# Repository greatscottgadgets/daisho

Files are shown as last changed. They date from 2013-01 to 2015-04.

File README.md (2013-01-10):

Daisho
======

Daisho is a SuperSpeed USB 3.0 FPGA platform.  The Daisho Platform is intended
for operation as a pair of components:

A mainboard with an FPGA can connect to a back-end computer via SuperSpeed USB.

A front-end board for a particular application connects to the mainboard via a
high speed parallel connector.

Front-end boards are planned that enable in-line monitoring and injection for
high speed wired communication media.

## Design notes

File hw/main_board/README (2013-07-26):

Copyright (c) 2013 Jared Boone, ShareBrained Technology, Inc.

These files are part of Daisho.

License
=======

This is a free hardware design; you can redistribute it and/or modify
it under the terms of the GNU General Public License as published by
the Free Software Foundation; either version 2, or (at your option)
any later version.

This design is distributed in the hope that it will be useful,
but WITHOUT ANY WARRANTY; without even the implied warranty of
MERCHANTABILITY or FITNESS FOR A PARTICULAR PURPOSE.  See the
GNU General Public License for more details.

You should have received a copy of the GNU General Public License
along with this design; see the file COPYING.  If not, write to
the Free Software Foundation, Inc., 51 Franklin Street,
Boston, MA 02110-1301, USA.

Hardware Notes
==============

Schematic and layout files were designed in KiCad (release 2012-05-21
bzr 3261 -stable), an open source electronic design automation package.

Order and type of copper layers:
    1_top: signal, front ("component" side, where most components are mounted)
    2_gnd: ground plane
    3_inner: signal
    4_gnd: ground plane
    5_pwr: power plane
    6_inner: signal
    7_gnd: ground plane
    8_bot: signal, back

PCB description: 8 layer PCB, 60 mil +/- 5% thickness
    LPI mask          0.4 mil
    Plating           1.2 mil   1.0 oz
    Copper      1     0.7 mil   0.5 oz
    Dielectric  1-2   4.4 mil   prepreg, 2 x 106-FR4 370
    Copper      2     1.2 mil   1.0 oz
    Dielectric  2-3   8.0 mil   core, FR4 370
    Copper      3     1.2 mil   1.0 oz
    Dielectric  3-4   7.8 mil   prepreg, 3 x 1080-FR4 370
    Copper      4     1.2 mil   1.0 oz
    Dielectric  4-5   8.0 mil   core, FR4 370
    Copper      5     1.2 mil   1.0 oz
    Dielectric  5-6   7.8 mil   prepreg, 3 x 1080-FR4 370
    Copper      6     1.2 mil   1.0 oz
    Dielectric  6-7   8.0 mil   core, FR4 370
    Copper      7     1.2 mil   1.0 oz
    Dielectric  7-8   4.4 mil   prepreg, 2 x 106-FR4 370
    Copper      8     0.7 mil   0.5 oz
    Plating           1.2 mil   1.0 oz
    LPI mask          0.4 mil

Impedance goals:
    50 Ohm +/- 10% microstrip, layers 1:2 at 7.0 mil (0.178 mm) width
    50 Ohm +/- 10% offset stripline, layers 3:2 at 6.5 mil (0.165 mm) width
    50 Ohm +/- 10% offset stripline, layers 6:7 at 6.5 mil (0.165 mm) width
    50 Ohm +/- 10% microstrip, layers 8:7 at 7.0 mil (0.178 mm) width

Soldermask
==========
Double side solder mask green
    +/- 5 mil solder mask registration

Silkscreen
==========
Double side silkscreen white
    6 mil silkscreen minimum width
    Silkscreen must be clipped by soldermask

Traces
======
5 mil (0.127 mm) min trace width
5 mil (0.127 mm) min trace isolation

Vias
====
8 mil (0.2032 mm) min via drill
17.7 mil (0.45 mm) min via pad
    4.85 mil min annular ring

Via-in-pad used in many places

Vias in pads need to be filled for assembly
    Most vias in pads are in capacitor footprints near the 780-BGA and 175-BGA

Drills
======
Drills are specified in two files:
    main_board.drl contains plated drills.
    main_board-NPTH.drl contains non-plated drills.

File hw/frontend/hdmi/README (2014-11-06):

Copyright (c) 2014 Michael Ossmann, Mike Kershaw, Jared Boone

These files are part of Daisho.

License
=======

This is a free hardware design; you can redistribute it and/or modify
it under the terms of the GNU General Public License as published by
the Free Software Foundation; either version 2, or (at your option)
any later version.

This design is distributed in the hope that it will be useful,
but WITHOUT ANY WARRANTY; without even the implied warranty of
MERCHANTABILITY or FITNESS FOR A PARTICULAR PURPOSE.  See the
GNU General Public License for more details.

You should have received a copy of the GNU General Public License
along with this design; see the file COPYING.  If not, write to
the Free Software Foundation, Inc., 51 Franklin Street,
Boston, MA 02110-1301, USA.

Hardware Notes
==============

Schematic and layout files were designed in KiCad (release 2014-10-14
bzr 5188 -product), an open source electronic design automation package.

Order and type of copper layers:
    C1F: signal, front ("component" side, where most components are mounted)
    C2: ground plane
    C3: signal
    C4: signal
    C5: ground plane
    C6B: signal, back (a few components mounted, mostly small passives)

PCB description:

    6 layer PCB, 62 mil +/- 5% thickness, using 8 layer construction

    LPI mask          0.4 mil
    Plating           1.2 mil   1.0 oz
    Copper      1     0.7 mil   0.5 oz
    Dielectric  1-2   4.4 mil   prepreg, 2 x 106-FR4 370
    Copper      2     1.2 mil   1.0 oz
    Dielectric  2-3   6.0 mil   core, FR4 370
    Copper      3     1.2 mil   1.0 oz
    Dielectric  3-4   8.1 mil   prepreg, 3 x 1080-FR4 370
                3-4  14.5 mil   core, FR4 370
                3-4   8.1 mil   prepreg, 3 x 1080-FR4 370
    Copper      4     1.2 mil   1.0 oz
    Dielectric  4-5   6.0 mil   core, FR4 370
    Copper      5     1.2 mil   1.0 oz
    Dielectric  5-6   4.4 mil   prepreg, 2 x 106-FR4 370
    Copper      6     0.7 mil   0.5 oz
    Plating           1.2 mil   1.0 oz
    LPI mask          0.4 mil

Impedance Goals
===============

50 Ohm +/- 10% microstrip, layers 1:2 and 6:5 at 0.178 mm (7.0 mil) width

100 Ohm +/- 10% differential microstrip, layers 1:2 and 6:5 at 0.127 mm (5.0 mil) width, 0.127 mm (8.0 mil) separation

Soldermask
==========

Double side solder mask green
    +/- 5 mil solder mask registration

Silkscreen
==========

Double side silkscreen white
    6 mil silkscreen minimum width
    Silkscreen must be clipped by soldermask

Traces
======

5 mil (0.127 mm) min trace width
5 mil (0.127 mm) min trace isolation

Vias
====

8 mil (0.2032 mm) min via drill
17.7 mil (0.45 mm) min via pad
    4.85 mil min annular ring

Via-in-pad used in many places

Vias in pads need to be filled for assembly
    All vias in pads are in capacitor footprints near the BGA

Drills
======

Drills are specified in two files:
    hdmi.drl contains plated drills.
    hdmi-NPTH.drl contains non-plated drills.

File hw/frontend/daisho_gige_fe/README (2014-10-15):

Copyright 2014 Mike Kershaw, Michael Ossmann

These files are part of HackRF.

This is a free hardware design; you can redistribute it and/or modify
it under the terms of the GNU General Public License as published by
the Free Software Foundation; either version 2, or (at your option)
any later version.

This design is distributed in the hope that it will be useful,
but WITHOUT ANY WARRANTY; without even the implied warranty of
MERCHANTABILITY or FITNESS FOR A PARTICULAR PURPOSE.  See the
GNU General Public License for more details.

You should have received a copy of the GNU General Public License
along with this design; see the file COPYING.  If not, write to
the Free Software Foundation, Inc., 51 Franklin Street,
Boston, MA 02110-1301, USA.

hardware notes:

Schematic and layout files were designed in KiCad, an open source electronic
design automation package.

order of copper layers:
    Copper 1:  C1F (front)
    Copper 2:  C2
    Copper 3:  C3
    Copper 4:  C1B (back)

PCB description: 4 layer PCB 0.0646 in
    Copper       1:  1 oz copper (1.4 mil)
    Dielectric 1-2:  6.7 mil prepreg
    Copper       2:  0.5 oz copper (0.7 mil)
    Dielectric 2-3:  47 mil core
    Copper       3:  0.5 oz copper (0.7 mil)
    Dielectric 3-4:  6.7 mil prepreg
    Copper       4:  1 oz copper (1.4 mil)

FR408 or similar substrate with Er=3.66 (+/- 0.1)
double side solder mask green
double side silkscreen white
6 mil min trace width and
6 mil min isolation
10 mil min drill

PCBs of this specification are available from OSH Park.

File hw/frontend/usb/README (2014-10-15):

Copyright (c) 2014 Jared Boone, ShareBrained Technology, Inc.

These files are part of Daisho.

License
=======

This is a free hardware design; you can redistribute it and/or modify
it under the terms of the GNU General Public License as published by
the Free Software Foundation; either version 2, or (at your option)
any later version.

This design is distributed in the hope that it will be useful,
but WITHOUT ANY WARRANTY; without even the implied warranty of
MERCHANTABILITY or FITNESS FOR A PARTICULAR PURPOSE.  See the
GNU General Public License for more details.

You should have received a copy of the GNU General Public License
along with this design; see the file COPYING.  If not, write to
the Free Software Foundation, Inc., 51 Franklin Street,
Boston, MA 02110-1301, USA.

Hardware Notes
==============

Schematic and layout files were designed in KiCad (release 2014-09-15
bzr 5135 -product), an open source electronic design automation package.

Order and type of copper layers:
    1_top: signal, front ("component" side, where most components are mounted)
    2: ground plane
    3: signal
    4: signal
    5: ground plane
    6_bot: signal, back (a few components mounted, mostly small passives)

PCB description:

    6 layer PCB, 62 mil +/- 5% thickness, using 8 layer construction

    LPI mask          0.4 mil
    Plating           1.2 mil   1.0 oz
    Copper      1     0.7 mil   0.5 oz
    Dielectric  1-2   4.4 mil   prepreg, 2 x 106-FR4 370
    Copper      2     1.2 mil   1.0 oz
    Dielectric  2-3   6.0 mil   core, FR4 370
    Copper      3     1.2 mil   1.0 oz
    Dielectric  3-4   8.1 mil   prepreg, 3 x 1080-FR4 370
                3-4  14.5 mil   core, FR4 370
                3-4   8.1 mil   prepreg, 3 x 1080-FR4 370
    Copper      4     1.2 mil   1.0 oz
    Dielectric  4-5   6.0 mil   core, FR4 370
    Copper      5     1.2 mil   1.0 oz
    Dielectric  5-6   4.4 mil   prepreg, 2 x 106-FR4 370
    Copper      6     0.7 mil   0.5 oz
    Plating           1.2 mil   1.0 oz
    LPI mask          0.4 mil

Impedance Goals
===============

50 Ohm +/- 10% microstrip, layers 1:2 and 6:5 at 0.178 mm (7.0 mil) width

50 Ohm +/- 10% offset stripline, layers 3:2 and 4:5 at 0.165 mm (6.5 mil) width

90 Ohm +/- 10% differential microstrip, layers 1:2 and 6:5 at 0.127 mm (5.0 mil) width, 0.127 mm (5.0 mil) separation

Soldermask
==========

Double side solder mask green
    +/- 5 mil solder mask registration

Silkscreen
==========

Double side silkscreen white
    6 mil silkscreen minimum width
    Silkscreen must be clipped by soldermask

Traces
======

5 mil (0.127 mm) min trace width
5 mil (0.127 mm) min trace isolation

Vias
====

8 mil (0.2032 mm) min via drill
17.7 mil (0.45 mm) min via pad
    4.85 mil min annular ring

Via-in-pad used in many places

Vias in pads need to be filled for assembly
    Most (all?) vias in pads are in capacitor footprints near the two 175-BGAs

Drills
======

Drills are specified in two files:
    usb_drill.xln contains plated drills.
    usb_drill_npth.xln contains non-plated drills.

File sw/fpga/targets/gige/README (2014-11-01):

This is the 1000BASE-T tapping module for the Daisho development board.

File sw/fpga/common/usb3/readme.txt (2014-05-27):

USB 3.0 Device Controller Core
------------------------------

Copyright (c) 2012-2014 Marshall H. All rights reserved.
Code in this folder is released under the terms of the simplified BSD license. 
See LICENSE.TXT for details.

Part of the Daisho project, by Michael Ossmann. http://greatscottgadgets.com/

Revision 0.1, 06/01/14
--------------------------------------------------------------------------------

Overview
--------

This is a device-side controller. This means you can use it to implement a
device talking to a host, whether it be a PC, smartphone, embedded platform...

The controller supports both USB 3.0 (5.0Gbps) and USB 2.0 (480Mbps) operation.
During enumeration if a SuperSpeed receiver is not detected, it will fall
back to 2.0 operation. 

Written in Verilog-2001, it aims to be somewhat easily adaptable to other
devices. It handles PHY strapping and initialization, LFPS with partner, link
training and receiver equalization, link layer data scrambling, elastic buffer
management, device enumeration, and block data transfer.

If you don't know anything about USB, you will have a rough time. If you have 
no experience with FPGAs, you will suffer even more. Read the USB 2.0 spec 
overview, then read about USB 3.0 functionality and how they are incorporated
into each other. Be familiar with the PHY you will use.

Capabilities
------------

The following transfer modes are supported in USB 2.0:
 - Control (intrinsic)
 - Bulk
 - Interrupt
 - Isochronous

And in USB 3.0 mode:
 - Control, Link management
 - Bulk

By default, both controllers implement one BULK IN and one BULK OUT endpoint
in addition to the default Endpoint0 for control transfers.
Additional endpoints may be added with some rework of the protocol layers.

Setting the endpoints to different transfer modes requires editing of the RTL
and also the device descriptors. Consult the USB specifications or your 
favorite search engine for details on the descriptors.

Limitations
-----------

Does not implement the following USB 2.0 functionality:
 - Power saving via SuspendM bit in ULPI
 - Low speed (1.5Mbps) is unimplemented
 - Full speed (11Mbps) is unsupported, but may work

Does not implement the following USB 3.0 functionality:
 - Compliance testing mode
 - Loopback BERT
 - Assertion of disabled data scrambling
 - Tolerance of link command glitches
 - Stream transfer mode

Details:
1. USB devices operating via the 2.0 connection should enter suspend when 
   not transmitting any data on the bus for over 3.0ms. After a total of 10ms 
   have passed, it may not draw more than the rated suspend-mode 
   current instead of the normal current draw.
   This is normally entered when the host stops sending StartOfFrame packets 
   and allows this idle condition. Due to the target platform's fixed current 
   draw this is not an option that can be supported.
2. For compliance testing, the USB 3.0 LTSSM should support a special 
   Compliance state that is entered under certain conditions detailed in the 
   USB specification, for PHY characterization. This mode is not implemented.
3. Also, USB 3.0 Loopback mode is used for benchmarking the bit error rate of
   a connection. As this is not used under normal operation, it is omitted to
   save device resources.
4. During link training, one partner may choose to signal it wishes to disable
   data scrambling. The other partner should signal its acknowledgement in the
   next training sequence. This is supported but basically untested.
5. Per the specification, link commands (which are 4 consecutive, redundant
   K-symbols) can have up to 1 invalid symbol and still be considered valid.
   To simplify functionality the controller will simply ignore these and 
   cause a sequence error. Because the protocol is robust anyway, these will
   at most cause a small performance blip in adverse environments (poor
   cabling, bad connectors, etc)
6. Streams are unsupported, if you need them in your application you are
   exceeding the expected use case

Implementation Results
----------------------

Logic utilization: 
    Approx. 1100 LEs for USB 2.0
    Approx. 6300 LEs for USB 3.0
    1 PLL
    ~40 DDR I/O
    8-10Kbyte distributed block RAM (flexible)

Targeted PHY:
    Texas Instruments TUSB1310A SuperSpeed PHY

Targeted FPGA:
    Altera Cyclone IV EP4CE30 speed grade 8

Build system:
    Altera Quartus II 13.1sp1

Porting Notes
-------------

This controller relies upon several vendor and family-specific features such as
PLLs, pipelined DDR I/O, distributed block RAM, and so on. 
Altera calls these "Megafunctions" and they are denoted by "mf_*.v" filenames.

If you are going to port this to Xilinx, Lattice, silicon then you will want to
blow these away and use the vendor's equivalent tools to get the same result.

I would recommend that you download Quartus and use the Megawizard Plug-in 
Manager to open these files so that you can see how they are supposed to work,
and how you would write wrappers for slightly different device functionality.

You're on your own here, this is not something I would recommend to an FPGA
newcomer (though arguably using this core itself is not trivial.)

Usage Considerations
--------------------

There are a number of design decisions and small things that may affect your
success using the code.

1. Device descriptors
   When running the core with only USB 2.0, edit the device descriptors so that
   the "bcdDevice" entry denotes 200h instead of 210h. The latter indicates the
   device has latent SuperSpeed functionality.
   And obviously, if you want to change the enumerated display name you'll want
   to change these. They must always match the RTL endpoint configuration.

2. I/O constraints
   It's your responsibility to constrain the top level I/O to meet your PCB
   layout. Consult your PHY datasheet, and read FPGA vendor datasheets. 
   PIPE bus I/O is fast enough that timing driven synthesis is recommended

3. SSRX/TX polarity
   The core can tell when the RX data pair has its polarity swapped and will
   configure the PHY accordingly during link training. You can swap either TX
   or RX pairs for more convenient PCB routing. Consult your PHY documentation.

4. Reset
   To reset the core to its power-on state, assert reset for at least a few
   hundred cycles (around 10 uS would be a safe bet.). Additionally, your PHY
   chip may have its own requirements for this. Reset for whichever duration is
   longest.

Troubleshooting
---------------

It's highly unlikely that things will work properly the first time. You would
be well advised to buy/lease/borrow a competent protocol analyzer. Units are
available from the major vendors, which include:

  - Teledyne Lecroy
  - Agilent
  - Tektronix
  - Total Phase

The Beagle 5000v2 from Total Phase was used for the core's development. It
runs about $5-6k. Additionally, the Lecroy Voyagyer M3x was used to test
compliance cases to identify rare problems.
Other vendors provide add-on packages for their higher end scopes, but if 
you could afford those, you'd be licensing a USB core from DesignWare 
anyhow. :)
If you have access to proper verification IP you'd probably want to test this
core against it. I welcome any changes that will make the core more robust.

If you have some knowledge of the protocols you can trigger on the RTL with
Chipscope, Signaltap, Reveal, et al. This will only give you a very narrow
window but it's better than nothing.

Contact
-------

I do not provide support! I will not answer STUPID questions or ones that
make it clear you are going to be wasting not only your own time but mine too.

Bugfixes are welcome if you can clearly demonstrate what is fixed and that no
regressions are caused.

If you successfully implement the core and ship a product I would appreciate
sending an email to let me know it worked.

usb3ipcore, at outlookdotcom

EOF

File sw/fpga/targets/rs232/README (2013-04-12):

This is the RS232 tapping module for the Daisho development board.

In order to use the USB core you must add the common/usb3 directory to the
"Project Libraries" section of the project settings dialog in Quartus II.
(This should work by default if this is checked out from github)

This is *VERY* early in the development phase - it doesn't even tap the lines.

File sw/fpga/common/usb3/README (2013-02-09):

Daisho USB Core

This is an open source USB 3.0 core.  It can be used to implement a USB device
on an FPGA with a USB 3.0 transceiver such as the TUSB1310A.  It can also
operate in USB 2.0 mode with a ULPI transceiver.

This core is being developed for the Altera Cyclone IV.  Operation on other
FPGA platforms may be possible with some work.

Planned functionality includes device (not host) operation in USB 2.0 and 3.0
(including SuperSpeed) modes.

The core is part of Project Daisho but may be used on other platforms.

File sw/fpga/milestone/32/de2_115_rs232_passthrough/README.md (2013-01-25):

Daisho Milestone 32
===================

Demonstrate RS-232 pass-through using the Terasic DE2-115 FPGA development
board and HSMC communication board.

"The platform and RS-232 front-end connected in-line with a target RS-232
link should operate in a pass-through mode such that the link functions as
it would without the platform in place."

Requirements
============

* Altera Quartus II Web Edition 12.1
* Terasic DE2-115 FPGA development board
* Terasic(?) HSMC communication board

Connections
===========

Two RS-232 DB-9 connectors are utilized:

* J6 "RS-232" on the DE2-115 board
* J3 "RS232 (0)" on the HSMC communication board

Beware that the TX and RX pinouts are different between the two connectors.

Indications
===========

Four LEDs on the DE2-115 are used to show data present on the connectors:

* LEDG0: HSMC RXD (input from external device)
* LEDG1: DE2-115 TXD (output to external device)
* LEDG2: HSMC TXD (output to external device)
* LEDG3: DE2-115 RXD (input from external device)

LEDs LEDG0 and LEDG1 should blink in unison, and LEDs LEDG2 and LEDG3 should
blink in unison.

The DE2-115 also has RXD1 and TXD1 LEDs near J6 "RS-232" that indicate data
present on the RS-232 connector.

License
=======

This sub-project is part of the Daisho project.

This program is free software; you can redistribute it and/or
modify it under the terms of the GNU General Public License
as published by the Free Software Foundation; either version 2
of the License, or (at your option) any later version.

This program is distributed in the hope that it will be useful,
but WITHOUT ANY WARRANTY; without even the implied warranty of
MERCHANTABILITY or FITNESS FOR A PARTICULAR PURPOSE.  See the
GNU General Public License for more details.

You should have received a copy of the GNU General Public License
along with this program; if not, write to the Free Software
Foundation, Inc., 51 Franklin Street, Fifth Floor, Boston, MA  02110-1301, USA.

Contact
=======

The latest version of this repository can be found at
https://github.com/mossmann/daisho

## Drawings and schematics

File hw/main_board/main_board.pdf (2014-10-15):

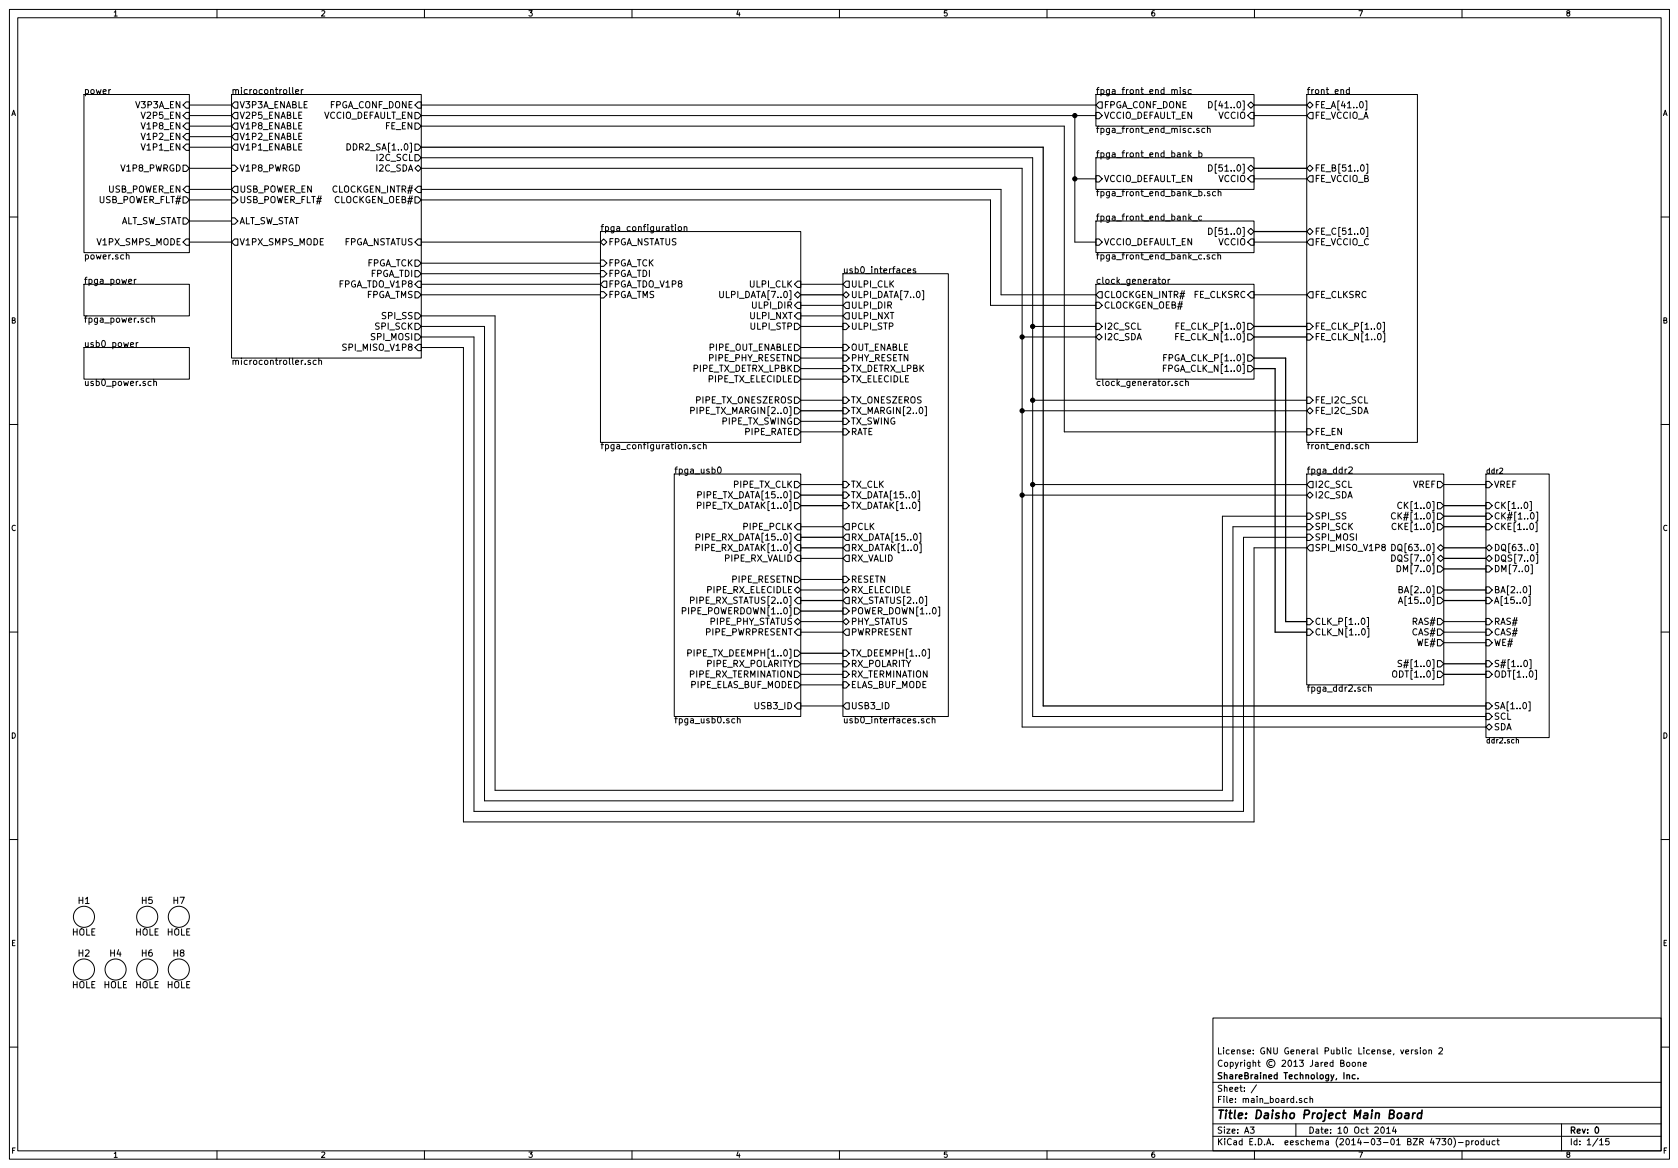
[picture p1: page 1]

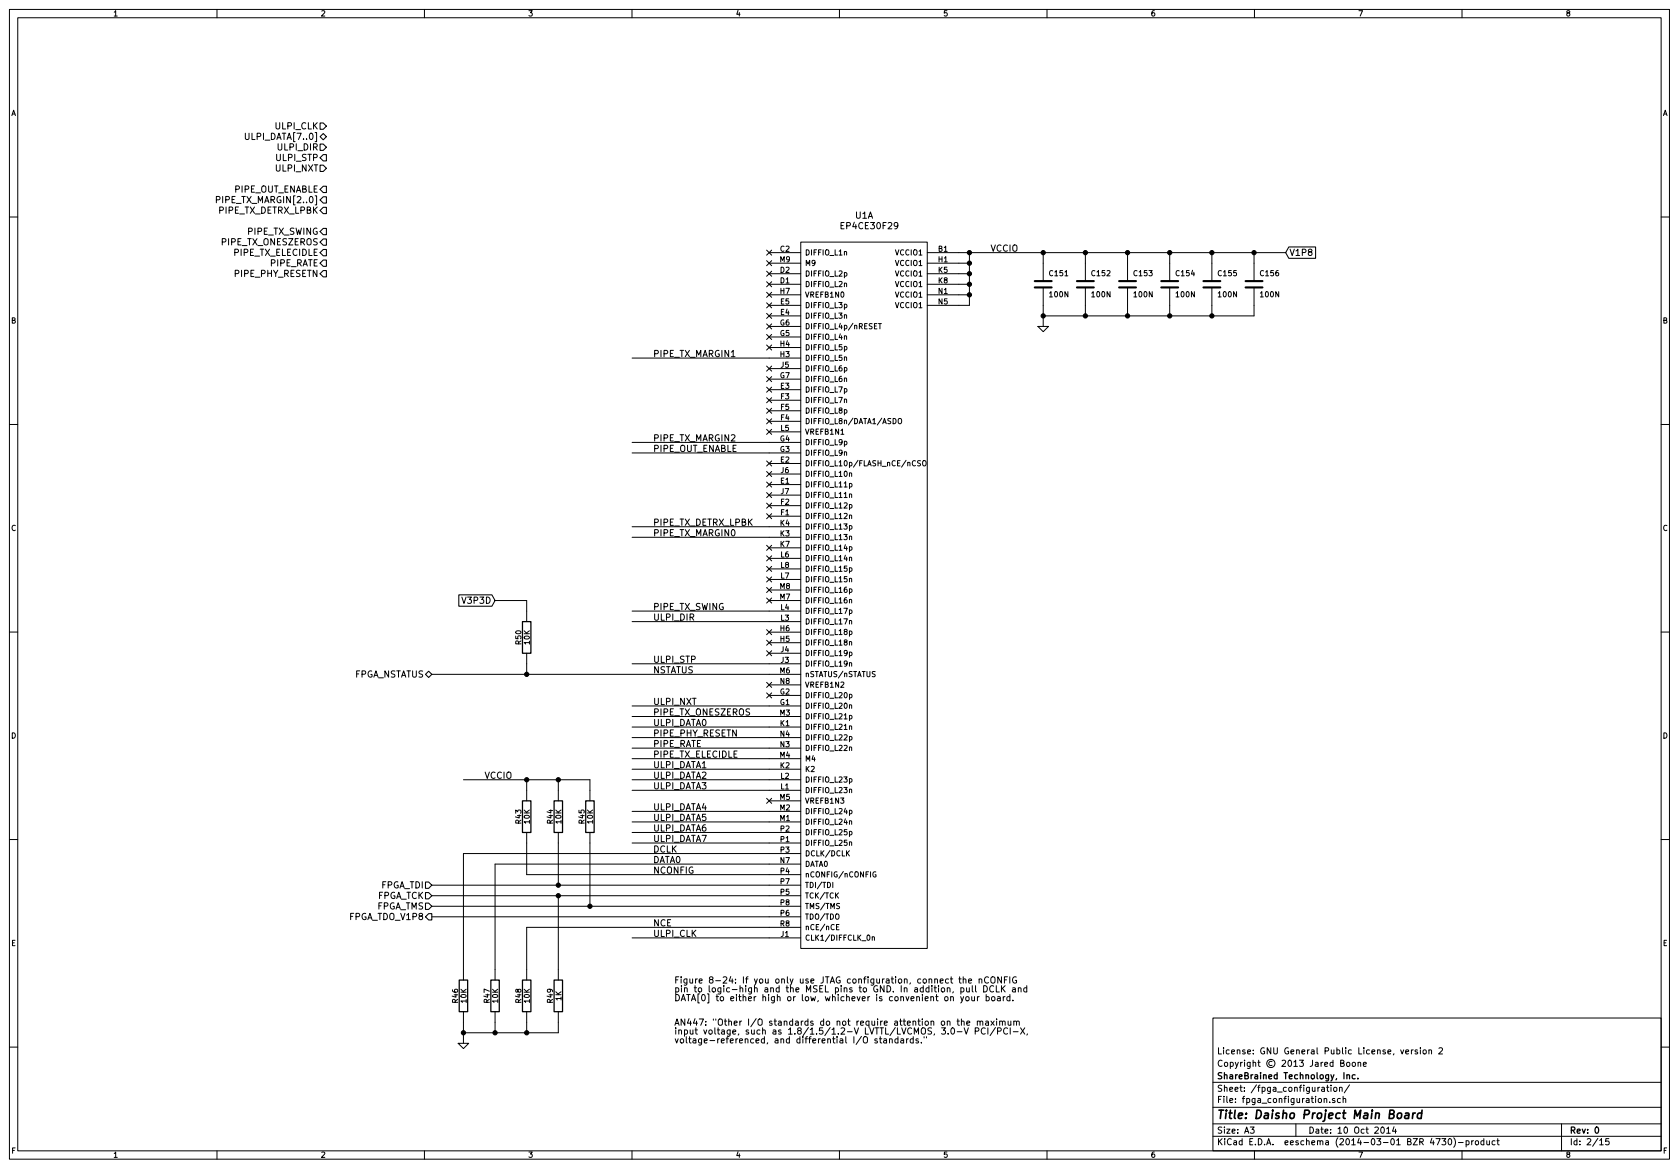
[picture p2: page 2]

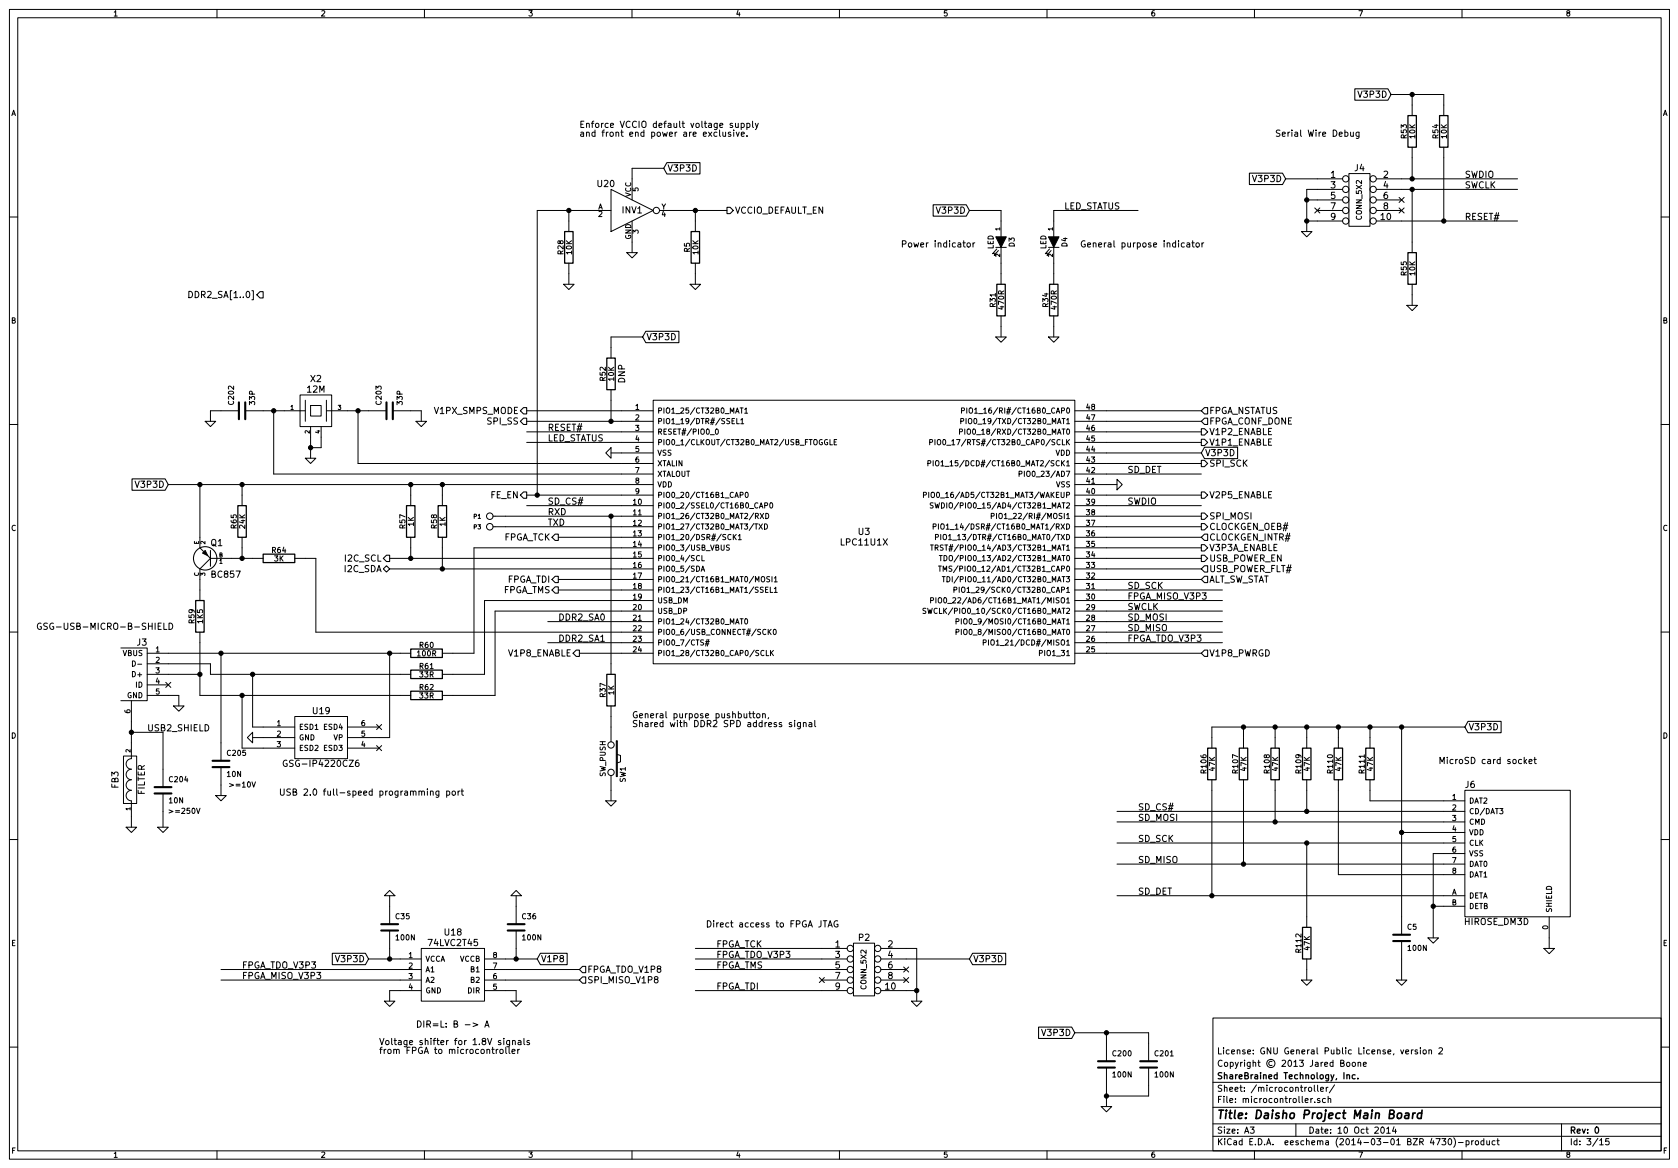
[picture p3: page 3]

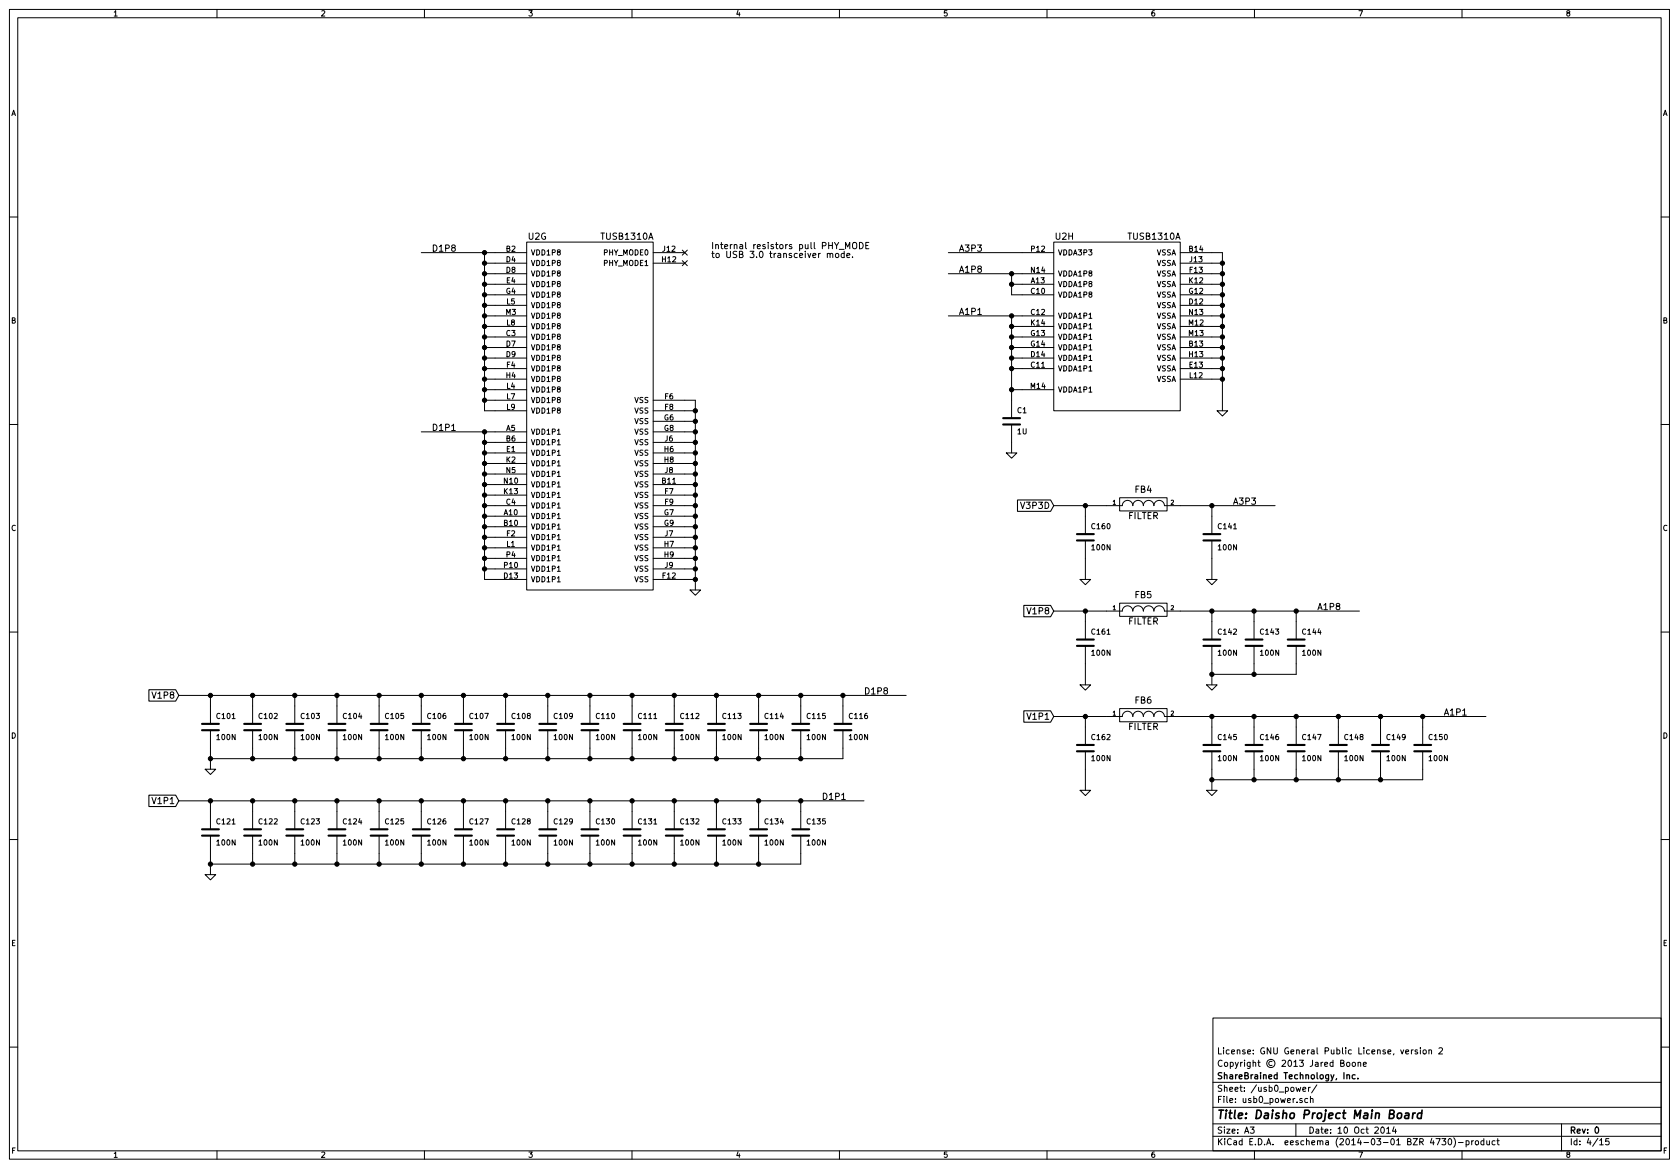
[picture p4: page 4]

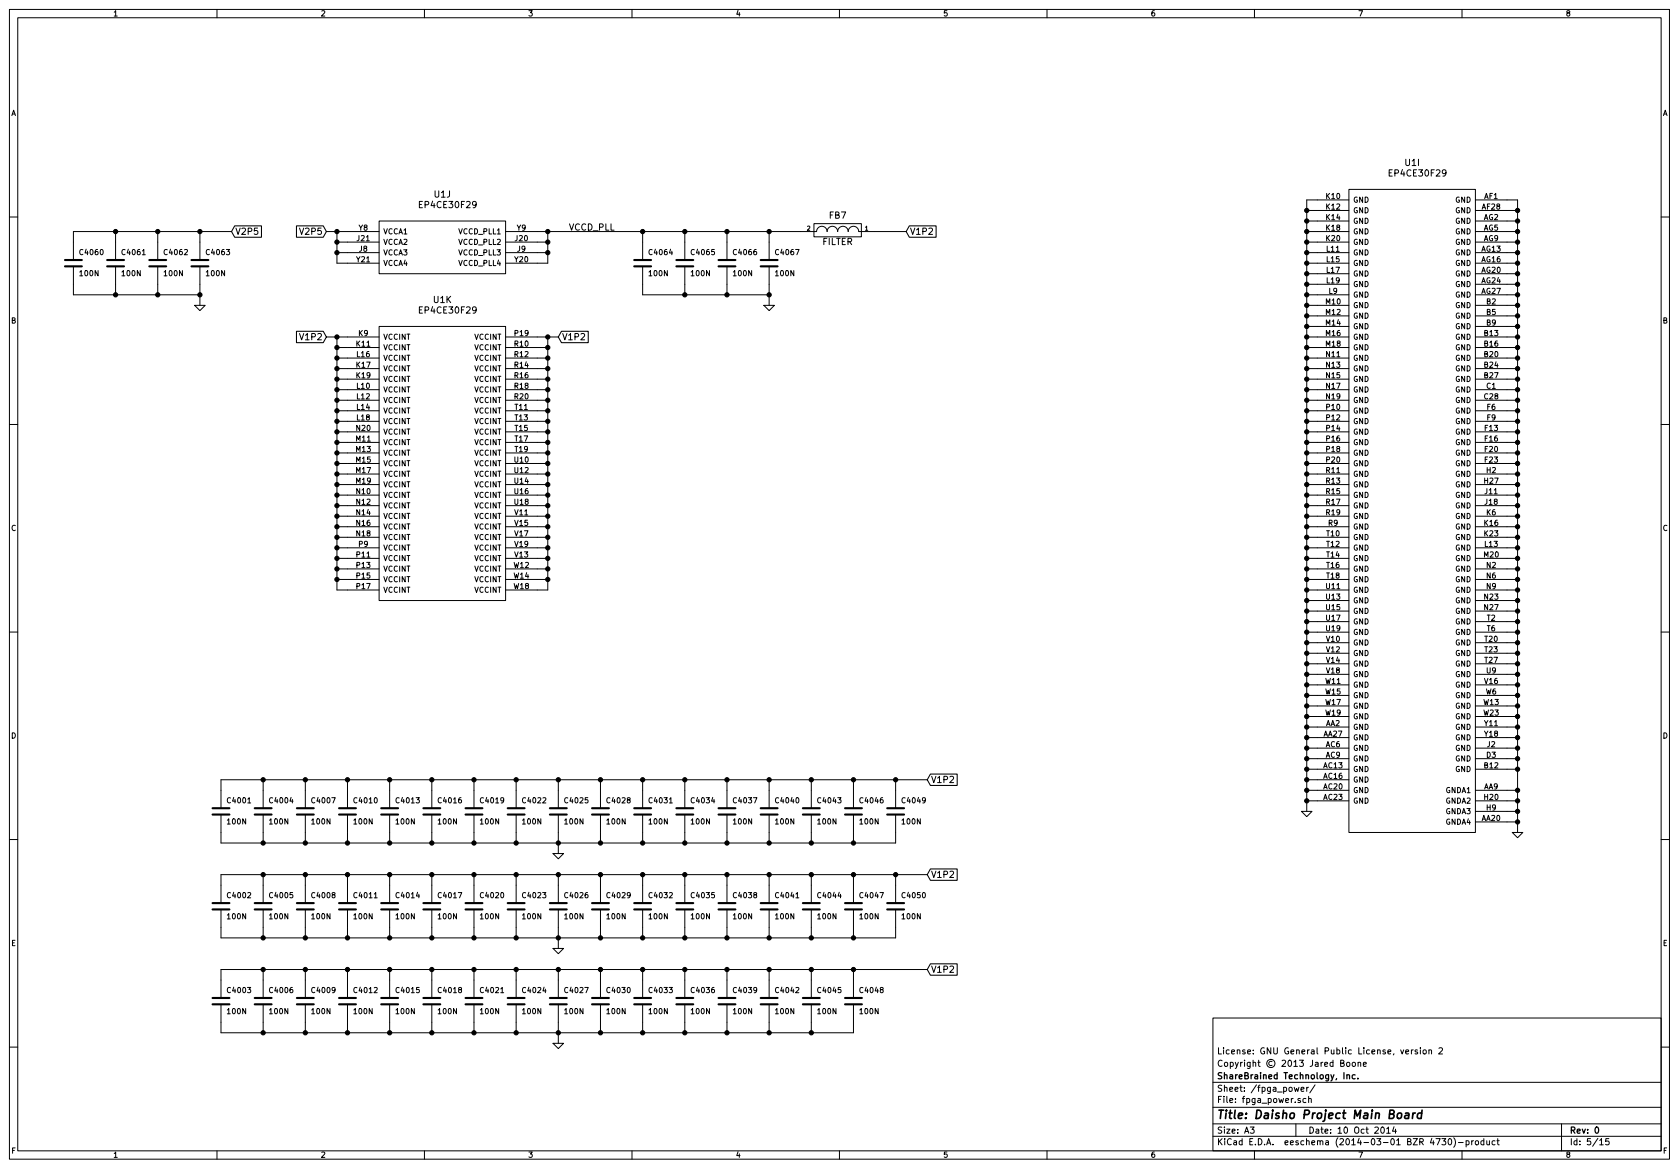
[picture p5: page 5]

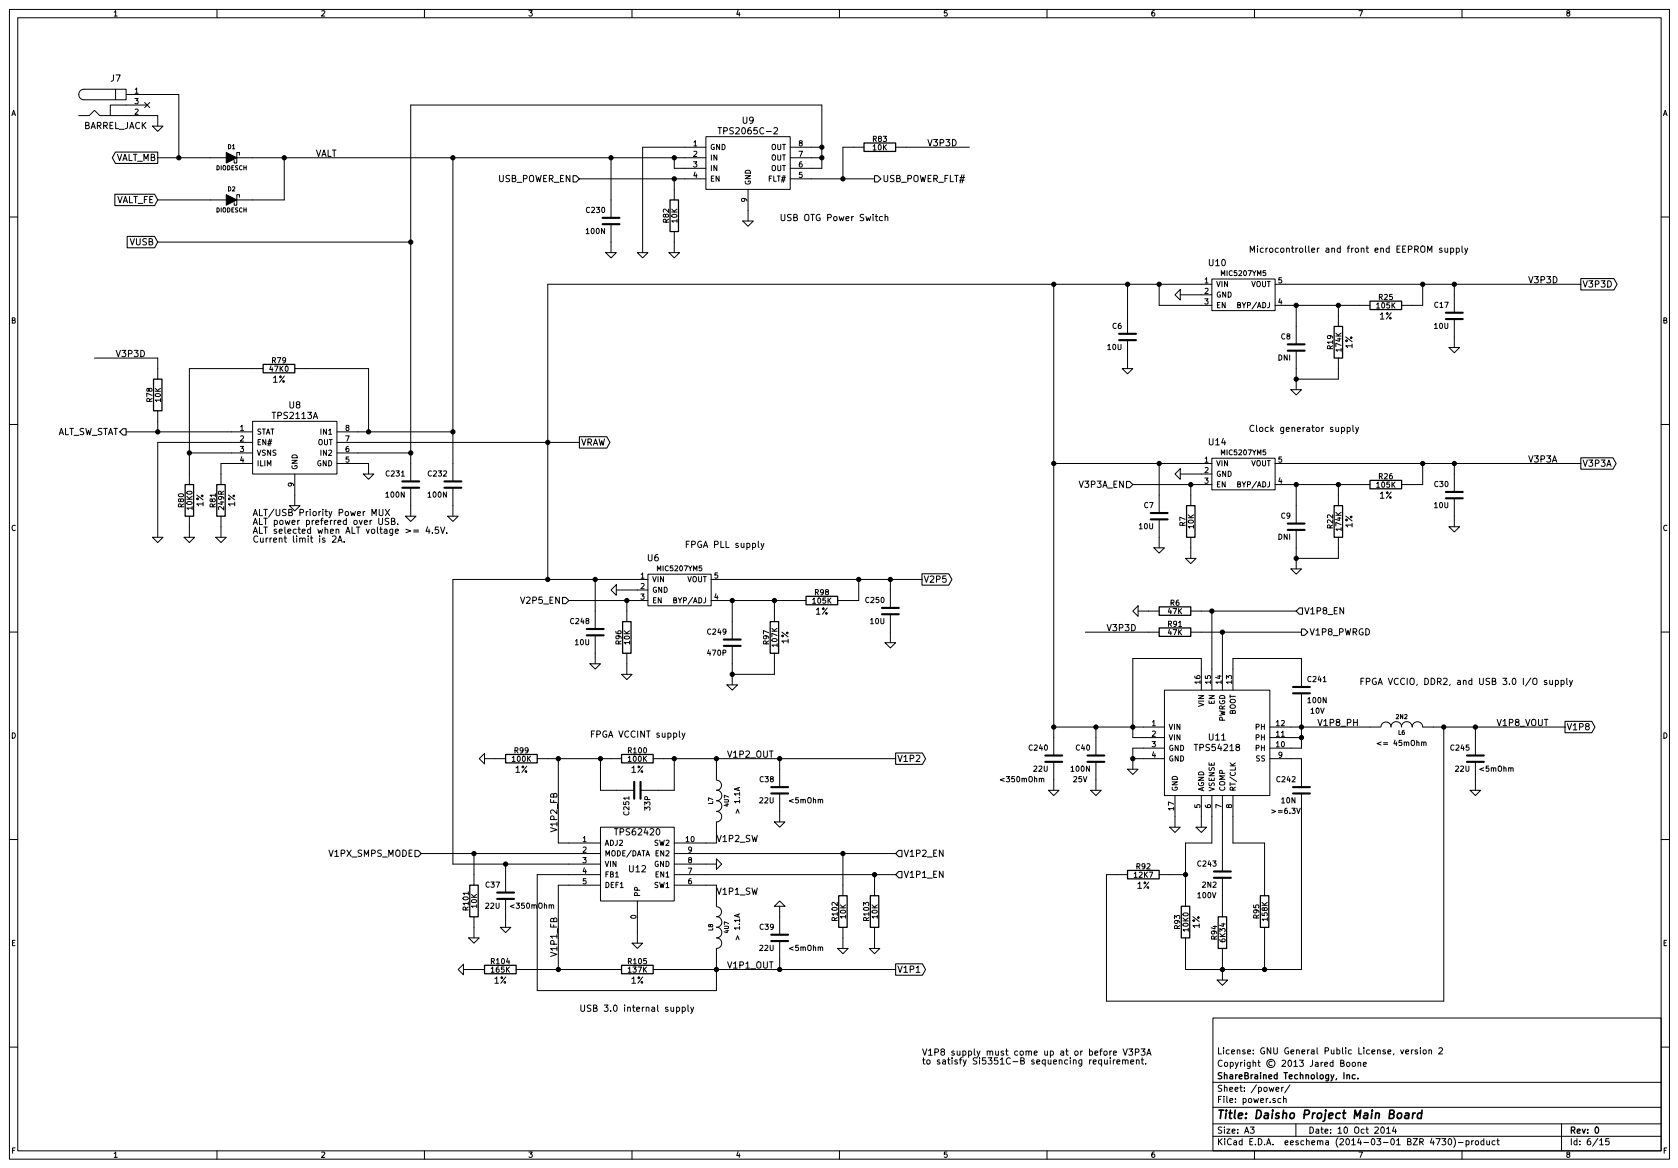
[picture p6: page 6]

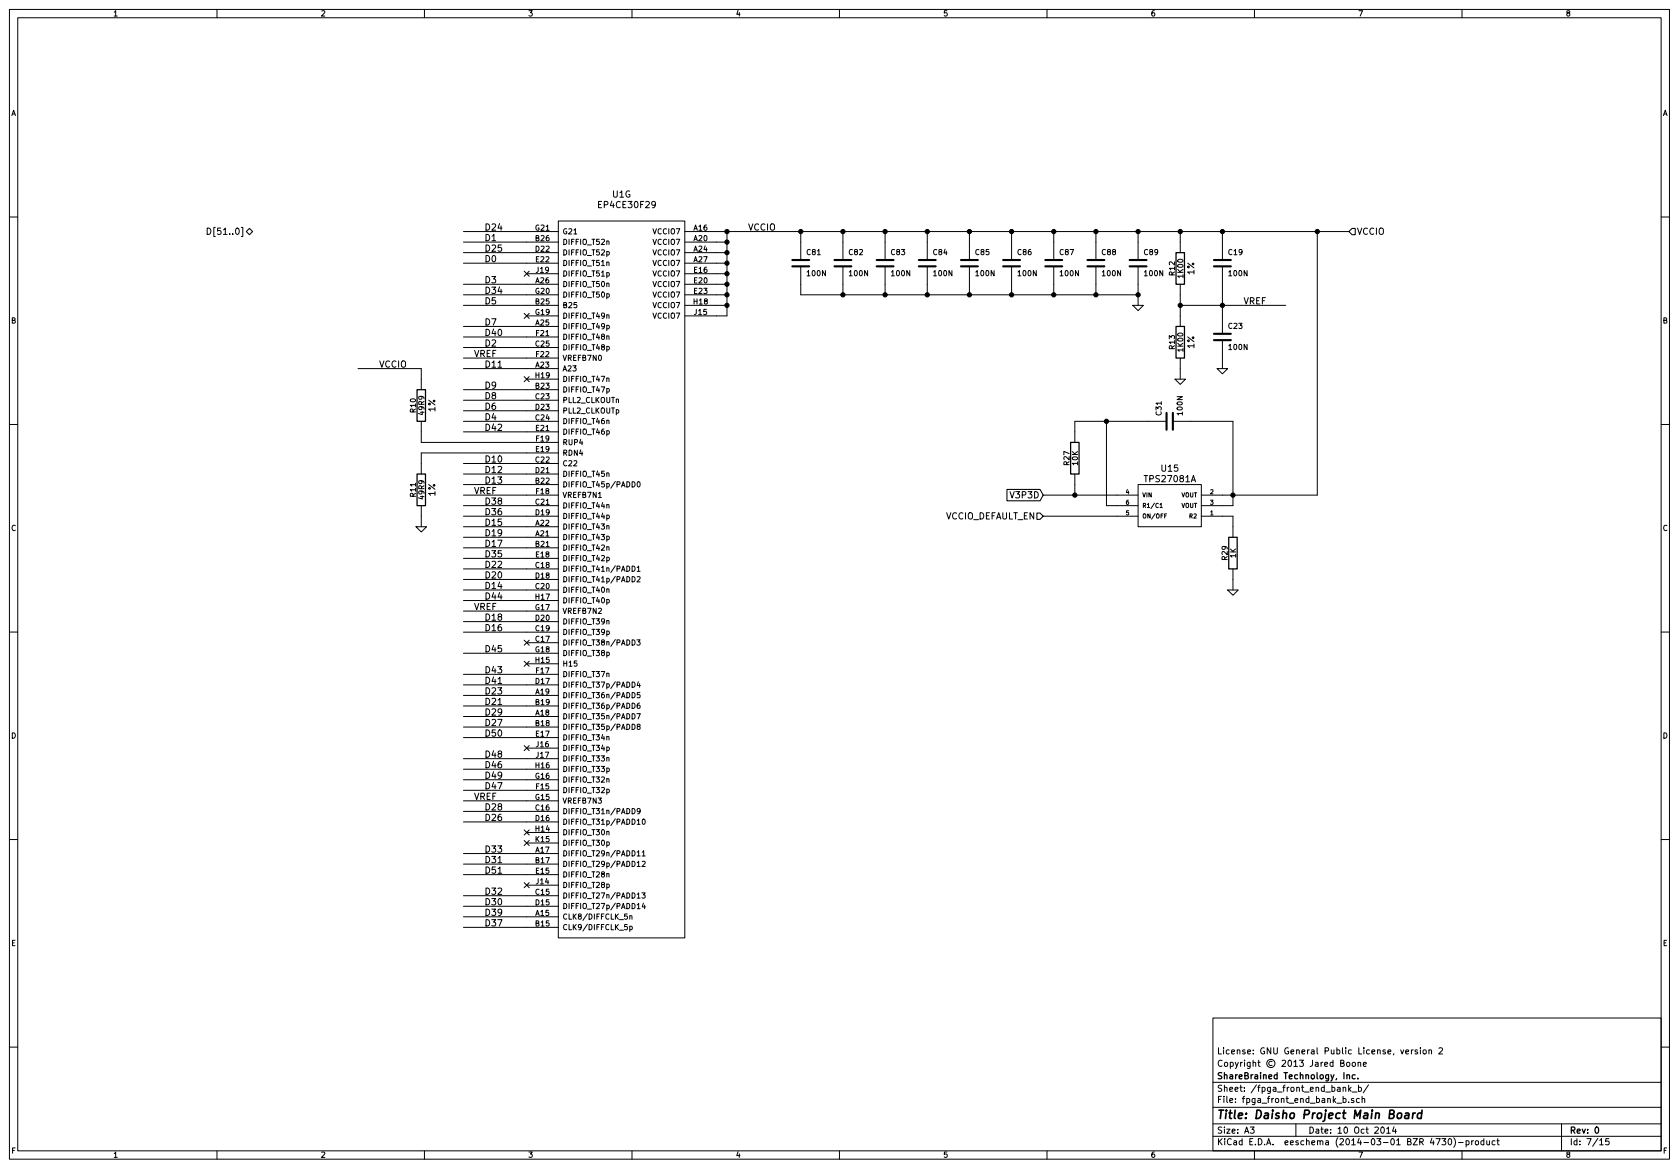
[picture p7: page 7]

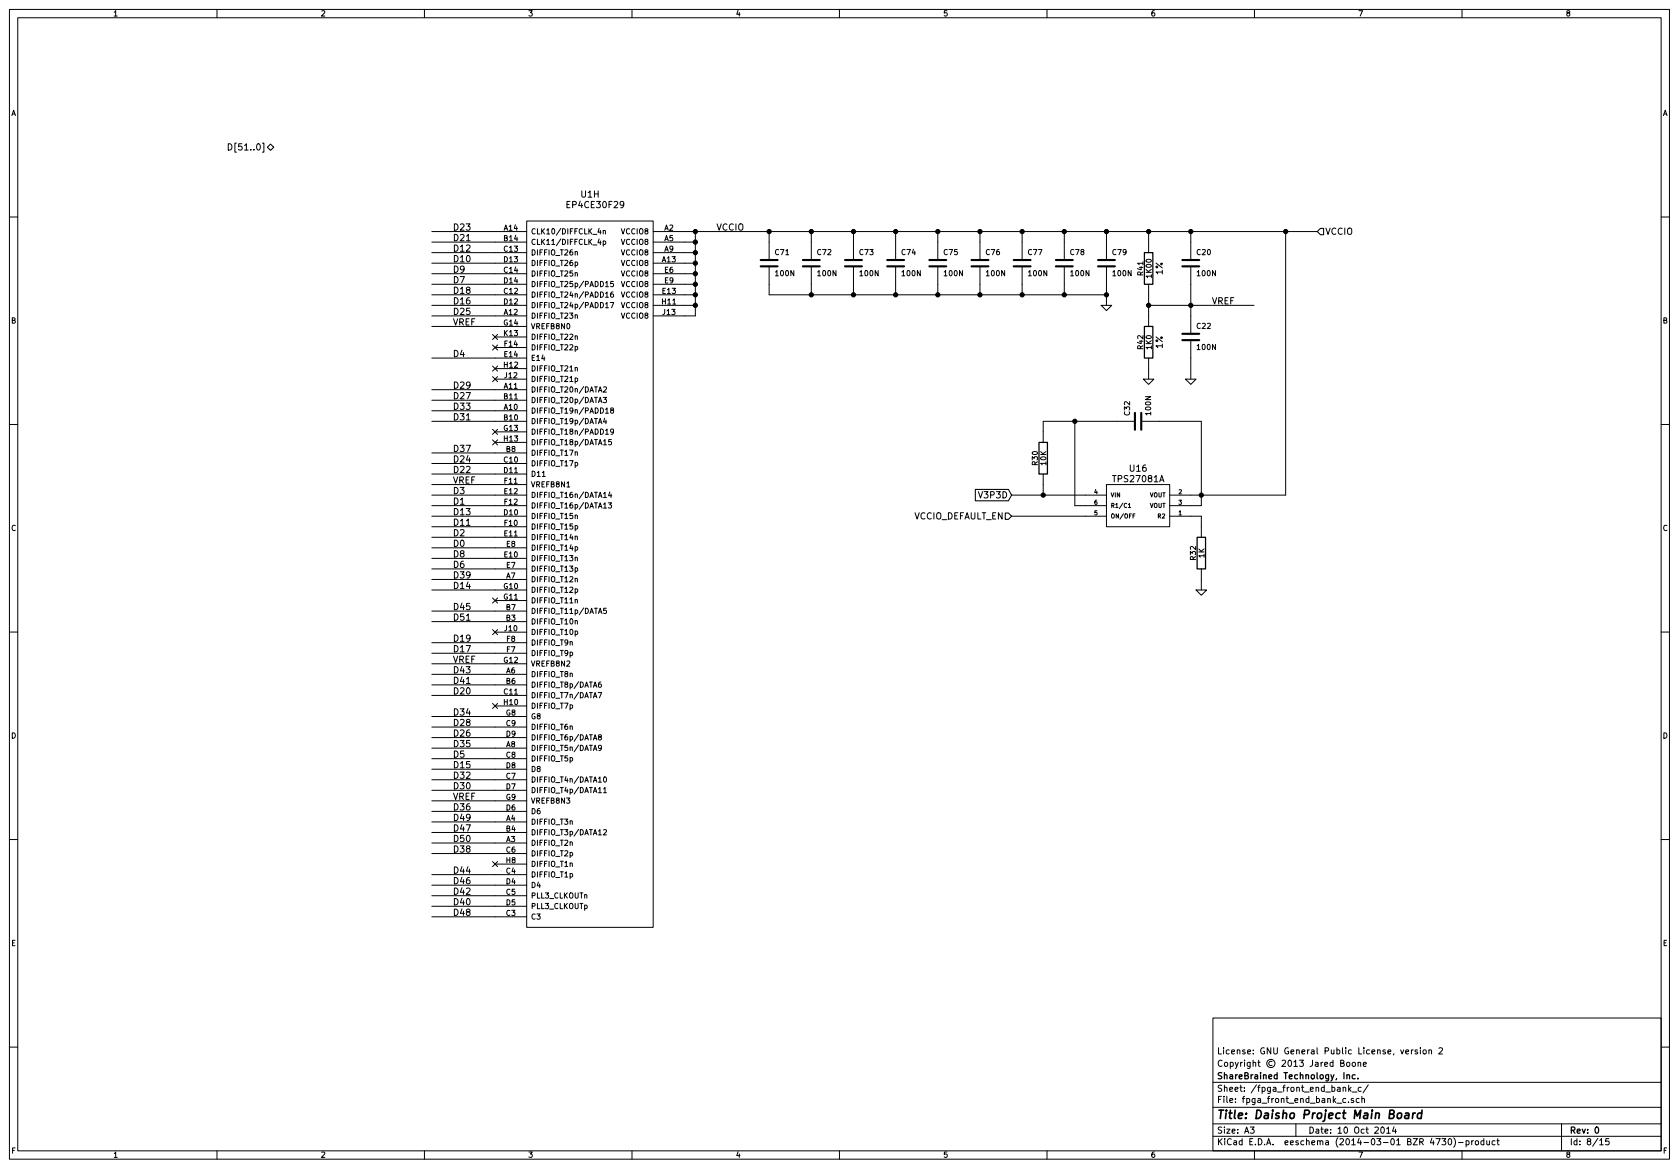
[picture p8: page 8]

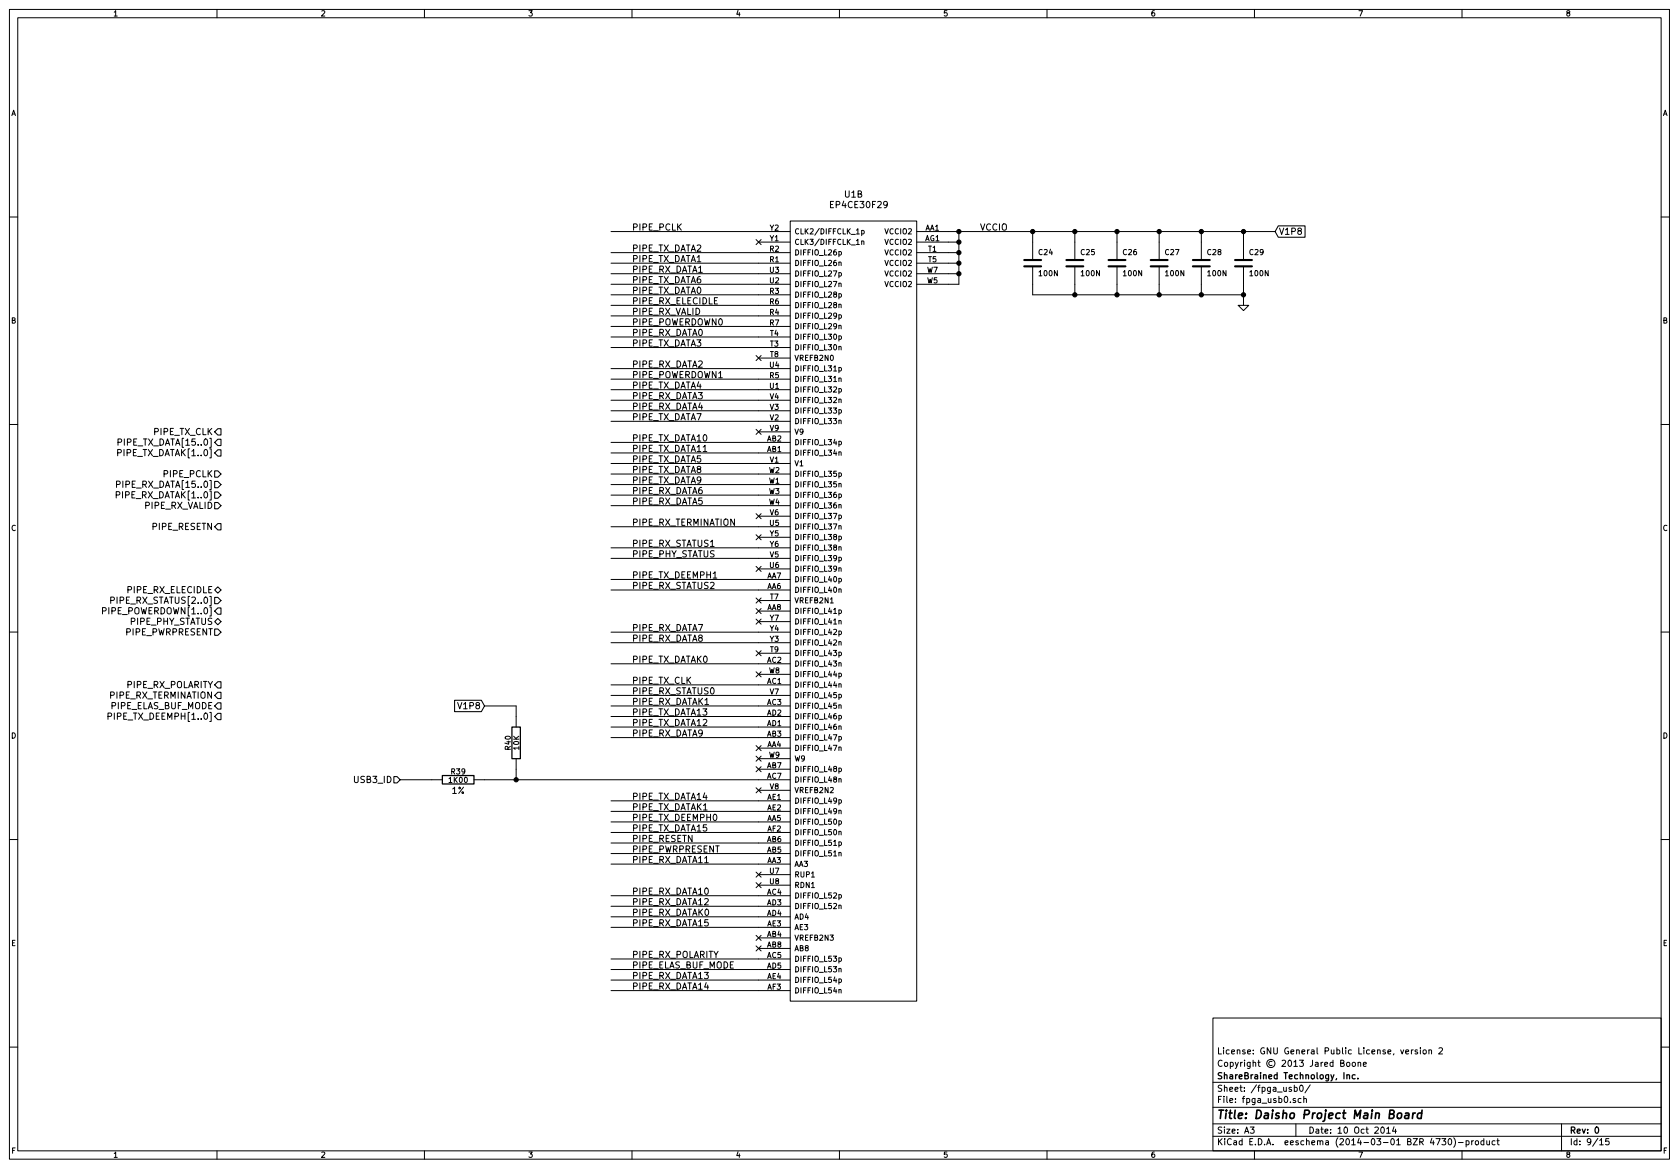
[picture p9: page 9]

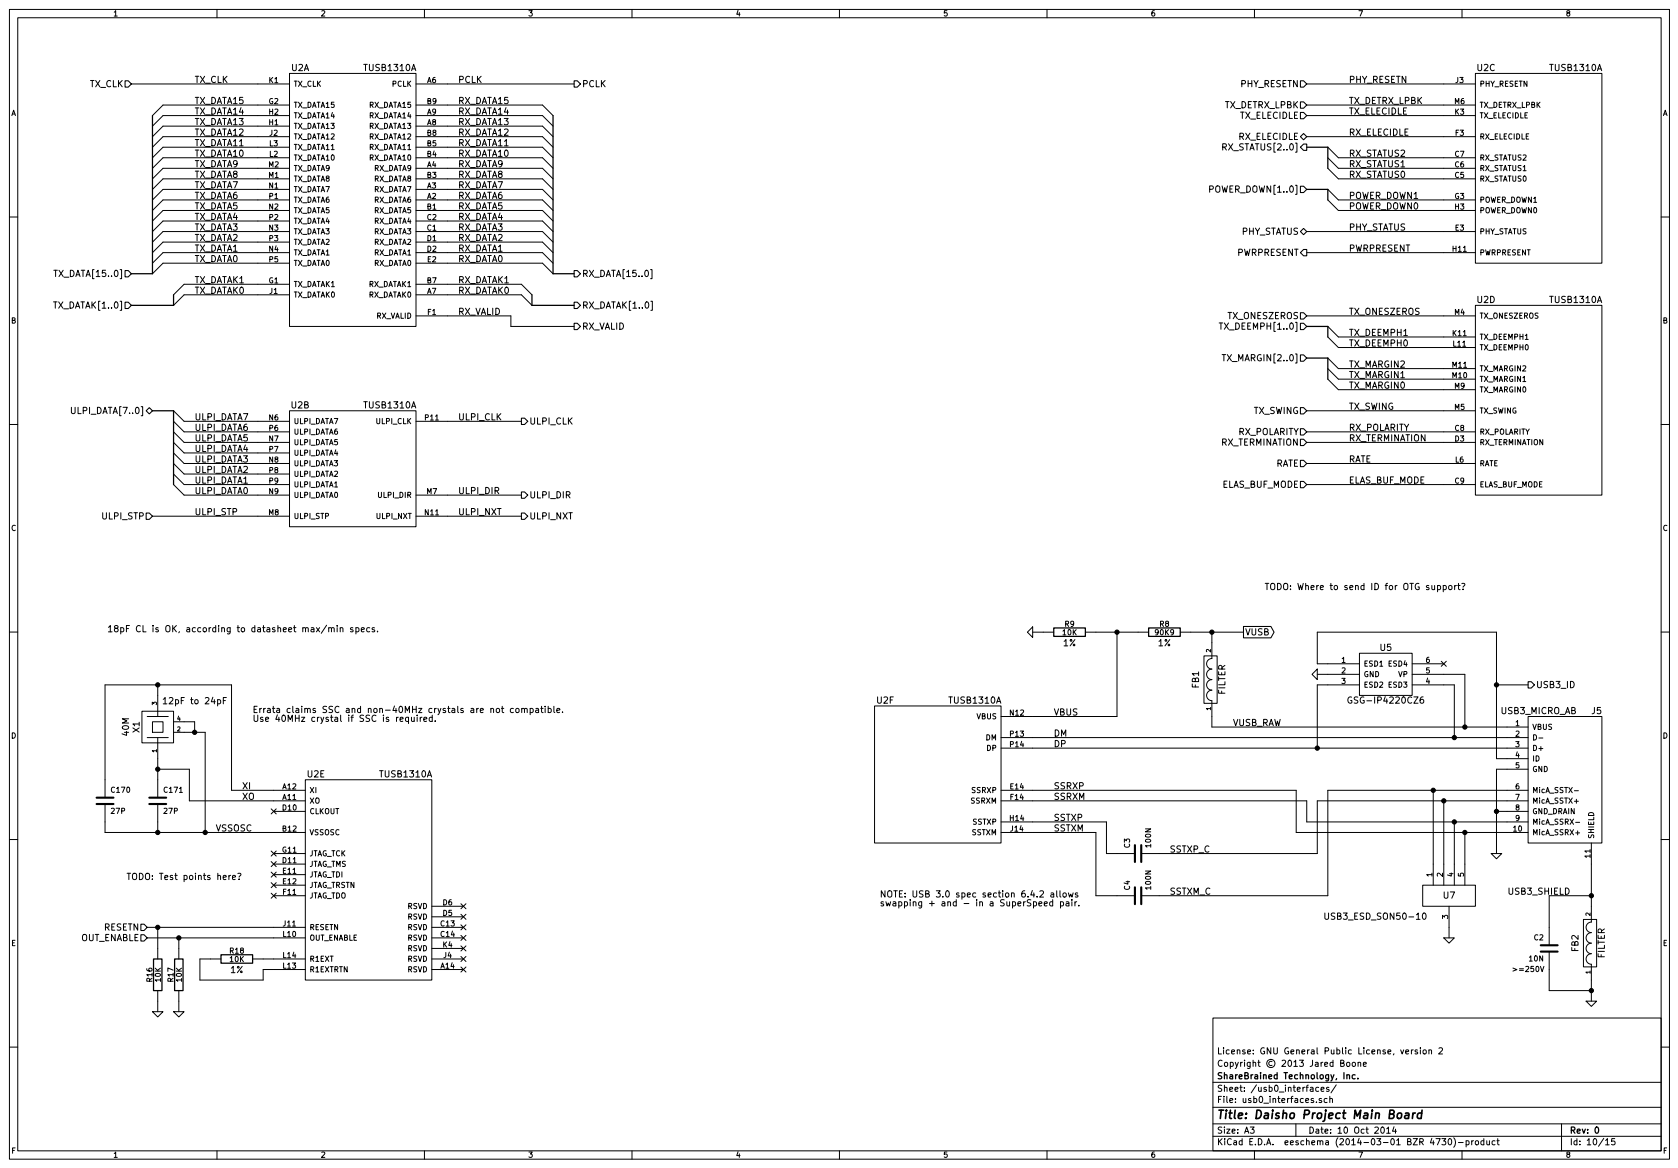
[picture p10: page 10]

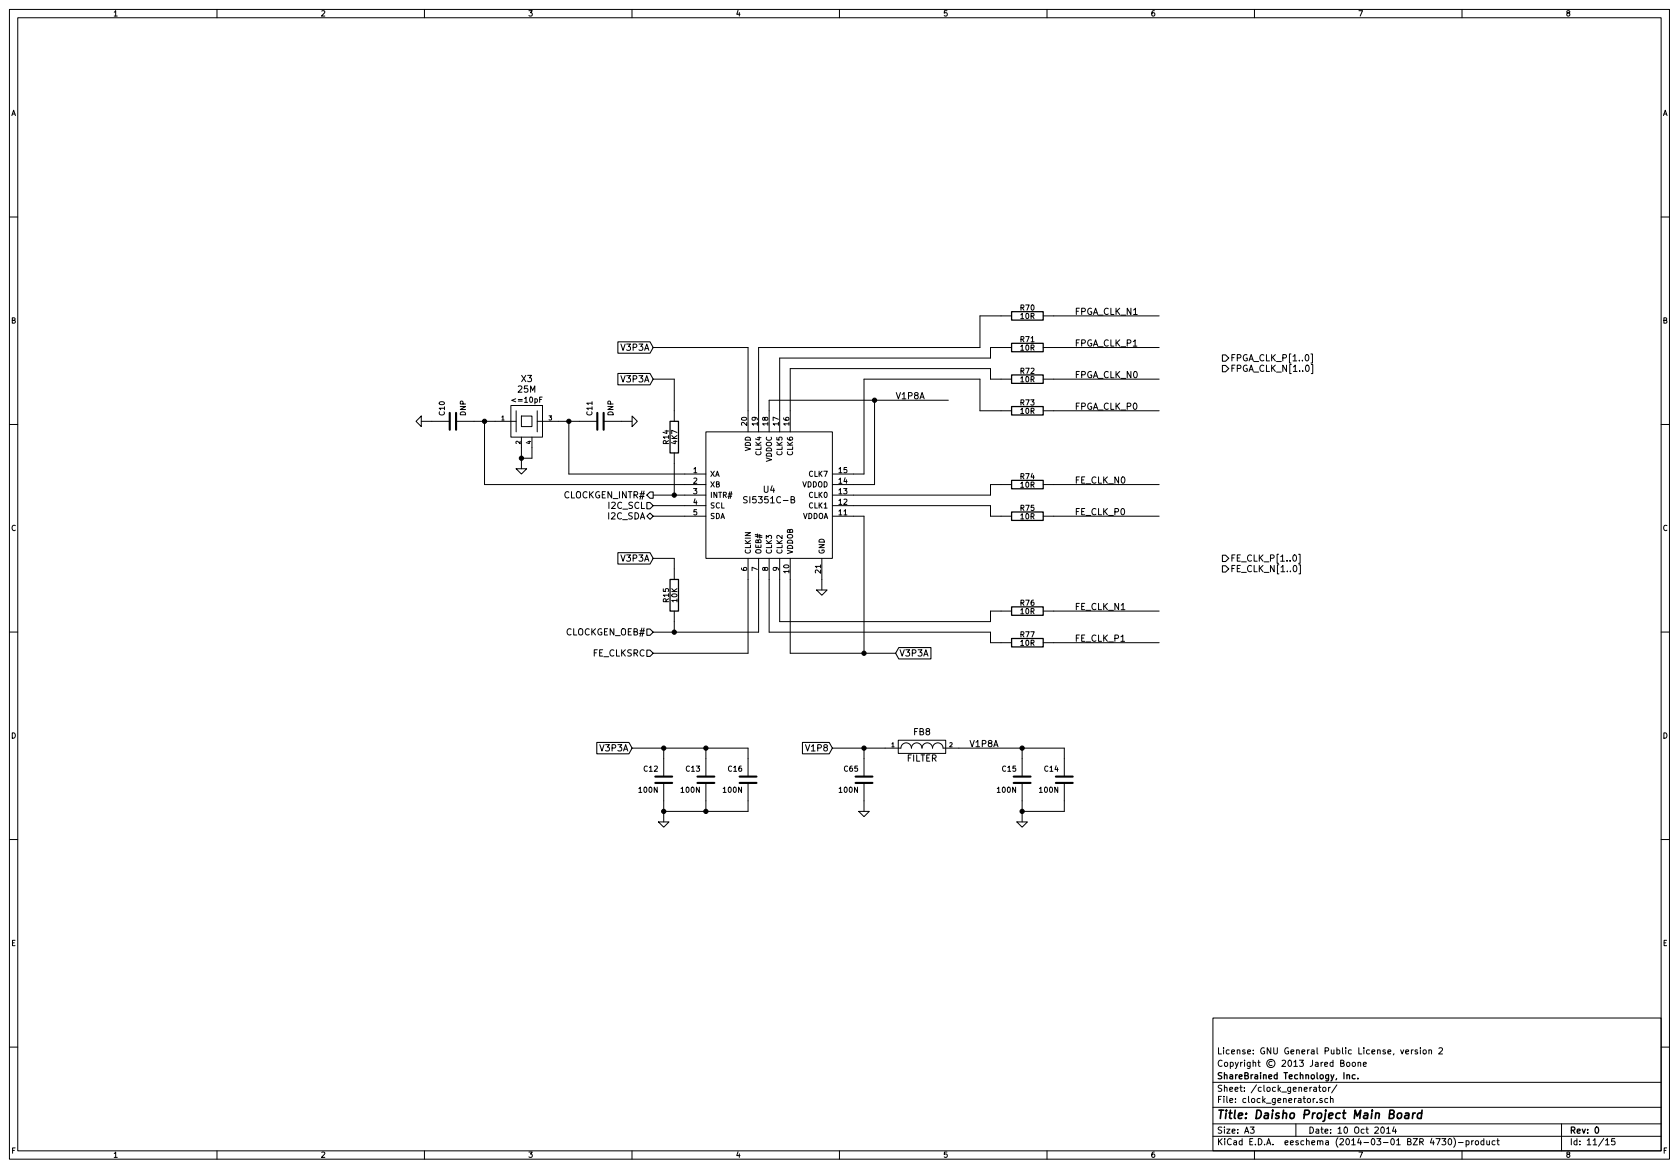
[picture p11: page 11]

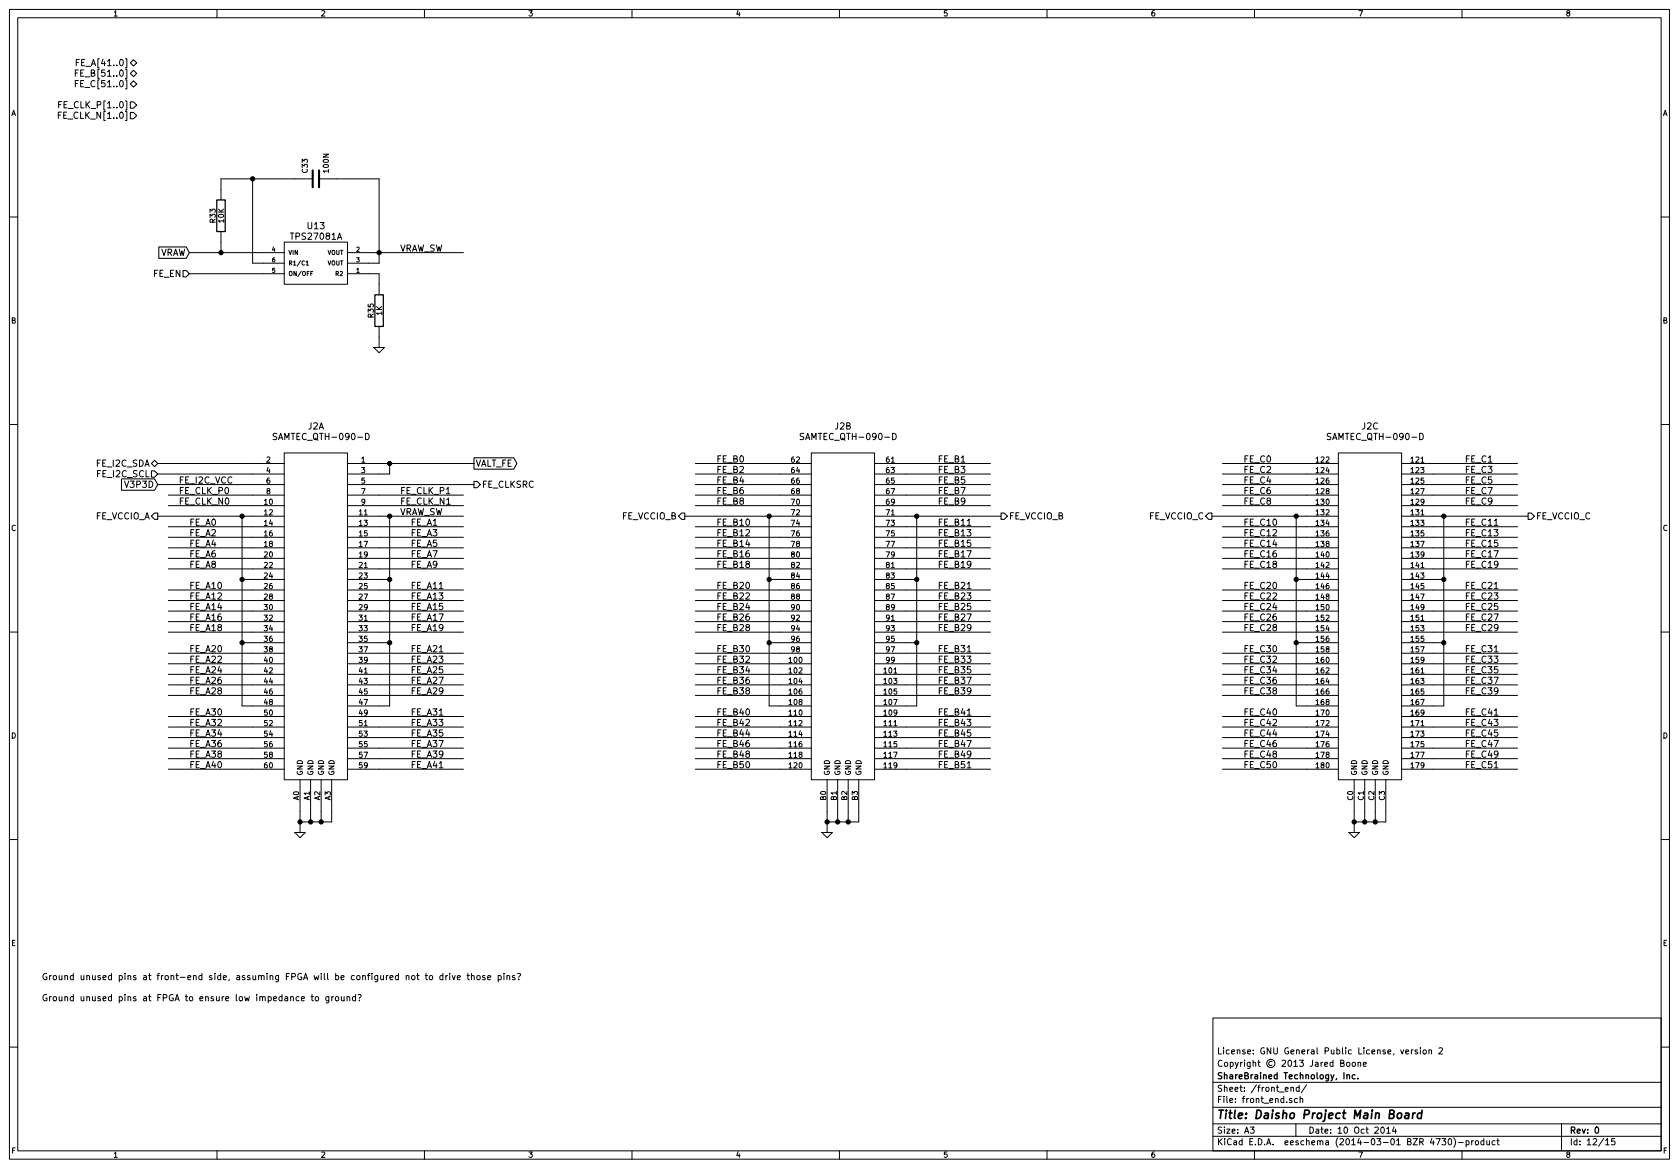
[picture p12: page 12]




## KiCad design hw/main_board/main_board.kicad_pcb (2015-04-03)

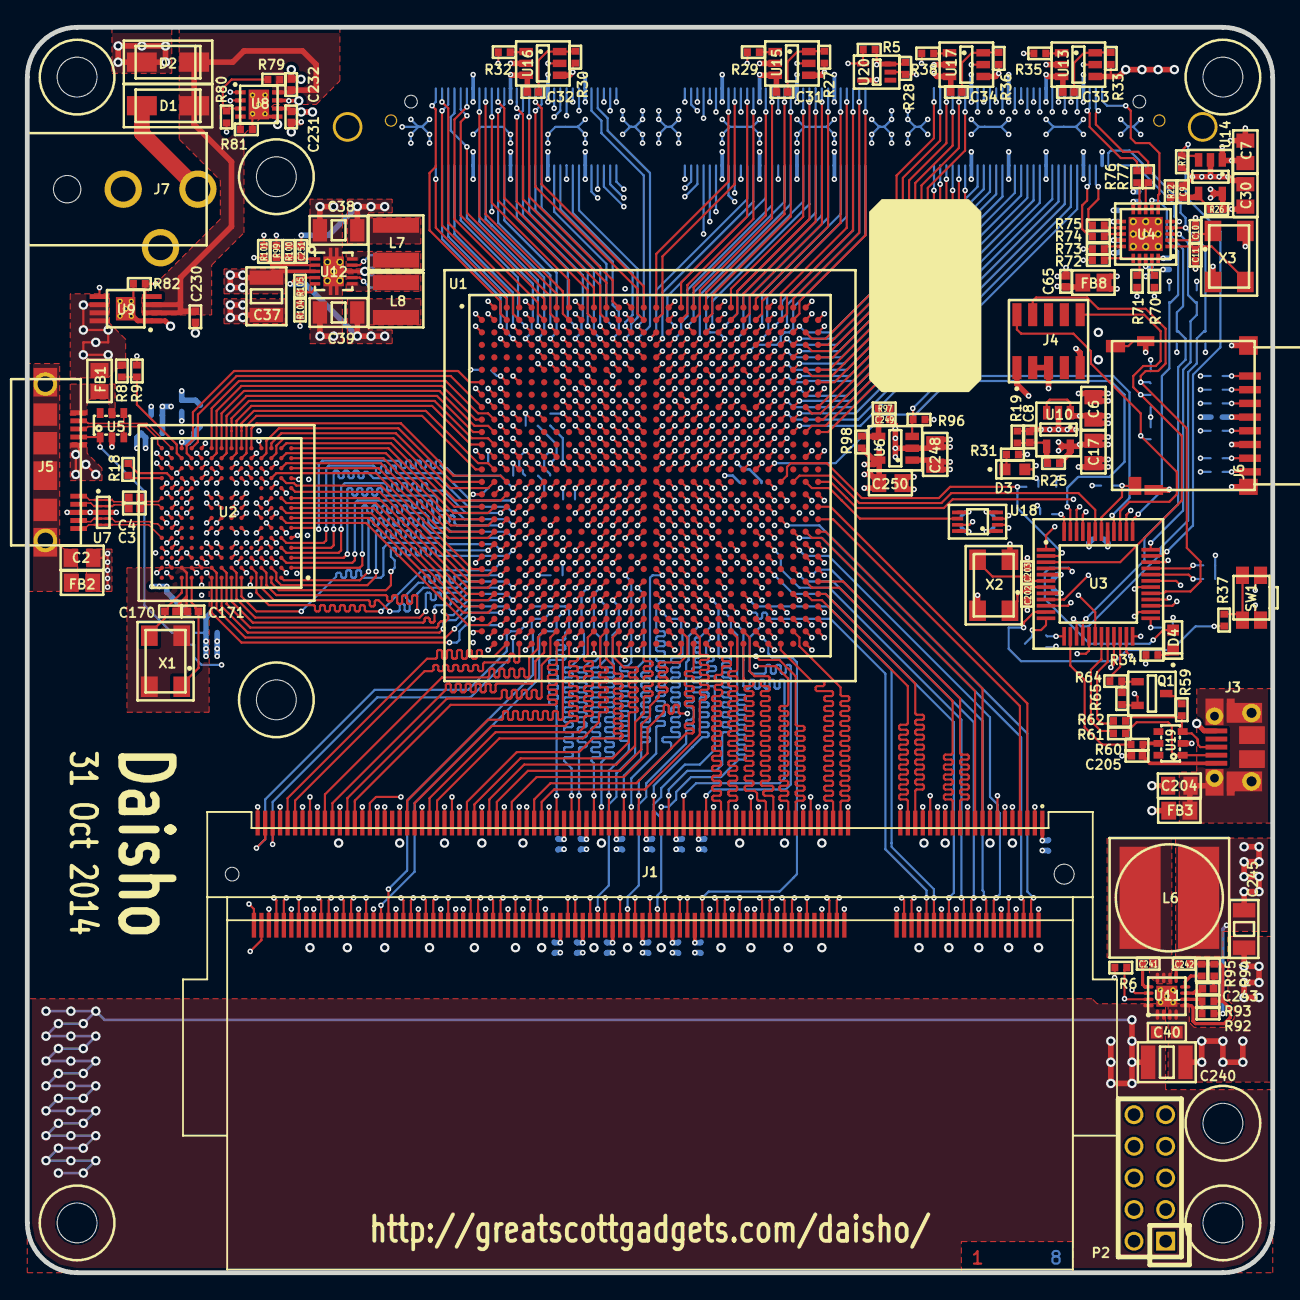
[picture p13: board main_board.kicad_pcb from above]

Board: 8 copper layers, 100.0 x 100.0 mm, 392 parts (0 on the bottom side), 487 nets.

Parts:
C1: 1U; IPC_CAPC1005X55N
C2, C204: 10N; IPC_CAPC2012X140N
C3, C4, C5, C12, C13, C14, C15, C16, C18, C19, C20, C21, C22, C23, C24, C25, C26, C27, C28, C29, C31, C32, C33, C34, C35, C36, C41, C42, C43, C44, C45, C46, C47, C48, C49, C50, C51, C52, C53, C54, C55, C56, C57, C58, C59, C60, C61, C62, C63, C64, C65, C71, C72, C73, C74, C75, C76, C77, C78, C79, C81, C82, C83, C84, C85, C86, C87, C88, C89, C90, C91, C92, C93, C94, C95, C101, C102, C103, C104, C105, C106, C107, C108, C109, C110, C111, C112, C113, C114, C115, C116, C121, C122, C123, C124, C125, C126, C127, C128, C129, C130, C131, C132, C133, C134, C135, C141, C142, C143, C144, C145, C146, C147, C148, C149, C150, C151, C152, C153, C154, C155, C156, C160, C161, C162, C180, C181, C182, C183, C184, C185, C200, C201, C210, C211, C212, C213, C214, C215, C216, C217, C218, C219, C220, C221, C222, C230, C231, C232, C241, C4001, C4002, C4003, C4004, C4005, C4006, C4007, C4008, C4009, C4010, C4011, C4012, C4013, C4014, C4015, C4016, C4017, C4018, C4019, C4020, C4021, C4022, C4023, C4024, C4025, C4026, C4027, C4028, C4029, C4030, C4031, C4032, C4033, C4034, C4035, C4036, C4037, C4038, C4039, C4040, C4041, C4042, C4043, C4044, C4045, C4046, C4047, C4048, C4049, C4050, C4060, C4061, C4062, C4063, C4064, C4065, C4066, C4067: 100N; IPC_CAPC1005X55N
C6, C7, C17, C30, C248, C250: 10U; IPC_CAPC2012X140N
C8, C9: DNI; IPC_CAPC1005X55N
C10, C11: DNP; IPC_CAPC1005X55N
C37, C240: 22U; IPC_CAPC3225X270N
C38, C39, C245: 22U; IPC_CAPC3216X180N
C40: 100N; IPC_CAPC1608X90N
C170, C171: 27P; IPC_CAPC1005X55N
C202, C203, C251: 33P; IPC_CAPC1005X55N
C205, C242: 10N; IPC_CAPC1005X55N
C243: 2N2; IPC_CAPC1005X55N
C249: 470P; IPC_CAPC1005X55N
D1, D2: DIODESCH; IPC_DIOM5226X203N
D3, D4: LED; IPC_LEDC1608X60N
FB1, FB2, FB3, FB4, FB5, FB6, FB7, FB8: FILTER; IPC_INDC2012X130N
H1, H2, H4, H5, H6, H7, H8: HOLE; GSG-HOLE126MIL
J1: DDR2_SDRAM_SODIMM; TE_1473005-4
J2: SAMTEC_QTH-090-D; SAMTEC_QTH-090-01-F-D-A
J3: GSG-USB-MICRO-B-SHIELD; GSG-USB-MICROB-FCI-10103594
J4: CONN_5X2; SULLINS_GRPB052VWQS
J5: USB3_MICRO_AB
J6: HIROSE_DM3D
J7: BARREL_JACK; CUI_PJ-102[AB]H
L6: 2N2; TDK_VLP8040
L7, L8: 4U7; GSG-NRG4026
P1, P3: CONN_1; GSG-TESTPOINT-50MIL
P2: CONN_5X2; GSG-HEADER-2x5
Q1: BC857; IPC_SOT95P230X110-3N
R1, R2, R3, R4, R10, R11: 49R9; IPC_RESC1005X40N
R5, R7, R9, R15, R16, R17, R18, R27, R30, R33, R36, R40, R43, R44, R45, R46, R47, R48, R50, R51, R52, R53, R54, R55, R78, R82, R83, R96, R101, R102, R103: 10K; IPC_RESC1005X40N
R6, R91, R106, R107, R108, R109, R110, R111, R112: 47K; IPC_RESC1005X40N
R8: 90K9; IPC_RESC1005X40N
R12, R13, R20, R21, R23, R24, R39, R41: 1K00; IPC_RESC1005X40N
R14: 4K7; IPC_RESC1005X40N
R19, R22: 174K; IPC_RESC1005X40N
R25, R26, R98: 105K; IPC_RESC1005X40N
R28, R65: 24K; IPC_RESC1005X40N
R29, R32, R35, R37, R38, R49, R57, R58: 1K; IPC_RESC1005X40N
R31, R34: 470R; IPC_RESC1005X40N
R42: 1K0; IPC_RESC1005X40N
R59: 1K5; IPC_RESC1005X40N
R60: 100R; IPC_RESC1005X40N
R61, R62: 33R; IPC_RESC1005X40N
R64: 3K; IPC_RESC1005X40N
R70, R71, R72, R73, R74, R75, R76, R77: 10R; IPC_RESC1005X40N
R79: 47K0; IPC_RESC1005X40N
R80, R93: 10K0; IPC_RESC1005X40N
R81: 249R; IPC_RESC1005X40N
R92: 12K7; IPC_RESC1005X40N
R94: 6K34; IPC_RESC1005X40N
R95: 158K; IPC_RESC1005X40N
R97: 107K; IPC_RESC1005X40N
R99, R100: 100K; IPC_RESC1005X40N
R104: 165K; IPC_RESC1005X40N
R105: 137K; IPC_RESC1005X40N
SW1: SW_PUSH; PANASONIC_EVQP7_A_C_J_L
U1: EP4CE30F29; IPC_BGA780C100P28X28_2900X2900X350
U2: TUSB1310A; IPC_BGA175C80P14X14_1200X1200X140
U3: LPC11U1X; IPC_QFP50P900X900X160-48N
U4: SI5351C-B; IPC_QFN50P400X400X90-21L
U5, U19: GSG-IP4220CZ6; GSG-SOT457
U6, U10, U14: MIC5207YM5; IPC_SOT95P280X110-5N
U7: USB3_ESD_SON50-10
U8: TPS2113A; TI_DRB_S-PVSON-N8
U9: TPS2065C-2; TI_DGN_S-PDSO-G8
U11: TPS54218; TI_RTE_S-PWQFN-N16
U12: TPS62420; TI_DRC_S-PVSON-N10
U13, U15, U16, U17: TPS27081A; IPC_SOT95P280X110-6N
U18: 74LVC2T45; IPC_SOP50P310X100-8N
U20: INV1; IPC_SOT65P210X110-5N
X1: 40M; IPC_OSCCC320X500X105-4N
X2: 12M; IPC_OSCCC320X500X105-4N
X3: 25M; IPC_OSCCC320X500X105-4N

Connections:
/clock_generator/CLOCKGEN_INTR#: R14.2, U3.36, U4.3
/clock_generator/CLOCKGEN_OEB#: R15.2, U3.37, U4.7
/clock_generator/FE_CLKSRC: J2.5, U4.6
/clock_generator/FE_CLK_N0: J2.10, R74.2
/clock_generator/FE_CLK_N1: J2.9, R76.2
/clock_generator/FE_CLK_P0: J2.8, R75.2
/clock_generator/FE_CLK_P1: J2.7, R77.2
/clock_generator/V1P8A: C14.1, C15.1, FB8.2, U4.14, U4.18
/ddr2/A0: J1.102, U1.AE13
/ddr2/A1: J1.101, U1.AB15
/ddr2/A2: J1.100, U1.AF18
/ddr2/A3: J1.99, U1.AD15
/ddr2/A4: J1.98, U1.AF14
/ddr2/A5: J1.97, U1.AE15
/ddr2/A6: J1.94, U1.AE14
/ddr2/A7: J1.92, U1.AG19
/ddr2/A8: J1.93, U1.AF19
/ddr2/A9: J1.91, U1.AE20
/ddr2/A10: J1.105, U1.AB13
/ddr2/A11: J1.90, U1.AD14
/ddr2/A12: J1.89, U1.AD19
/ddr2/A13: J1.116, U1.AH10
/ddr2/A14: J1.86, U1.AC17
/ddr2/A15: J1.84, U1.AE16
/ddr2/BA0: J1.107, U1.AD12
/ddr2/BA1: J1.106, U1.AH12
/ddr2/BA2: J1.85, U1.AF21
/ddr2/CAS#: J1.113, U1.AC11
/ddr2/CK0: J1.30, U1.AD22
/ddr2/CK1: J1.164, U1.AE7
/ddr2/CK#0: J1.32, U1.AE22
/ddr2/CK#1: J1.166, U1.AE8
/ddr2/CKE0: J1.79, U1.AF23
/ddr2/CKE1: J1.80, U1.AG23
/ddr2/DM0: J1.10, U1.AB28
/ddr2/DM1: J1.26, U1.AB24
/ddr2/DM2: J1.52, U1.AF25
/ddr2/DM3: J1.67, U1.AH19
/ddr2/DM4: J1.130, U1.AC15
/ddr2/DM5: J1.147, U1.AF8
/ddr2/DM6: J1.170, U1.AB9
/ddr2/DM7: J1.185, U1.AE6
/ddr2/DQ0: J1.5, U1.U28
/ddr2/DQ1: J1.7, U1.V28
/ddr2/DQ2: J1.17, U1.W28
/ddr2/DQ3: J1.19, U1.W27
/ddr2/DQ4: J1.4, U1.V25
/ddr2/DQ5: J1.6, U1.W26
/ddr2/DQ6: J1.14, U1.Y26
/ddr2/DQ7: J1.16, U1.AB27
/ddr2/DQ8: J1.23, U1.AC28
/ddr2/DQ9: J1.25, U1.AC27
/ddr2/DQ10: J1.35, U1.AD28
/ddr2/DQ11: J1.37, U1.AD27
/ddr2/DQ12: J1.20, U1.AB26
/ddr2/DQ13: J1.22, U1.Y24
/ddr2/DQ14: J1.36, U1.AD26
/ddr2/DQ15: J1.38, U1.AE28
/ddr2/DQ16: J1.43, U1.AG26
/ddr2/DQ17: J1.45, U1.AH25
/ddr2/DQ18: J1.55, U1.AF22
/ddr2/DQ19: J1.57, U1.AE21
/ddr2/DQ20: J1.44, U1.AE25
/ddr2/DQ21: J1.46, U1.AE24
/ddr2/DQ22: J1.56, U1.AF20
/ddr2/DQ23: J1.58, U1.AD18
/ddr2/DQ24: J1.61, U1.AG22
/ddr2/DQ25: J1.63, U1.AH22
/ddr2/DQ26: J1.73, U1.AG21
/ddr2/DQ27: J1.75, U1.AH21
/ddr2/DQ28: J1.62, U1.AF24
/ddr2/DQ29: J1.64, U1.AH23
/ddr2/DQ30: J1.74, U1.AE19
/ddr2/DQ31: J1.76, U1.AD17
/ddr2/DQ32: J1.123, U1.AG18
/ddr2/DQ33: J1.125, U1.AH18
/ddr2/DQ34: J1.135, U1.AG17
/ddr2/DQ35: J1.137, U1.AH17
/ddr2/DQ36: J1.124, U1.AE17
/ddr2/DQ37: J1.126, U1.AF16
/ddr2/DQ38: J1.134, U1.AF15
/ddr2/DQ39: J1.136, U1.AB16
/ddr2/DQ40: J1.141, U1.AG12
/ddr2/DQ41: J1.143, U1.AH11
/ddr2/DQ42: J1.151, U1.AG11
/ddr2/DQ43: J1.153, U1.AG10
/ddr2/DQ44: J1.140, U1.AE12
/ddr2/DQ45: J1.142, U1.AE11
/ddr2/DQ46: J1.152, U1.AE9
/ddr2/DQ47: J1.154, U1.AF10
/ddr2/DQ48: J1.157, U1.AH8
/ddr2/DQ49: J1.159, U1.AG8
/ddr2/DQ50: J1.173, U1.AH7
/ddr2/DQ51: J1.175, U1.AG7
/ddr2/DQ52: J1.158, U1.AF9
/ddr2/DQ53: J1.160, U1.AD10
/ddr2/DQ54: J1.174, U1.AC8
/ddr2/DQ55: J1.176, U1.AF7
/ddr2/DQ56: J1.179, U1.AH6
/ddr2/DQ57: J1.181, U1.AG6
/ddr2/DQ58: J1.189, U1.AH4
/ddr2/DQ59: J1.191, U1.AH3
/ddr2/DQ60: J1.180, U1.AD8
/ddr2/DQ61: J1.182, U1.AF6
/ddr2/DQ62: J1.192, U1.AF4
/ddr2/DQ63: J1.194, U1.AG3
/ddr2/DQS0: J1.13, U1.T25
/ddr2/DQS1: J1.31, U1.AF27
/ddr2/DQS2: J1.51, U1.AF26
/ddr2/DQS3: J1.70, U1.AE18
/ddr2/DQS4: J1.131, U1.AF17
/ddr2/DQS5: J1.148, U1.AF11
/ddr2/DQS6: J1.169, U1.AE10
/ddr2/DQS7: J1.188, U1.AD7
/ddr2/ODT0: J1.114, U1.AF12
/ddr2/ODT1: J1.119, U1.AE5
/ddr2/RAS#: J1.108, U1.AC14
/ddr2/S#0: J1.110, U1.AF13
/ddr2/S#1: J1.115, U1.AC10
/ddr2/VREF: C180.2, C181.1, C182.2, C183.1, C184.2, C185.1, C222.1, J1.1, R20.2, R21.1, U1.AA12, U1.AA14, U1.AA15, U1.AA24, U1.AB11, U1.AB20, U1.AC18, U1.R24, U1.U23, U1.U24, U1.Y10, U1.Y17
/ddr2/WE#: J1.109, U1.AD11
/fpga_configuration/DATA0: R47.1, U1.N7
/fpga_configuration/DCLK: R46.1, U1.P3
/fpga_configuration/FPGA_NSTATUS: R50.2, U1.M6, U3.48
/fpga_configuration/FPGA_TCK: P2.1, R49.1, U1.P5, U3.13
/fpga_configuration/FPGA_TDI: P2.9, R44.2, U1.P7, U3.17
/fpga_configuration/FPGA_TDO_V1P8: U1.P6, U18.7
/fpga_configuration/FPGA_TMS: P2.5, R45.2, U1.P8, U3.18
/fpga_configuration/NCE: R48.1, U1.R8
/fpga_configuration/NCONFIG: R43.2, U1.P4
/fpga_configuration/PIPE_RATE: U1.N3, U2.L6
/fpga_configuration/PIPE_TX_DETRX_LPBK: U1.K4, U2.M6
/fpga_configuration/PIPE_TX_ELECIDLE: U1.M4, U2.K3
/fpga_configuration/PIPE_TX_MARGIN0: U1.K3, U2.M9
/fpga_configuration/PIPE_TX_MARGIN1: U1.H3, U2.M10
/fpga_configuration/PIPE_TX_MARGIN2: U1.G4, U2.M11
/fpga_configuration/PIPE_TX_ONESZEROS: U1.M3, U2.M4
/fpga_configuration/PIPE_TX_SWING: U1.L4, U2.M5
/fpga_configuration/ULPI_CLK: U1.J1, U2.P11
/fpga_configuration/ULPI_DATA0: U1.K1, U2.N9
/fpga_configuration/ULPI_DATA1: U1.K2, U2.P9
/fpga_configuration/ULPI_DATA2: U1.L2, U2.P8
/fpga_configuration/ULPI_DATA3: U1.L1, U2.N8
/fpga_configuration/ULPI_DATA4: U1.M2, U2.P7
/fpga_configuration/ULPI_DATA5: U1.M1, U2.N7
/fpga_configuration/ULPI_DATA6: U1.P2, U2.P6
/fpga_configuration/ULPI_DATA7: U1.P1, U2.N6
/fpga_configuration/ULPI_DIR: U1.L3, U2.M7
/fpga_configuration/ULPI_NXT: U1.G1, U2.N11
/fpga_configuration/ULPI_STP: U1.J3, U2.M8
/fpga_ddr2/CLK_N0: R72.2, U1.AH14
/fpga_ddr2/CLK_N1: R70.2, U1.Y28
/fpga_ddr2/CLK_P0: R73.2, U1.AG14
/fpga_ddr2/CLK_P1: R71.2, U1.Y27
/fpga_ddr2/SPI_MISO_V1P8: U1.R27, U18.6
/fpga_ddr2/SPI_MOSI: U1.R28, U3.38
/fpga_ddr2/SPI_SCK: U1.R26, U3.43
/fpga_ddr2/SPI_SS: R52.2, U1.R25, U3.2
/fpga_front_end_bank_b/D0: J2.62, U1.E22
/fpga_front_end_bank_b/D1: J2.61, U1.B26
/fpga_front_end_bank_b/D2: J2.64, U1.C25
/fpga_front_end_bank_b/D3: J2.63, U1.A26
/fpga_front_end_bank_b/D4: J2.66, U1.C24
/fpga_front_end_bank_b/D5: J2.65, U1.B25
/fpga_front_end_bank_b/D6: J2.68, U1.D23
/fpga_front_end_bank_b/D7: J2.67, U1.A25
/fpga_front_end_bank_b/D8: J2.70, U1.C23
/fpga_front_end_bank_b/D9: J2.69, U1.B23
/fpga_front_end_bank_b/D10: J2.74, U1.C22
/fpga_front_end_bank_b/D11: J2.73, U1.A23
/fpga_front_end_bank_b/D12: J2.76, U1.D21
/fpga_front_end_bank_b/D13: J2.75, U1.B22
/fpga_front_end_bank_b/D14: J2.78, U1.C20
/fpga_front_end_bank_b/D15: J2.77, U1.A22
/fpga_front_end_bank_b/D16: J2.80, U1.C19
/fpga_front_end_bank_b/D17: J2.79, U1.B21
/fpga_front_end_bank_b/D18: J2.82, U1.D20
/fpga_front_end_bank_b/D19: J2.81, U1.A21
/fpga_front_end_bank_b/D20: J2.86, U1.D18
/fpga_front_end_bank_b/D21: J2.85, U1.B19
/fpga_front_end_bank_b/D22: J2.88, U1.C18
/fpga_front_end_bank_b/D23: J2.87, U1.A19
/fpga_front_end_bank_b/D24: J2.90, U1.G21
/fpga_front_end_bank_b/D25: J2.89, U1.D22
/fpga_front_end_bank_b/D26: J2.92, U1.D16
/fpga_front_end_bank_b/D27: J2.91, U1.B18
/fpga_front_end_bank_b/D28: J2.94, U1.C16
/fpga_front_end_bank_b/D29: J2.93, U1.A18
/fpga_front_end_bank_b/D30: J2.98, U1.D15
/fpga_front_end_bank_b/D31: J2.97, U1.B17
/fpga_front_end_bank_b/D32: J2.100, U1.C15
/fpga_front_end_bank_b/D33: J2.99, U1.A17
/fpga_front_end_bank_b/D34: J2.102, U1.G20
/fpga_front_end_bank_b/D35: J2.101, U1.E18
/fpga_front_end_bank_b/D36: J2.104, U1.D19
/fpga_front_end_bank_b/D37: J2.103, U1.B15
/fpga_front_end_bank_b/D38: J2.106, U1.C21
/fpga_front_end_bank_b/D39: J2.105, U1.A15
/fpga_front_end_bank_b/D40: J2.110, U1.F21
/fpga_front_end_bank_b/D41: J2.109, U1.D17
/fpga_front_end_bank_b/D42: J2.112, U1.E21
/fpga_front_end_bank_b/D43: J2.111, U1.F17
/fpga_front_end_bank_b/D44: J2.114, U1.H17
/fpga_front_end_bank_b/D45: J2.113, U1.G18
/fpga_front_end_bank_b/D46: J2.116, U1.H16
/fpga_front_end_bank_b/D47: J2.115, U1.F15
/fpga_front_end_bank_b/D48: J2.118, U1.J17
/fpga_front_end_bank_b/D49: J2.117, U1.G16
/fpga_front_end_bank_b/D50: J2.120, U1.E17
/fpga_front_end_bank_b/D51: J2.119, U1.E15
/fpga_front_end_bank_b/VCCIO_DEFAULT_EN: R5.1, U15.5, U16.5, U17.5, U20.4
/fpga_front_end_bank_b/VREF: C19.2, C23.1, R12.1, R13.2, U1.F18, U1.F22, U1.G15, U1.G17
/fpga_front_end_bank_c/D0: J2.122, U1.E8
/fpga_front_end_bank_c/D1: J2.121, U1.F12
/fpga_front_end_bank_c/D2: J2.124, U1.E11
/fpga_front_end_bank_c/D3: J2.123, U1.E12
/fpga_front_end_bank_c/D4: J2.126, U1.E14
/fpga_front_end_bank_c/D5: J2.125, U1.C8
/fpga_front_end_bank_c/D6: J2.128, U1.E7
/fpga_front_end_bank_c/D7: J2.127, U1.D14
/fpga_front_end_bank_c/D8: J2.130, U1.E10
/fpga_front_end_bank_c/D9: J2.129, U1.C14
/fpga_front_end_bank_c/D10: J2.134, U1.D13
/fpga_front_end_bank_c/D11: J2.133, U1.F10
/fpga_front_end_bank_c/D12: J2.136, U1.C13
/fpga_front_end_bank_c/D13: J2.135, U1.D10
/fpga_front_end_bank_c/D14: J2.138, U1.G10
/fpga_front_end_bank_c/D15: J2.137, U1.D8
/fpga_front_end_bank_c/D16: J2.140, U1.D12
/fpga_front_end_bank_c/D17: J2.139, U1.F7
/fpga_front_end_bank_c/D18: J2.142, U1.C12
/fpga_front_end_bank_c/D19: J2.141, U1.F8
/fpga_front_end_bank_c/D20: J2.146, U1.C11
/fpga_front_end_bank_c/D21: J2.145, U1.B14
/fpga_front_end_bank_c/D22: J2.148, U1.D11
/fpga_front_end_bank_c/D23: J2.147, U1.A14
/fpga_front_end_bank_c/D24: J2.150, U1.C10
/fpga_front_end_bank_c/D25: J2.149, U1.A12
/fpga_front_end_bank_c/D26: J2.152, U1.D9
/fpga_front_end_bank_c/D27: J2.151, U1.B11
/fpga_front_end_bank_c/D28: J2.154, U1.C9
/fpga_front_end_bank_c/D29: J2.153, U1.A11
/fpga_front_end_bank_c/D30: J2.158, U1.D7
/fpga_front_end_bank_c/D31: J2.157, U1.B10
/fpga_front_end_bank_c/D32: J2.160, U1.C7
/fpga_front_end_bank_c/D33: J2.159, U1.A10
/fpga_front_end_bank_c/D34: J2.162, U1.G8
/fpga_front_end_bank_c/D35: J2.161, U1.A8
/fpga_front_end_bank_c/D36: J2.164, U1.D6
/fpga_front_end_bank_c/D37: J2.163, U1.B8
/fpga_front_end_bank_c/D38: J2.166, U1.C6
/fpga_front_end_bank_c/D39: J2.165, U1.A7
/fpga_front_end_bank_c/D40: J2.170, U1.D5
/fpga_front_end_bank_c/D41: J2.169, U1.B6
/fpga_front_end_bank_c/D42: J2.172, U1.C5
/fpga_front_end_bank_c/D43: J2.171, U1.A6
/fpga_front_end_bank_c/D44: J2.174, U1.C4
/fpga_front_end_bank_c/D45: J2.173, U1.B7
/fpga_front_end_bank_c/D46: J2.176, U1.D4
/fpga_front_end_bank_c/D47: J2.175, U1.B4
/fpga_front_end_bank_c/D48: J2.178, U1.C3
/fpga_front_end_bank_c/D49: J2.177, U1.A4
/fpga_front_end_bank_c/D50: J2.180, U1.A3
/fpga_front_end_bank_c/D51: J2.179, U1.B3
/fpga_front_end_bank_c/VREF: C20.2, C22.1, R41.2, R42.1, U1.F11, U1.G9, U1.G12, U1.G14
/fpga_front_end_misc/D0: J2.14, U1.L26
/fpga_front_end_misc/D1: J2.13, U1.M23
/fpga_front_end_misc/D2: J2.16, U1.K25
/fpga_front_end_misc/D3: J2.15, U1.L23
/fpga_front_end_misc/D4: J2.18, U1.K26
/fpga_front_end_misc/D5: J2.17, U1.J23
/fpga_front_end_misc/D6: J2.20, U1.J25
/fpga_front_end_misc/D7: J2.19, U1.H23
/fpga_front_end_misc/D8: J2.22, U1.J26
/fpga_front_end_misc/D9: J2.21, U1.G23
/fpga_front_end_misc/D10: J2.26, U1.H26
/fpga_front_end_misc/D11: J2.25, U1.M24
/fpga_front_end_misc/D12: J2.28, U1.G25
/fpga_front_end_misc/D13: J2.27, U1.L25
/fpga_front_end_misc/D14: J2.30, U1.G26
/fpga_front_end_misc/D15: J2.29, U1.L24
/fpga_front_end_misc/D16: J2.32, U1.F25
/fpga_front_end_misc/D17: J2.31, U1.J24
/fpga_front_end_misc/D18: J2.34, U1.F26
/fpga_front_end_misc/D19: J2.33, U1.H25
/fpga_front_end_misc/D20: J2.38, U1.E25
/fpga_front_end_misc/D21: J2.37, U1.H24
/fpga_front_end_misc/D22: J2.40, U1.E26
/fpga_front_end_misc/D23: J2.39, U1.G24
/fpga_front_end_misc/D24: J2.42, U1.D25
/fpga_front_end_misc/D25: J2.41, U1.F24
/fpga_front_end_misc/D26: J2.44, U1.D26
/fpga_front_end_misc/D27: J2.43, U1.E24
/fpga_front_end_misc/D28: J2.46, U1.C26
/fpga_front_end_misc/D29: J2.45, U1.D24
/fpga_front_end_misc/D30: J2.50, U1.L28
/fpga_front_end_misc/D31: J2.49, U1.F27
/fpga_front_end_misc/D32: J2.52, U1.L27
/fpga_front_end_misc/D33: J2.51, U1.F28
/fpga_front_end_misc/D34: J2.54, U1.K28
/fpga_front_end_misc/D35: J2.53, U1.E28
/fpga_front_end_misc/D36: J2.56, U1.J27
/fpga_front_end_misc/D37: J2.55, U1.D27
/fpga_front_end_misc/D38: J2.58, U1.J28
/fpga_front_end_misc/D39: J2.57, U1.D28
/fpga_front_end_misc/D40: J2.60, U1.G28
/fpga_front_end_misc/D41: J2.59, U1.C27
/fpga_front_end_misc/FPGA_CONF_DONE: R51.2, U1.P24, U3.47
/fpga_front_end_misc/VREF: C18.2, C21.1, R23.1, R24.2, U1.J22, U1.M21, U1.M25, U1.N21
/fpga_power/VCCD_PLL: C4064.1, C4065.1, C4066.1, C4067.1, FB7.2, U1.J9, U1.J20, U1.Y9, U1.Y20
/fpga_usb0/PIPE_POWERDOWN0: U1.R7, U2.H3
/fpga_usb0/PIPE_POWERDOWN1: U1.R5, U2.G3
/fpga_usb0/PIPE_PWRPRESENT: U1.AB5, U2.H11
/fpga_usb0/PIPE_RESETN: R16.2, U1.AB6, U2.J11
/fpga_usb0/PIPE_RX_DATA0: U1.T4, U2.E2
/fpga_usb0/PIPE_RX_DATA1: U1.U3, U2.D2
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

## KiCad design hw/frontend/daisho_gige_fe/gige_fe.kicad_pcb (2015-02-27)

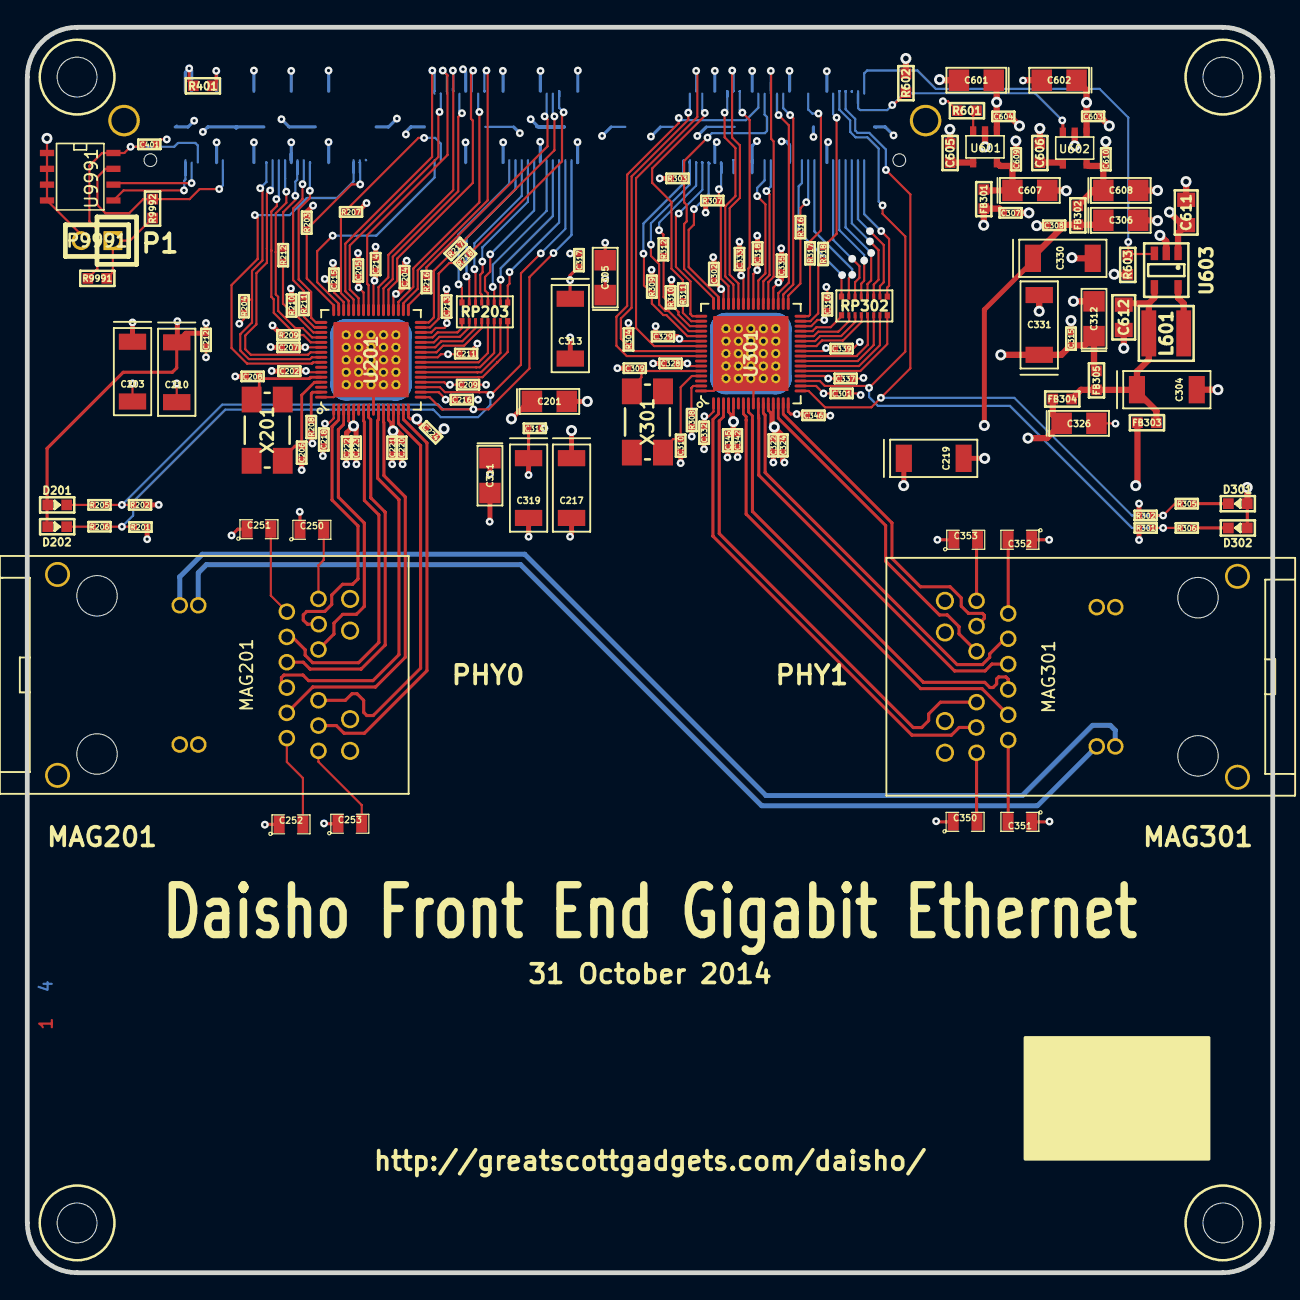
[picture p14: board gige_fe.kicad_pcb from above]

Board: 4 copper layers, 100.0 x 100.0 mm, 142 parts (0 on the bottom side), 150 nets.

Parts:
C201, C305, C306, C311, C312, C326, C601, C602, C607, C608: 10uF; gsg-sm1206p
C202, C307, C308, C314, C315, C328, C401, C603, C604, C609, C610: 0.1uF; GSG-0402
C203, C210, C217, C219: 47uF; GSG-2312
C204, C205, C207, C209, C211, C212, C213, C214, C215, C216, C218, C220, C221, C222, C223, C224, C301, C302, C316, C317, C318, C322, C324, C329, C332, C333, C335, C337, C339, C342, C345, C346: 10nF; GSG-0402
C206, C208, C309, C310: 22pF; GSG-0402
C250, C251, C252, C253, C350, C351, C352, C353: 0.1uF; SM0805
C304, C313, C319, C330, C331: 47uF; gsg-2312
C605, C606: 470pF; GSG-0603
C611, C612: 10uF; GSG-0805
D201: PHY0_ACT; GSG-0603D
D202: PHY0_LNK; GSG-0603D
D301: PHY1_ACT_YEL; GSG-0603D
D302: PHY1_LNK_GREEN; GSG-0603D
FB301, FB302, FB303, FB304, FB305: FBEAD; GSG-0603
H1, H2, H3, H4: HOLE; GSG-HOLE126MIL
J9991: SAMTEC_QSH-090-D; SAMTEC_QSH-090-01-F-D-A
L601: 4u7; GSG-NRG4026
MAG201, MAG301: BELFUSE-0826-1X1T-M1-F; BELFUSE-MAG
P9991: CONN_2; GSG-HEADER-1x2
R201, R202, R203, R205, R206, R207, R301, R302, R303, R305, R306, R307: 1k; GSG-0402
R204, R209, R210, R304, R309, R310: 4.7K; GSG-0402
R208, R308: 12.1k 1%; GSG-0402
R211, R212, R216, R217, R218, R311, R312, R316, R317, R318: 0; GSG-0402
R401, R601, R602, R603, R9991, R9992: 10k; GSG-0603
RP203, RP302: 0; 1506-RPACK
U201, U301: KSZ9031MNX; GSG-QFN64-25
U601: MIC5207-2.5YM5; SOT23-5
U602: MIC5207-3.3YM5; SOT23-5
U603: XC9236-MR; IPC_SOT95P280X110-5N
U9991: 24C08; SO8E
X201, X301: 25MHz; ABMM2

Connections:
/Board Power/V2P5_EN: R601.1, U601.3
/GigE Phy0/GTX_CLK: R217.1, U201.32
/GigE Phy0/LED1_D: D202.2, R206.1
/GigE Phy0/LED2_D: D201.2, R205.1
/GigE Phy0/TXD0: RP203.8, U201.21
/GigE Phy0/TXD1: RP203.7, U201.22
/GigE Phy0/TXD2: RP203.6, U201.23
/GigE Phy0/TXD3: RP203.5, U201.24
/GigE Phy0/TXD4: RP203.4, U201.26
/GigE Phy0/TXD5: RP203.3, U201.27
/GigE Phy0/TXD6: RP203.2, U201.28
/GigE Phy0/TXD7: RP203.1, U201.29
/GigE Phy1/GTX_CLK: R317.1, U301.32
/GigE Phy1/LED1_D: D302.2, R306.1
/GigE Phy1/LED2_D: D301.2, R305.1
/GigE Phy1/TXD0: RP302.8, U301.21
/GigE Phy1/TXD1: RP302.7, U301.22
/GigE Phy1/TXD2: RP302.6, U301.23
/GigE Phy1/TXD3: RP302.5, U301.24
/GigE Phy1/TXD4: RP302.4, U301.26
/GigE Phy1/TXD5: RP302.3, U301.27
/GigE Phy1/TXD6: RP302.2, U301.28
/GigE Phy1/TXD7: RP302.1, U301.29
/daisho connector/FE_I2C_SCL: J9991.4, U9991.6
/daisho connector/FE_I2C_SDA: J9991.2, U9991.5
/daisho connector/VALT_FE: J9991.1, J9991.3, R401.1
FE_I2C_EEPROM_WP: J9991.14, R9992.1, U9991.7
FE_I2C_VCC: C401.1, J9991.6, R9991.1, U9991.8
GIGE_AVDDH: C217.1, C218.1, C224.1, C306.1, C308.1, C330.1, C332.1, C346.1, FB302.2, U201.1, U201.16, U301.1, U301.16
GIGE_AVDDL: C219.1, C220.1, C221.1, C222.1, C223.1, C311.1, C314.1, C319.1, C322.1, C324.1, C342.1, C345.1, FB303.2, U201.4, U201.5, U201.12, U201.13, U301.4, U301.5, U301.12, U301.13
GIGE_AVDD_PLL: C201.1, C202.1, C326.1, C328.1, FB304.2, U201.59, U301.59
GIGE_DVDDH: C210.1, C212.1, C213.1, C214.1, C215.1, C216.1, C301.1, C302.1, C305.1, C307.1, C313.1, C316.1, C317.1, C318.1, D201.1, D202.1, D301.1, D302.1, FB301.2, J9991.12, J9991.24, J9991.36, J9991.48, J9991.71, J9991.72, J9991.83, J9991.84, J9991.95, J9991.96, J9991.107, J9991.108, J9991.131, J9991.132, J9991.143, J9991.144, J9991.155, J9991.156, J9991.167, J9991.168, R209.2, R210.1, R309.1, R310.1, U201.18, U201.30, U201.40, U201.46, U301.18, U301.30, U301.40, U301.46
GIGE_DVDDL: C203.1, C204.1, C205.1, C207.1, C209.1, C211.1, C312.1, C315.1, C329.1, C331.1, C333.1, C335.1, C337.1, C339.1, FB305.2, U201.20, U201.25, U201.36, U201.42, U201.54, U301.20, U301.25, U301.36, U301.42, U301.54
GND: C201.2, C202.2, C203.2, C204.2, C205.2, C206.1, C207.2, C208.1, C209.2, C210.2, C211.2, C212.2, C213.2, C214.2, C215.2, C216.2, C217.2, C218.2, C219.2, C220.2, C221.2, C222.2, C223.2, C224.2, C250.1, C251.1, C252.1, C253.1, C301.2, C302.2, C304.2, C305.2, C306.2, C307.2, C308.2, C309.1, C310.1, C311.2, C312.2, C313.2, C314.2, C315.2, C316.2, C317.2, C318.2, C319.2, C322.2, C324.2, C326.2, C328.2, C329.2, C330.2, C331.2, C332.2, C333.2, C335.2, C337.2, C339.2, C342.2, C345.2, C346.2, C350.1, C351.1, C352.1, C353.1, C401.2, C601.2, C602.2, C603.2, C604.2, C605.2, C606.2, C607.2, C608.2, C609.2, C610.2, C611.1, C612.2, J9991.A0, J9991.A1, J9991.A2, J9991.A3, J9991.B0, J9991.B1, J9991.B2, J9991.B3, J9991.C0, J9991.C1, J9991.C2, J9991.C3, P9991.2, R201.2, R202.2, R203.2, R204.2, R207.2, R208.1, R301.2, R302.2, R303.2, R304.2, R307.2, R308.1, R602.2, R603.2, U201.0, U201.9, U201.64, U301.0, U301.9, U301.64, U601.2, U602.2, U603.2, U9991.1, U9991.2, U9991.3, U9991.4
MAG_VC_1: MAG201.13, MAG301.13
MAG_VC_2: MAG201.14, MAG301.14
MAG_VC_3: MAG201.15, MAG301.15
MAG_VC_4: MAG201.16, MAG301.16
unnamed: C206.2, U201.61, X201.1
unnamed: C208.2, U201.60, X201.2
unnamed: C250.2, MAG201.12
unnamed: C251.2, MAG201.6
unnamed: C252.2, MAG201.1
unnamed: C253.2, MAG201.7
unnamed: C309.2, U301.60, X301.2
unnamed: C310.2, U301.61, X301.1
unnamed: C350.2, MAG301.12
unnamed: C351.2, MAG301.6
unnamed: C352.2, MAG301.1
unnamed: C353.2, MAG301.7
unnamed: C605.1, U601.4
unnamed: C606.1, U602.4
unnamed: L601.1, U603.5
unnamed: P9991.1, R9991.2, R9992.2
unnamed: R208.2, U201.63
unnamed: R308.2, U301.63
PHY0_CLK125_NDO: J9991.30, U201.55
PHY0_COL: J9991.34, U201.52
PHY0_CRS: J9991.42, U201.49
PHY0_GM_GTX_CLK: J9991.99, R217.2
PHY0_GM_MDC: J9991.40, R211.2
PHY0_GM_MIO: J9991.38, R212.2
PHY0_GM_RXD0: J9991.61, U201.44
PHY0_GM_RXD1: J9991.63, U201.43
PHY0_GM_RXD2: J9991.65, U201.41
PHY0_GM_RXD3: J9991.67, U201.39
PHY0_GM_RXD4: J9991.69, U201.38
PHY0_GM_RXD5: J9991.73, U201.37
PHY0_GM_RXD6: J9991.75, U201.35
PHY0_GM_RXD7: J9991.77, U201.34
PHY0_GM_RX_CLK: J9991.58, R203.1, U201.48
PHY0_GM_RX_ERR: J9991.62, U201.47
PHY0_GM_TXD0: J9991.102, RP203.9
PHY0_GM_TXD1: J9991.100, RP203.10
PHY0_GM_TXD2: J9991.98, RP203.11
PHY0_GM_TXD3: J9991.94, RP203.12
PHY0_GM_TXD4: J9991.92, RP203.13
PHY0_GM_TXD5: J9991.90, RP203.14
PHY0_GM_TXD6: J9991.88, RP203.15
PHY0_GM_TXD7: J9991.86, RP203.16
PHY0_GM_TX_EN: J9991.97, R216.2
PHY0_GM_TX_ER: J9991.101, R218.2
PHY0_HW_RST: J9991.28, R204.1, U201.56
PHY0_INT_N: J9991.32, R209.1, U201.53
PHY0_MDC: R211.1, U201.50
PHY0_MDIO: R210.2, R212.1, U201.51
PHY0_PHYADDR0: J9991.104, R201.1, R206.2, U201.19
PHY0_PHYADDR1: J9991.106, R202.1, R205.2, U201.17
PHY0_RXDV: J9991.64, R207.1, U201.45
PHY0_TXRXM_A: MAG201.10, U201.3
PHY0_TXRXM_B: MAG201.4, U201.8
PHY0_TXRXM_C: MAG201.2, U201.11
PHY0_TXRXM_D: MAG201.8, U201.15
PHY0_TXRXP_A: MAG201.11, U201.2
PHY0_TXRXP_B: MAG201.5, U201.7
PHY0_TXRXP_C: MAG201.3, U201.10
PHY0_TXRXP_D: MAG201.9, U201.14
PHY0_TX_CLK: J9991.56, U201.57
PHY0_TX_EN: R216.1, U201.33
PHY0_TX_ER: R218.1, U201.31
PHY1_CLK125_NDO: J9991.125, U301.55
PHY1_COL: J9991.124, U301.52
PHY1_CRS: J9991.128, U301.49
PHY1_GM_GTX_CLK: J9991.161, R317.2
PHY1_GM_MDC: J9991.127, R311.2
PHY1_GM_MIO: J9991.126, R312.2
PHY1_GM_RXD0: J9991.135, U301.44
PHY1_GM_RXD1: J9991.137, U301.43
PHY1_GM_RXD2: J9991.139, U301.41
PHY1_GM_RXD3: J9991.148, U301.39
PHY1_GM_RXD4: J9991.150, U301.38
PHY1_GM_RXD5: J9991.149, U301.37
PHY1_GM_RXD6: J9991.151, U301.35
PHY1_GM_RXD7: J9991.153, U301.34
PHY1_GM_RXDV: J9991.134, R307.1, U301.45
PHY1_GM_RX_CLK: J9991.147, R303.1, U301.48
PHY1_GM_RX_ERR: J9991.130, U301.47
PHY1_GM_TXD0: J9991.180, RP302.9
PHY1_GM_TXD1: J9991.178, RP302.10
PHY1_GM_TXD2: J9991.176, RP302.11
PHY1_GM_TXD3: J9991.174, RP302.12
PHY1_GM_TXD4: J9991.172, RP302.13
PHY1_GM_TXD5: J9991.170, RP302.14
PHY1_GM_TXD6: J9991.164, RP302.15
PHY1_GM_TXD7: J9991.160, RP302.16
PHY1_GM_TX_EN: J9991.162, R316.2
PHY1_GM_TX_ER: J9991.169, R318.2
PHY1_HW_RST: J9991.123, R304.1, U301.56
PHY1_INT_N: J9991.122, R309.2, U301.53
PHY1_MDC: R311.1, U301.50
PHY1_MDIO: R310.2, R312.1, U301.51
PHY1_PHYADDR0: J9991.171, R301.1, R306.2, U301.19
PHY1_PHYADDR1: J9991.173, R302.1, R305.2, U301.17
PHY1_TXRXM_A: MAG301.10, U301.3
PHY1_TXRXM_B: MAG301.4, U301.8
PHY1_TXRXM_C: MAG301.2, U301.11
PHY1_TXRXM_D: MAG301.8, U301.15
PHY1_TXRXP_A: MAG301.11, U301.2
PHY1_TXRXP_B: MAG301.5, U301.7
PHY1_TXRXP_C: MAG301.3, U301.10
PHY1_TXRXP_D: MAG301.9, U301.14
PHY1_TX_CLK: J9991.145, U301.57
PHY1_TX_EN: R316.1, U301.33
PHY1_TX_ER: R318.1, U301.31
V1P2_EN: J9991.179, R603.1, U603.3
V1P2_REG: C304.1, C612.1, FB303.1, FB304.1, FB305.1, L601.2, U603.4
V2P5_REG: C607.1, C609.1, FB301.1, U601.5
V3P3_EN: J9991.177, R602.1, U602.3
V3P3_REG: C608.1, C610.1, FB302.1, U602.5
VRAW_SW_5V: C601.1, C602.1, C603.1, C604.1, C611.2, J9991.11, J9991.23, J9991.35, J9991.47, R401.2, R601.2, U601.1, U602.1, U603.1

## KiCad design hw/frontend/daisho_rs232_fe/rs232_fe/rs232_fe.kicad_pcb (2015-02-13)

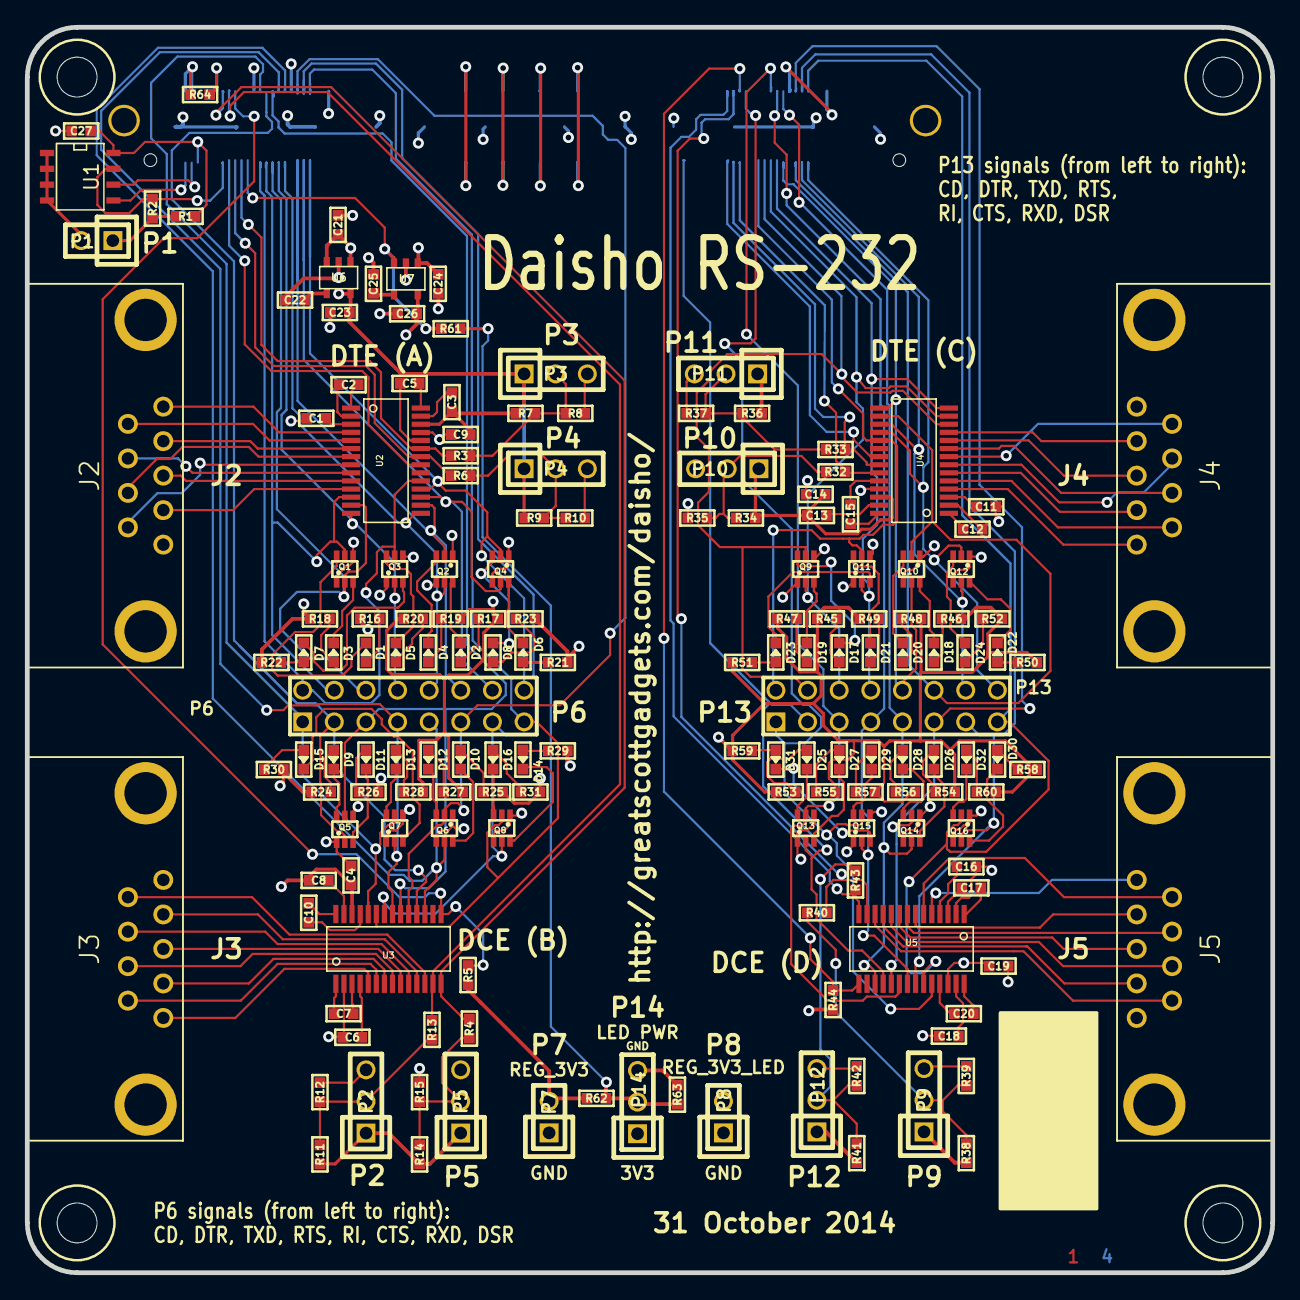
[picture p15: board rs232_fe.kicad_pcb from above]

Board: 4 copper layers, 100.0 x 100.0 mm, 169 parts (1 on the bottom side), 186 nets.

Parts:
C1, C2, C3, C4, C5, C6, C7, C8, C9, C10, C11, C12, C13, C14, C15, C16, C17, C18, C19, C20, C27: 0.1uF; GSG-0603
C21, C23, C24, C26: 1uF; GSG-0603
C22, C25: 100nF; GSG-0603
D1, D2, D3, D4, D5, D6, D7, D8, D9, D10, D11, D12, D13, D14, D15, D16, D17, D18, D19, D20, D21, D22, D23, D24, D25, D26, D27, D28, D29, D30, D31, D32: LED; GSG-0603D
H1, H2, H3, H4: HOLE; GSG-HOLE126MIL
J1: SAMTEC_QSH-090-D; SAMTEC_QSH-090-01-F-D-A
J2, J4: DB9; SDS107-PRW1-M09-SN63-11
J3, J5: DB9; SDS107-PRP2-F09-SN13-11
P1, P7, P8: CONN_2; GSG-HEADER-1x2
P2, P3, P4, P5, P9, P10, P11, P12, P14: CONN_3; GSG-HEADER-1x3
P6, P13: CONN_8X2; pin_array_8x2
Q1, Q2, Q3, Q4, Q5, Q6, Q7, Q8, Q9, Q10, Q11, Q12, Q13, Q14, Q15, Q16: MUN5212DW1; GSG-SOT363
R1, R2, R3, R6, R7, R8, R9, R10, R11, R12, R14, R15, R32, R33, R34, R35, R36, R37, R38, R39, R41, R42, R61, R62, R63, R64: 10k; GSG-0603
R4, R5, R13, R40, R43, R44: 10K; GSG-0603
R16, R17, R18, R19, R20, R21, R22, R23, R24, R25, R26, R27, R28, R29, R30, R31, R45, R46, R47, R48, R49, R50, R51, R52, R53, R54, R55, R56, R57, R58, R59, R60: 470; GSG-0603
U1: 24C08; SO8E
U2, U4: TRSF3243; tssop-28
U3, U5: TRS3237E; tssop-28
U6, U7: MIC5318; SOT23-5

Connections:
!EN-B-TTL: J1.15, R13.1, U3.13
!EN-D-TTL: J1.137, R40.1, U5.13
!FORCEOFF-A-TTL: J1.18, R6.1, U2.22
!FORCEOFF-C-TTL: J1.138, R33.1, U4.22
!INVALID-A-TTL: J1.16, U2.21
!INVALID-C-TTL: J1.136, U4.21
!SHDN-B-TTL: J1.13, R4.1, U3.14
!SHDN-D-TTL: J1.135, R43.1, U5.14
/daisho_connector/FE_I2C_SCL: J1.4, U1.6
/daisho_connector/FE_I2C_SDA: J1.2, U1.5
/daisho_connector/VALT_FE: J1.1, J1.3, R64.2
/daisho_connector/VRAW_SW_5V: C21.1, C24.1, J1.11, J1.23, J1.35, J1.47, R64.1, U6.1, U6.3, U7.1
/rs232_pair_AB/CD-A-232: J2.1, U2.4
/rs232_pair_AB/CD-B-232: J3.1, U3.5
/rs232_pair_AB/CTS-A-232: J2.8, U2.7
/rs232_pair_AB/CTS-B-232: J3.8, U3.10
/rs232_pair_AB/DSR-A-232: J2.6, U2.5
/rs232_pair_AB/DSR-B-232: J3.6, U3.6
/rs232_pair_AB/DTR-A-232: J2.4, U2.11
/rs232_pair_AB/DTR-B-232: J3.4, U3.11
/rs232_pair_AB/RI-A-232: J2.9, U2.8
/rs232_pair_AB/RI-B-232: J3.9, U3.12
/rs232_pair_AB/RTS-A-232: J2.7, U2.9
/rs232_pair_AB/RTS-B-232: J3.7, U3.8
/rs232_pair_AB/RXD-A-232: J2.2, U2.6
/rs232_pair_AB/RXD-B-232: J3.2, U3.7
/rs232_pair_AB/TXD-A-232: J2.3, U2.10
/rs232_pair_AB/TXD-B-232: J3.3, U3.9
/rs232_pair_CD/CD-C-232: J4.1, U4.4
/rs232_pair_CD/CD-D-232: J5.1, U5.5
/rs232_pair_CD/CTS-C-232: J4.8, U4.7
/rs232_pair_CD/CTS-D-232: J5.8, U5.10
/rs232_pair_CD/DSR-C-232: J4.6, U4.5
/rs232_pair_CD/DSR-D-232: J5.6, U5.6
/rs232_pair_CD/DTR-C-232: J4.4, U4.11
/rs232_pair_CD/DTR-D-232: J5.4, U5.11
/rs232_pair_CD/RI-C-232: J4.9, U4.8
/rs232_pair_CD/RI-D-232: J5.9, U5.12
/rs232_pair_CD/RTS-C-232: J4.7, U4.9
/rs232_pair_CD/RTS-D-232: J5.7, U5.8
/rs232_pair_CD/RXD-C-232: J4.2, U4.6
/rs232_pair_CD/RXD-D-232: J5.2, U5.7
/rs232_pair_CD/TXD-C-232: J4.3, U4.10
/rs232_pair_CD/TXD-D-232: J5.3, U5.9
CD-A-TTL: J1.26, P6.2, Q3.5, U2.19
CD-B-TTL: J1.25, P6.1, Q7.5, U3.24
CD-C-TTL: J1.146, P13.2, Q11.5, U4.19
CD-D-TTL: J1.141, P13.1, Q15.5, U5.24
CTS-A-TTL: J1.38, P6.12, Q2.2, U2.16
CTS-B-TTL: J1.37, P6.11, Q6.2, U3.19
CTS-C-TTL: J1.158, P13.12, Q10.2, U4.16
CTS-D-TTL: J1.157, P13.11, Q14.2, U5.19
DSR-A-TTL: J1.42, P6.16, Q4.2, U2.18
DSR-B-TTL: J1.41, P6.15, Q8.2, U3.23
DSR-C-TTL: J1.162, P13.16, Q12.2, U4.18
DSR-D-TTL: J1.161, P13.15, Q16.2, U5.23
DTR-A-TTL: J1.28, P6.4, Q1.5, U2.12
DTR-B-TTL: J1.27, P6.3, Q5.2, U3.18
DTR-C-TTL: J1.148, P13.4, Q9.5, U4.12
DTR-D-TTL: J1.122, P13.3, Q13.2, U5.18
FE_I2C_EEPROM_WP: J1.14, R2.1, U1.7
FE_I2C_VCC: C27.1, J1.6, R1.1, U1.8
FORCEON-A-TTL: J1.20, R3.1, U2.23
FORCEON-C-TTL: J1.140, R32.1, U4.23
GND: C1.2, C4.2, C6.2, C9.2, C11.2, C14.2, C16.2, C19.2, C21.2, C22.2, C23.2, C24.2, C25.2, C26.2, C27.2, J1.A0, J1.A1, J1.A2, J1.A3, J1.B0, J1.B1, J1.B2, J1.B3, J1.C0, J1.C1, J1.C2, J1.C3, J2.5, J3.5, J4.5, J5.5, P1.2, P2.3, P3.3, P4.3, P5.3, P7.1, P8.1, P9.3, P10.3, P11.3, P12.3, P14.3, Q1.1, Q1.4, Q2.1, Q2.4, Q3.1, Q3.4, Q4.1, Q4.4, Q5.1, Q5.4, Q6.1, Q6.4, Q7.1, Q7.4, Q8.1, Q8.4, Q9.1, Q9.4, Q10.1, Q10.4, Q11.1, Q11.4, Q12.1, Q12.4, Q13.1, Q13.4, Q14.1, Q14.4, Q15.1, Q15.4, Q16.1, Q16.4, R8.2, R10.2, R12.2, R15.2, R35.2, R37.2, R39.2, R42.2, R63.2, U1.1, U1.2, U1.3, U1.4, U2.25, U3.2, U4.25, U5.2, U6.2, U7.2
LEDS_PWR: J1.22, R61.1, U7.3
MBAUD-B-TTL: J1.17, R5.1, U3.15
MBAUD-D-TTL: J1.139, R44.1, U5.15
unnamed: C1.1, U2.3
unnamed: C2.1, U2.1
unnamed: C2.2, U2.2
unnamed: C3.1, U2.27
unnamed: C5.1, U2.24
unnamed: C5.2, U2.28
unnamed: C6.1, U3.4
unnamed: C7.1, U3.1
unnamed: C7.2, U3.3
unnamed: C8.2, U3.27
unnamed: C10.1, U3.28
unnamed: C10.2, U3.25
unnamed: C11.1, U4.3
unnamed: C12.1, U4.1
unnamed: C12.2, U4.2
unnamed: C13.1, U4.27
unnamed: C15.1, U4.24
unnamed: C15.2, U4.28
unnamed: C16.1, U5.4
unnamed: C17.1, U5.1
unnamed: C17.2, U5.3
unnamed: C18.2, U5.27
unnamed: C20.1, U5.28
unnamed: C20.2, U5.25
unnamed: C22.1, U6.4
unnamed: C25.1, U7.4
unnamed: D1.1, R16.1
unnamed: D1.2, Q1.6
unnamed: D2.1, R17.1
unnamed: D2.2, Q2.6
unnamed: D3.1, R18.1
unnamed: D3.2, Q1.3
unnamed: D4.1, R19.1
unnamed: D4.2, Q2.3
unnamed: D5.1, R20.1
unnamed: D5.2, Q3.6
unnamed: D6.1, R21.1
unnamed: D6.2, Q4.6
unnamed: D7.1, R22.1
unnamed: D7.2, Q3.3
unnamed: D8.1, R23.1
unnamed: D8.2, Q4.3
unnamed: D9.1, R24.1
unnamed: D9.2, Q5.6
unnamed: D10.1, R25.1
unnamed: D10.2, Q6.6
unnamed: D11.1, R26.1
unnamed: D11.2, Q5.3
unnamed: D12.1, R27.1
unnamed: D12.2, Q6.3
unnamed: D13.1, R28.1
unnamed: D13.2, Q7.6
unnamed: D14.1, R29.1
unnamed: D14.2, Q8.6
unnamed: D15.1, R30.1
unnamed: D15.2, Q7.3
unnamed: D16.1, R31.1
unnamed: D16.2, Q8.3
unnamed: D17.1, R45.1
unnamed: D17.2, Q9.6
unnamed: D18.1, R46.1
unnamed: D18.2, Q10.6
unnamed: D19.1, R47.1
unnamed: D19.2, Q9.3
unnamed: D20.1, R48.1
unnamed: D20.2, Q10.3
unnamed: D21.1, R49.1
unnamed: D21.2, Q11.6
unnamed: D22.1, R50.1
unnamed: D22.2, Q12.6
unnamed: D23.1, R51.1
unnamed: D23.2, Q11.3
unnamed: D24.1, R52.1
unnamed: D24.2, Q12.3
unnamed: D25.1, R53.1
unnamed: D25.2, Q13.6
unnamed: D26.1, R54.1
unnamed: D26.2, Q14.6
unnamed: D27.1, R55.1
unnamed: D27.2, Q13.3
unnamed: D28.1, R56.1
unnamed: D28.2, Q14.3
unnamed: D29.1, R57.1
unnamed: D29.2, Q15.6
unnamed: D30.1, R58.1
unnamed: D30.2, Q16.6
unnamed: D31.1, R59.1
unnamed: D31.2, Q15.3
unnamed: D32.1, R60.1
unnamed: D32.2, Q16.3
unnamed: P1.1, R1.2, R2.2
unnamed: P2.2, R11.2, R12.1, R13.2
unnamed: P3.2, R3.2, R7.2, R8.1
unnamed: P4.2, R6.2, R9.2, R10.1
unnamed: P5.2, R4.2, R14.2, R15.1
unnamed: P9.2, R38.2, R39.1, R40.2
unnamed: P10.2, R32.2, R34.2, R35.1
unnamed: P11.2, R33.2, R36.2, R37.1
unnamed: P12.2, R41.2, R42.1, R43.2
unnamed: P14.2, R61.2, R62.2, R63.1
REG_3V3: C3.2, C4.1, C8.1, C9.1, C13.2, C14.1, C18.1, C19.1, C23.1, J1.12, J1.24, J1.36, J1.48, J1.71, J1.72, J1.83, J1.84, J1.95, J1.96, J1.107, J1.108, J1.131, J1.132, J1.143, J1.144, J1.155, J1.156, J1.167, J1.168, P2.1, P3.1, P4.1, P5.1, P7.2, P9.1, P10.1, P11.1, P12.1, P14.1, R5.2, R7.1, R9.1, R11.1, R14.1, R34.1, R36.1, R38.1, R41.1, R44.2, R62.1, U2.26, U3.26, U4.26, U5.26, U6.5
REG_3V3_LED: C26.1, P8.2, R16.2, R17.2, R18.2, R19.2, R20.2, R21.2, R22.2, R23.2, R24.2, R25.2, R26.2, R27.2, R28.2, R29.2, R30.2, R31.2, R45.2, R46.2, R47.2, R48.2, R49.2, R50.2, R51.2, R52.2, R53.2, R54.2, R55.2, R56.2, R57.2, R58.2, R59.2, R60.2, U7.5
RI-A-TTL: J1.34, P6.10, Q2.5, U2.15
RI-B-TTL: J1.33, P6.9, Q6.5, U3.17
RI-C-TTL: J1.154, P13.10, Q10.5, U4.15
RI-D-TTL: J1.153, P13.9, Q14.5, U5.17
RTS-A-TTL: J1.32, P6.8, Q3.2, U2.14
RTS-B-TTL: J1.31, P6.7, Q7.2, U3.21
RTS-C-TTL: J1.152, P13.8, Q11.2, U4.14
RTS-D-TTL: J1.151, P13.7, Q15.2, U5.21
RXD-A-TTL: J1.40, P6.14, Q4.5, U2.17
RXD-B-TTL: J1.39, P6.13, Q8.5, U3.22
RXD-C-TTL: J1.160, P13.14, Q12.5, U4.17
RXD-D-TTL: J1.159, P13.13, Q16.5, U5.22
TXD-A-TTL: J1.30, P6.6, Q1.2, U2.13
TXD-B-TTL: J1.29, P6.5, Q5.5, U3.20
TXD-C-TTL: J1.150, P13.6, Q9.2, U4.13
TXD-D-TTL: J1.149, P13.5, Q13.5, U5.20

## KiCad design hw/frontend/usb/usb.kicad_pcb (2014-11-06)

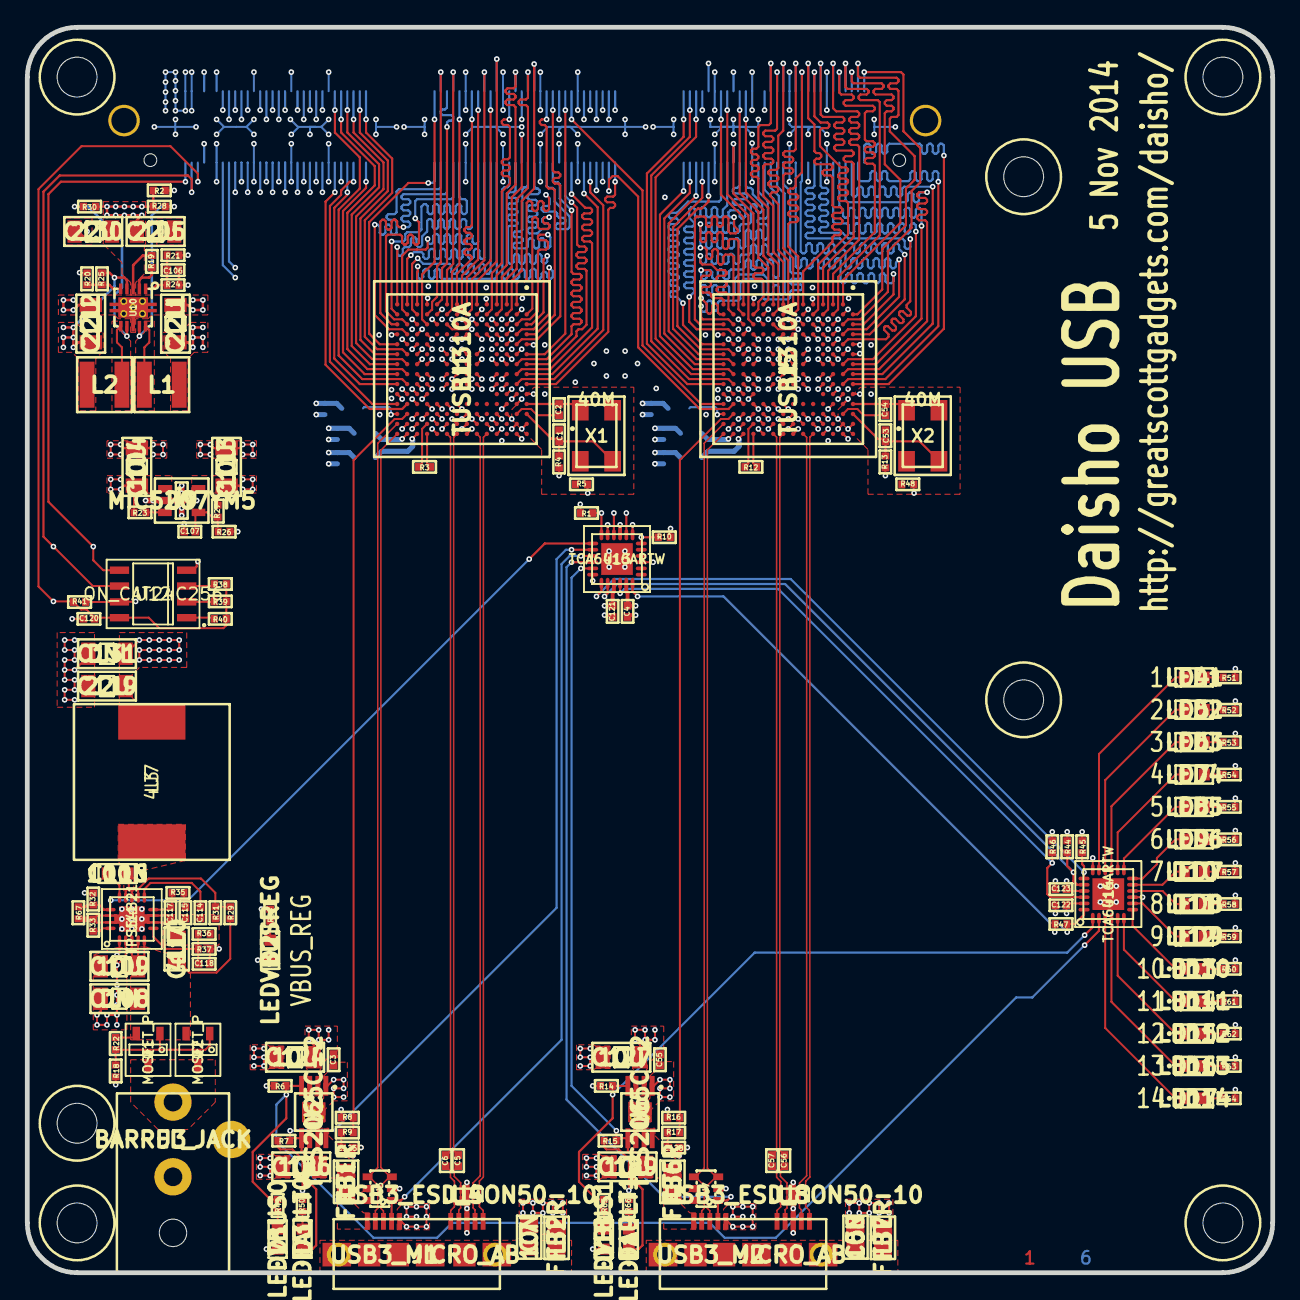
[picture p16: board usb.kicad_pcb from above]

Board: 6 copper layers, 100.0 x 100.0 mm, 261 parts (0 on the bottom side), 265 nets.

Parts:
C1, C2, C53, C54: 27P; IPC_CAPC1005X55N
C3, C4, C5, C6, C8, C9, C10, C11, C12, C13, C14, C15, C16, C17, C18, C19, C20, C21, C22, C23, C24, C25, C26, C27, C28, C29, C30, C31, C32, C33, C34, C35, C36, C37, C38, C40, C41, C42, C43, C44, C45, C46, C47, C48, C49, C50, C51, C52, C55, C56, C57, C59, C60, C61, C62, C63, C64, C65, C66, C67, C68, C69, C70, C71, C72, C73, C74, C75, C76, C77, C78, C79, C80, C81, C82, C83, C84, C85, C86, C87, C88, C89, C91, C92, C93, C94, C95, C96, C97, C98, C99, C100, C101, C102, C103, C120, C121, C122, C123, C125, C128: 100N; IPC_CAPC1005X55N
C7, C58: 10N; IPC_CAPC2012X140N
C39, C90: 1U; IPC_CAPC1005X55N
C104, C109, C113, C124, C126, C127, C129: 10U; IPC_CAPC3216X180N
C105, C111, C112, C119, C130: 22U; IPC_CAPC3216X180N
C106: 33P; IPC_CAPC1005X55N
C107: 470P; IPC_CAPC1005X55N
C108, C131: DNI; IPC_CAPC3216X180N
C110: 4U7; IPC_CAPC2012X140N
C114: 22N; IPC_CAPC1005X55N
C115: 82N; IPC_CAPC1005X55N
C116: 100N; IPC_CAPC1608X90N
C117: 1N5; IPC_CAPC1005X55N
C118: 220P; IPC_CAPC1005X55N
D1: LEDVBUS0; IPC_LEDC1608X60N
D2: LEDVBUSREG; IPC_LEDC1608X60N
D3: LEDFAULT0; IPC_LEDC1608X60N
D4: LED1; IPC_LEDC1608X60N
D5: LED2; IPC_LEDC1608X60N
D6: LED3; IPC_LEDC1608X60N
D7: LED4; IPC_LEDC1608X60N
D8: LED5; IPC_LEDC1608X60N
D9: LED6; IPC_LEDC1608X60N
D10: LED7; IPC_LEDC1608X60N
D11: LED8; IPC_LEDC1608X60N
D12: LED9; IPC_LEDC1608X60N
D13: LED10; IPC_LEDC1608X60N
D14: LED11; IPC_LEDC1608X60N
D15: LED12; IPC_LEDC1608X60N
D16: LED13; IPC_LEDC1608X60N
D17: LED14; IPC_LEDC1608X60N
D18: LEDVBUS1; IPC_LEDC1608X60N
D19: LEDFAULT1; IPC_LEDC1608X60N
FB1, FB2, FB3, FB4, FB5, FB6, FB7, FB8, FB9, FB10: FILTER; IPC_INDC2012X130N
H1, H2, H4, H5, H6, H7, H8: HOLE; GSG-HOLE126MIL
J1, J2: USB3_MICRO_AB
J3: BARREL_JACK; CUI_PJ-102[AB]H
J4: SAMTEC_QSH-090-D; SAMTEC_QSH-090-01-F-D-A
L1, L2: 4U7; GSG-NRG4026
L3: 4U7; BOURNS_SRR1260
P4, P5, P6, P7, P8: CONN_1; GSG-TESTPOINT-50MIL
Q1, Q2: MOSFET_P; IPC_SOT95P280X125-3N_GSD
R1, R2, R3, R6, R7, R8, R10, R12, R14, R15, R16, R19, R44, R45, R46, R47: 10K; IPC_RESC1005X40N
R4, R5, R13, R38, R39, R40, R41, R48: DNI; IPC_RESC1005X40N
R9, R17: 90K9; IPC_RESC1005X40N
R18, R22: 30K; IPC_RESC1005X40N
R20: 165K; IPC_RESC1005X40N
R21: 180K; IPC_RESC1005X40N
R23, R28, R30: 0R; IPC_RESC1005X40N
R24: 360K; IPC_RESC1005X40N
R25: 137K; IPC_RESC1005X40N
R26: 174K; IPC_RESC1005X40N
R27: 105K; IPC_RESC1005X40N
R29: 22K; IPC_RESC1005X40N
R31: 9K53; IPC_RESC1005X40N
R32: 49K9; IPC_RESC1005X40N
R33: 52K3; IPC_RESC1005X40N
R34, R49, R50, R51, R52, R53, R54, R55, R56, R57, R58, R59, R60, R61, R62, R63, R64, R65, R66: 1K; IPC_RESC1005X40N
R35: 1K58; IPC_RESC1005X40N
R36: 2K21; IPC_RESC1005X40N
R37: 16K2; IPC_RESC1005X40N
R67: 1M; IPC_RESC1005X40N
U1, U5: TUSB1310A; IPC_BGA175C80P14X14_1200X1200X140
U2, U6: TPS2065C-2; TI_DGN_S-PDSO-G8
U3, U7: GSG-IP4220CZ6; GSG-SOT457
U4, U8: USB3_ESD_SON50-10
U9: MIC5207YM5; IPC_SOT95P280X110-5N
U10: TPS62420; TI_DRC_S-PVSON-N10
U11: TPS54821; TI_RHL_S-PVQFN-N14
U12: ON_CAT24C256; IPC_SOIC127P600X175-8N
U13, U14: TCA6416ARTW; ti_rtw_s-pwqfn-n24
X1, X2: 40M; IPC_OSCCC320X500X105-4N

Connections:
/main_board_if/EEPROM_A0: R40.1, U12.1
/main_board_if/EEPROM_A1: R39.1, U12.2
/main_board_if/EEPROM_A2: R38.1, U12.3
/main_board_if/EEPROM_VCC: C120.1, J4.6, P8.1, R38.2, R39.2, R40.2, R41.2, U12.8
/main_board_if/EEPROM_WP: P7.1, R41.1, U12.7
/main_board_if/FE_I2C_SCL: J4.4, P6.1, U12.6
/main_board_if/FE_I2C_SDA: J4.2, P5.1, U12.5
/main_board_if/IO_INT#: J4.14, R46.1, U13.22, U14.22
/main_board_if/IO_RESET#: J4.16, R47.2, U13.24, U14.24
/main_board_if/IO_SCL: J4.13, R45.1, U13.19, U14.19
/main_board_if/IO_SDA: J4.15, R44.1, U13.20, U14.20
/main_board_if/USB0_POWER_EN: R6.2, R49.2, U2.4, U14.2
/main_board_if/USB0_POWER_FLT#: D3.2, R7.2, U2.5, U13.14
/main_board_if/USB0_XI: J4.8, R4.2
/main_board_if/USB1_POWER_EN: R14.2, R65.2, U6.4, U14.1
/main_board_if/USB1_POWER_FLT#: D19.2, R15.2, U6.5, U13.17
/main_board_if/USB1_XI: J4.7, R13.2
/main_board_if/VALT_FE_PWRGD: R32.2, R67.2, U11.14, U13.13
/power/DC_IN: J3.1, Q1.D, Q2.D
/power/SW_PH: C116.2, L3.2, U11.11, U11.12
/power/SW_PVIN: C108.1, C109.1, C110.1, Q1.S, Q2.S, R22.2, R29.1, U11.4, U11.5, U11.6
/power/V1P1_FB: R20.1, R25.2, U10.5
/power/V1P1_SW: L2.1, U10.6
/power/V1P8_FB: C106.1, R21.1, R24.2, U10.1
/power/V1P8_SW: L1.2, U10.10
/usb0_interfaces/DM: J1.2, U1.P13, U3.4
/usb0_interfaces/DP: J1.3, U1.P14, U3.3
/usb0_interfaces/ELAS_BUF_MODE: J4.31, U1.C9
/usb0_interfaces/ID: J1.4, U3.1, U13.15
/usb0_interfaces/PCLK: J4.103, U1.A6
/usb0_interfaces/PHY_RESETN: U1.J3, U13.10
/usb0_interfaces/PHY_STATUS: J4.42, U1.E3
/usb0_interfaces/POWER_DOWN0: J4.46, U1.H3
/usb0_interfaces/POWER_DOWN1: J4.52, U1.G3
/usb0_interfaces/PWRPRESENT: J4.32, U1.H11
/usb0_interfaces/RESETN: R1.2, U1.J11, U13.12
/usb0_interfaces/RX_DATA0: J4.85, U1.E2
/usb0_interfaces/RX_DATA1: J4.90, U1.D2
/usb0_interfaces/RX_DATA2: J4.87, U1.D1
/usb0_interfaces/RX_DATA3: J4.91, U1.C1
/usb0_interfaces/RX_DATA4: J4.93, U1.C2
/usb0_interfaces/RX_DATA5: J4.98, U1.B1
/usb0_interfaces/RX_DATA6: J4.94, U1.A2
/usb0_interfaces/RX_DATA7: J4.88, U1.A3
/usb0_interfaces/RX_DATA8: J4.92, U1.B3
/usb0_interfaces/RX_DATA9: J4.97, U1.A4
/usb0_interfaces/RX_DATA10: J4.86, U1.B4
/usb0_interfaces/RX_DATA11: J4.99, U1.B5
/usb0_interfaces/RX_DATA12: J4.106, U1.B8
/usb0_interfaces/RX_DATA13: J4.110, U1.A8
/usb0_interfaces/RX_DATA14: J4.120, U1.A9
/usb0_interfaces/RX_DATA15: J4.112, U1.B9
/usb0_interfaces/RX_DATAK0: J4.104, U1.A7
/usb0_interfaces/RX_DATAK1: J4.100, U1.B7
/usb0_interfaces/RX_ELECIDLE: J4.17, U1.F3
/usb0_interfaces/RX_POLARITY: J4.29, U1.C8
/usb0_interfaces/RX_STATUS0: J4.21, U1.C5
/usb0_interfaces/RX_STATUS1: J4.25, U1.C6
/usb0_interfaces/RX_STATUS2: J4.27, U1.C7
/usb0_interfaces/RX_TERMINATION: J4.19, U1.D3
/usb0_interfaces/RX_VALID: J4.81, U1.F1
/usb0_interfaces/SSRXM: J1.9, U1.F14, U4.4
/usb0_interfaces/SSRXP: J1.10, U1.E14, U4.5
/usb0_interfaces/SSTXM: C6.1, U1.J14
/usb0_interfaces/SSTXM_C: C6.2, J1.6, U4.1
/usb0_interfaces/SSTXP: C5.1, U1.H14
/usb0_interfaces/SSTXP_C: C5.2, J1.7, U4.2
/usb0_interfaces/TX_CLK: J4.65, U1.K1
/usb0_interfaces/TX_DATA0: J4.62, U1.P5
/usb0_interfaces/TX_DATA1: J4.64, U1.N4
/usb0_interfaces/TX_DATA2: J4.66, U1.P3
/usb0_interfaces/TX_DATA3: J4.68, U1.N3
/usb0_interfaces/TX_DATA4: J4.70, U1.P2
/usb0_interfaces/TX_DATA5: J4.76, U1.N2
/usb0_interfaces/TX_DATA6: J4.74, U1.P1
/usb0_interfaces/TX_DATA7: J4.78, U1.N1
/usb0_interfaces/TX_DATA8: J4.82, U1.M1
/usb0_interfaces/TX_DATA9: J4.80, U1.M2
/usb0_interfaces/TX_DATA10: J4.63, U1.L2
/usb0_interfaces/TX_DATA11: J4.61, U1.L3
/usb0_interfaces/TX_DATA12: J4.69, U1.J2
/usb0_interfaces/TX_DATA13: J4.73, U1.H1
/usb0_interfaces/TX_DATA14: J4.75, U1.H2
/usb0_interfaces/TX_DATA15: J4.79, U1.G2
/usb0_interfaces/TX_DATAK0: J4.67, U1.J1
/usb0_interfaces/TX_DATAK1: J4.77, U1.G1
/usb0_interfaces/TX_DEEMPH0: J4.28, U1.L11
/usb0_interfaces/TX_DEEMPH1: J4.30, U1.K11
/usb0_interfaces/TX_DETRX_LPBK: J4.38, U1.M6
/usb0_interfaces/TX_ELECIDLE: J4.44, U1.K3
/usb0_interfaces/TX_MARGIN0: J4.22, U1.M9
/usb0_interfaces/TX_MARGIN1: J4.20, U1.M10
/usb0_interfaces/TX_MARGIN2: J4.18, U1.M11
/usb0_interfaces/TX_ONESZEROS: U1.M4, U13.11
/usb0_interfaces/TX_SWING: J4.40, U1.M5
/usb0_interfaces/ULPI_CLK: J4.56, U1.P11
/usb0_interfaces/ULPI_DATA0: J4.49, U1.N9
/usb0_interfaces/ULPI_DATA1: J4.54, U1.P9
/usb0_interfaces/ULPI_DATA2: J4.60, U1.P8
/usb0_interfaces/ULPI_DATA3: J4.51, U1.N8
/usb0_interfaces/ULPI_DATA4: J4.53, U1.P7
/usb0_interfaces/ULPI_DATA5: J4.55, U1.N7
/usb0_interfaces/ULPI_DATA6: J4.57, U1.P6
/usb0_interfaces/ULPI_DATA7: J4.59, U1.N6
/usb0_interfaces/ULPI_DIR: J4.34, U1.M7
/usb0_interfaces/ULPI_NXT: J4.50, U1.N11
/usb0_interfaces/ULPI_STP: J4.26, U1.M8
/usb0_interfaces/USB3_SHIELD: C7.1, FB2.2, J1.11
/usb0_interfaces/VBUS: C125.1, C126.1, FB1.1, R9.2, U2.6, U2.7, U2.8
/usb0_interfaces/VBUS_RAW: FB1.2, J1.1, U3.5
/usb0_interfaces/VSSOSC: C1.2, C2.2, R5.2, U1.B12, X1.2, X1.4
/usb0_interfaces/XI: C1.1, R4.1, U1.A12, X1.3
/usb0_interfaces/XO: C2.1, U1.A11, X1.1
/usb0_power/A1P1: C39.1, C45.1, C47.1, C49.1, C50.1, C51.1, C52.1, FB5.2, U1.C11, U1.C12, U1.D14, U1.G13, U1.G14, U1.K14, U1.M14
/usb0_power/A1P8: C44.1, C46.1, C48.1, FB4.2, U1.A13, U1.C10, U1.N14
/usb0_power/A3P3: C43.1, FB3.2, U1.P12
/usb1_interfaces/DM: J2.2, U5.P13, U7.4
/usb1_interfaces/DP: J2.3, U5.P14, U7.3
/usb1_interfaces/ELAS_BUF_MODE: J4.137, U5.C9
/usb1_interfaces/ID: J2.4, U7.1, U13.16
/usb1_interfaces/PCLK: J4.147, U5.A6
/usb1_interfaces/PHY_RESETN: U5.J3, U13.7
/usb1_interfaces/PHY_STATUS: J4.101, U5.E3
/usb1_interfaces/POWER_DOWN0: J4.111, U5.H3
/usb1_interfaces/POWER_DOWN1: J4.113, U5.G3
/usb1_interfaces/PWRPRESENT: J4.114, U5.H11
/usb1_interfaces/RESETN: R10.2, U5.J11, U13.6
/usb1_interfaces/RX_DATA0: J4.163, U5.E2
/usb1_interfaces/RX_DATA1: J4.169, U5.D2
/usb1_interfaces/RX_DATA2: J4.165, U5.D1
/usb1_interfaces/RX_DATA3: J4.171, U5.C1
/usb1_interfaces/RX_DATA4: J4.173, U5.C2
/usb1_interfaces/RX_DATA5: J4.175, U5.B1
/usb1_interfaces/RX_DATA6: J4.177, U5.A2
/usb1_interfaces/RX_DATA7: J4.158, U5.A3
/usb1_interfaces/RX_DATA8: J4.179, U5.B3
/usb1_interfaces/RX_DATA9: J4.164, U5.A4
/usb1_interfaces/RX_DATA10: J4.160, U5.B4
/usb1_interfaces/RX_DATA11: J4.166, U5.B5
/usb1_interfaces/RX_DATA12: J4.174, U5.B8
/usb1_interfaces/RX_DATA13: J4.176, U5.A8
/usb1_interfaces/RX_DATA14: J4.180, U5.A9
/usb1_interfaces/RX_DATA15: J4.178, U5.B9
/usb1_interfaces/RX_DATAK0: J4.172, U5.A7
/usb1_interfaces/RX_DATAK1: J4.170, U5.B7
/usb1_interfaces/RX_ELECIDLE: J4.115, U5.F3
/usb1_interfaces/RX_POLARITY: J4.129, U5.C8
/usb1_interfaces/RX_STATUS0: J4.119, U5.C5
/usb1_interfaces/RX_STATUS1: J4.127, U5.C6
/usb1_interfaces/RX_STATUS2: J4.162, U5.C7
/usb1_interfaces/RX_TERMINATION: J4.117, U5.D3
/usb1_interfaces/RX_VALID: J4.161, U5.F1
/usb1_interfaces/SSRXM: J2.9, U5.F14, U8.4
/usb1_interfaces/SSRXP: J2.10, U5.E14, U8.5
/usb1_interfaces/SSTXM: C57.1, U5.J14
/usb1_interfaces/SSTXM_C: C57.2, J2.6, U8.1
/usb1_interfaces/SSTXP: C56.1, U5.H14
/usb1_interfaces/SSTXP_C: C56.2, J2.7, U8.2
/usb1_interfaces/TX_CLK: J4.139, U5.K1
/usb1_interfaces/TX_DATA0: J4.134, U5.P5
/usb1_interfaces/TX_DATA1: J4.136, U5.N4
/usb1_interfaces/TX_DATA2: J4.140, U5.P3
/usb1_interfaces/TX_DATA3: J4.154, U5.N3
/usb1_interfaces/TX_DATA4: J4.152, U5.P2
/usb1_interfaces/TX_DATA5: J4.148, U5.N2
/usb1_interfaces/TX_DATA6: J4.150, U5.P1
/usb1_interfaces/TX_DATA7: J4.146, U5.N1
/usb1_interfaces/TX_DATA8: J4.133, U5.M1
/usb1_interfaces/TX_DATA9: J4.142, U5.M2
/usb1_interfaces/TX_DATA10: J4.138, U5.L2
/usb1_interfaces/TX_DATA11: J4.135, U5.L3
/usb1_interfaces/TX_DATA12: J4.149, U5.J2
/usb1_interfaces/TX_DATA13: J4.151, U5.H1
/usb1_interfaces/TX_DATA14: J4.153, U5.H2
/usb1_interfaces/TX_DATA15: J4.159, U5.G2
/usb1_interfaces/TX_DATAK0: J4.141, U5.J1
/usb1_interfaces/TX_DATAK1: J4.157, U5.G1
/usb1_interfaces/TX_DEEMPH0: J4.37, U5.L11
/usb1_interfaces/TX_DEEMPH1: J4.33, U5.K11
/usb1_interfaces/TX_DETRX_LPBK: J4.89, U5.M6
/usb1_interfaces/TX_ELECIDLE: J4.109, U5.K3
/usb1_interfaces/TX_MARGIN0: J4.41, U5.M9
/usb1_interfaces/TX_MARGIN1: J4.43, U5.M10
/usb1_interfaces/TX_MARGIN2: J4.45, U5.M11
/usb1_interfaces/TX_ONESZEROS: U5.M4, U13.8
/usb1_interfaces/TX_SWING: J4.102, U5.M5
/usb1_interfaces/ULPI_CLK: J4.105, U5.P11
/usb1_interfaces/ULPI_DATA0: J4.123, U5.N9
/usb1_interfaces/ULPI_DATA1: J4.121, U5.P9
/usb1_interfaces/ULPI_DATA2: J4.125, U5.P8
/usb1_interfaces/ULPI_DATA3: J4.122, U5.N8
/usb1_interfaces/ULPI_DATA4: J4.124, U5.P7
/usb1_interfaces/ULPI_DATA5: J4.126, U5.N7
/usb1_interfaces/ULPI_DATA6: J4.128, U5.P6
/usb1_interfaces/ULPI_DATA7: J4.130, U5.N6
/usb1_interfaces/ULPI_DIR: J4.116, U5.M7
/usb1_interfaces/ULPI_NXT: J4.118, U5.N11
/usb1_interfaces/ULPI_STP: J4.39, U5.M8
/usb1_interfaces/USB3_SHIELD: C58.1, FB7.2, J2.11
/usb1_interfaces/VBUS: C128.1, C129.1, FB6.1, R17.2, U6.6, U6.7, U6.8
/usb1_interfaces/VBUS_RAW: FB6.2, J2.1, U7.5
/usb1_interfaces/VSSOSC: C53.2, C54.2, R48.2, U5.B12, X2.2, X2.4
/usb1_interfaces/XI: C53.1, R13.1, U5.A12, X2.3
/usb1_interfaces/XO: C54.1, U5.A11, X2.1
/usb1_power/A1P1: C90.1, C96.1, C98.1, C100.1, C101.1, C102.1, C103.1, FB10.2, U5.C11, U5.C12, U5.D14, U5.G13, U5.G14, U5.K14, U5.M14
/usb1_power/A1P8: C95.1, C97.1, C99.1, FB9.2, U5.A13, U5.C10, U5.N14
/usb1_power/A3P3: C94.1, FB8.2, U5.P12
GND: C3.2, C4.2, C7.2, C8.2, C9.2, C10.2, C11.2, C12.2, C13.2, C14.2, C15.2, C16.2, C17.2, C18.2, C19.2, C20.2, C21.2, C22.2, C23.2, C24.2, C25.2, C26.2, C27.2, C28.2, C29.2, C30.2, C31.2, C32.2, C33.2, C34.2, C35.2, C36.2, C37.2, C38.2, C39.2, C40.2, C41.2, C42.2, C43.2, C44.2, C45.2, C46.2, C47.2, C48.2, C49.2, C50.2, C51.2, C52.2, C55.2, C58.2, C59.2, C60.2, C61.2, C62.2, C63.2, C64.2, C65.2, C66.2, C67.2, C68.2, C69.2, C70.2, C71.2, C72.2, C73.2, C74.2, C75.2, C76.2, C77.2, C78.2, C79.2, C80.2, C81.2, C82.2, C83.2, C84.2, C85.2, C86.2, C87.2, C88.2, C89.2, C90.2, C91.2, C92.2, C93.2, C94.2, C95.2, C96.2, C97.2, C98.2, C99.2, C100.2, C101.2, C102.2, C103.2, C104.2, C105.2, C107.2, C108.2, C109.2, C110.2, C111.2, C112.1, C113.2, C114.2, C115.2, C117.2, C119.2, C120.2, C121.2, C122.2, C123.2, C124.2, C125.2, C126.2, C127.2, C128.2, C129.2, C130.2, C131.2, D1.2, D2.2, D18.2, FB2.1, FB7.1, J1.5, J1.8, J2.5, J2.8, J3.2, J4.A0, J4.A1, J4.A2, J4.A3, J4.B0, J4.B1, J4.B2, J4.B3, J4.C0, J4.C1, J4.C2, J4.C3, P4.1, R1.1, R5.1, R6.1, R8.2, R10.1, R14.1, R16.2, R18.1, R20.2, R21.2, R26.2, R31.1, R33.1, R36.1, R47.1, R48.1, R67.1, U1.B11, U1.B13, U1.B14, U1.D12, U1.E13, U1.F6, U1.F7, U1.F8, U1.F9, U1.F12, U1.F13, U1.G6, U1.G7, U1.G8, U1.G9, U1.G12, U1.H6, U1.H7, U1.H8, U1.H9, U1.H13, U1.J6, U1.J7, U1.J8, U1.J9, U1.J13, U1.K12, U1.L12, U1.M12, U1.M13, U1.N13, U2.1, U2.9, U3.2, U4.3, U5.B11, U5.B13, U5.B14, U5.D12, U5.E13, U5.F6, U5.F7, U5.F8, U5.F9, U5.F12, U5.F13, U5.G6, U5.G7, U5.G8, U5.G9, U5.G12, U5.H6, U5.H7, U5.H8, U5.H9, U5.H13, U5.J6, U5.J7, U5.J8, U5.J9, U5.J13, U5.K12, U5.L12, U5.M12, U5.M13, U5.N13, U6.1, U6.9, U7.2, U8.3, U9.2, U10.0, U10.8, U11.2, U11.3, U11.15, U12.4, U13.9, U13.18, U13.25, U14.9, U14.25
unnamed: C107.1, R26.1, R27.2, U9.4
unnamed: C114.1, U11.9
unnamed: C115.1, R35.1
unnamed: C116.1, U11.13
unnamed: C117.1, R35.2, U11.8
unnamed: C118.2, R36.2, R37.1, U11.7
unnamed: D1.1, R49.1
unnamed: D2.1, R34.1
unnamed: D3.1, R50.2
unnamed: D4.1, R51.1
unnamed: D4.2, U14.17
unnamed: D5.1, R52.1
unnamed: D5.2, U14.16
unnamed: D6.1, R53.1
unnamed: D6.2, U14.15
unnamed: D7.1, R54.1
unnamed: D7.2, U14.14
unnamed: D8.1, R55.1
unnamed: D8.2, U14.13
unnamed: D9.1, R56.1
unnamed: D9.2, U14.12
unnamed: D10.1, R57.1
unnamed: D10.2, U14.11
unnamed: D11.1, R58.1
unnamed: D11.2, U14.10
unnamed: D12.1, R59.1
unnamed: D12.2, U14.8
unnamed: D13.1, R60.1
unnamed: D13.2, U14.7
unnamed: D14.1, R61.1
unnamed: D14.2, U14.6
unnamed: D15.1, R62.1
unnamed: D15.2, U14.5
unnamed: D16.1, R63.1
unnamed: D16.2, U14.4
unnamed: D17.1, R64.1
unnamed: D17.2, U14.3
unnamed: D18.1, R65.1
unnamed: D19.1, R66.2
unnamed: Q1.G, Q2.G, R18.2, R22.1
unnamed: R3.1, U1.L13
unnamed: R3.2, U1.L14
unnamed: R8.1, R9.1, U1.N12
unnamed: R12.1, U5.L13
unnamed: R12.2, U5.L14
unnamed: R16.1, R17.1, U5.N12
unnamed: R19.2, U10.2
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

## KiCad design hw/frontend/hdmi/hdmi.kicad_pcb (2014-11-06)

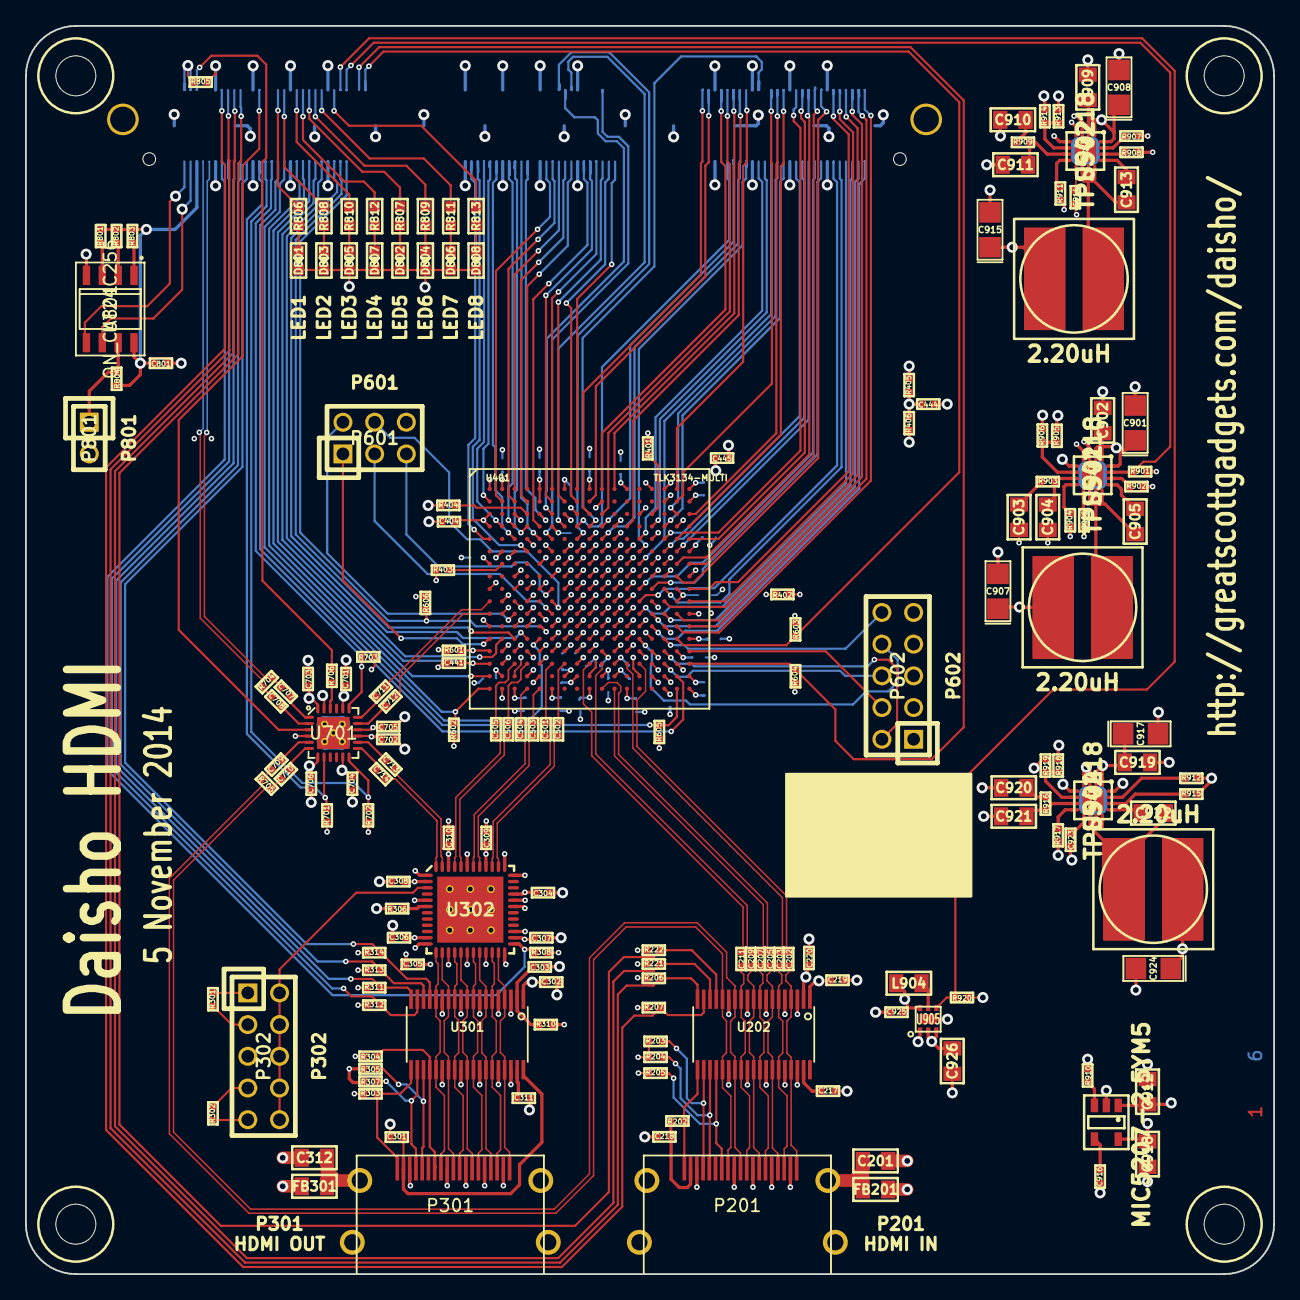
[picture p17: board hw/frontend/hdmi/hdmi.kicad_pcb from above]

Board: 6 copper layers, 100.0 x 100.0 mm, 228 parts (0 on the bottom side), 237 nets.

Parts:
C201, C312: DNP; GSG-0805
C202, C203, C205, C207, C209, C211, C218, C219, C220, C301, C302, C303, C501, C502, C503, C504, C505, C506, C701, C702, C703, C704, C705, C706, C707, C708, C709, C710, C711, C712, C713, C714, C801: 0.1uF; GSG-0402
C217, C311: 0.1uF 10V; GSG-0402
C304, C305, C306, C307, C308, C309, C310, C407, C409, C411, C414, C416, C417, C419, C421, C422, C423, C424, C425, C426, C434, C436, C437, C439, C442, C443, C445, C447, C448, C449, C450, C451: 0.01uF; GSG-0402
C401, C402, C404, C925: 2.2uF; GSG-0402
C403, C406, C408, C418, C433, C444: 1uF; GSG-0402
C405, C410, C412, C420, C432, C435: 0.47uF; GSG-0402
C413, C427, C428, C440: 100pF; GSG-0402
C415, C429, C430, C431, C438, C441: 10pF; GSG-0402
C901, C907, C908, C915, C917, C924: 22uF; gsg-sm1206p
C902, C905, C909, C913, C919, C922: 100nF; GSG-0805
C903, C920: 27nF; GSG-0805
C904, C921: 82pF; GSG-0805
C906, C914, C923: 12nF; GSG-0402
C910: 22nF; GSG-0805
C911: 100pF; GSG-0805
C912, C918, C926: 10uF; GSG-0805
C916: 470pF; GSG-0402
D801: LED1; GSG-0603D
D802: LED5; GSG-0603D
D803: LED2; GSG-0603D
D804: LED6; GSG-0603D
D805: LED3; GSG-0603D
D806: LED7; GSG-0603D
D807: LED4; GSG-0603D
D808: LED8; GSG-0603D
FB201, FB301: FILTER; GSG-0805
H1, H2, H3, H4: HOLE; GSG-HOLE126MIL
J801: SAMTEC_QSH-090-D; SAMTEC_QSH-090-01-F-D-A
L901, L902, L903: 2.20uH; TDK_VLP8040
L904: 1uH; GSG-0805
P201, P301: HDMI; 10029449-111RLF
P302, P602: CONN_02X05; GSG-HEADER-2x5
P601: CONN_02X03; GSG-HEADER-2x3
P801: CONN_01X02; GSG-HEADER-1x2
R202: 1k; GSG-0402
R203, R204, R207, R221, R222, R312, R313, R314: 47k; GSG-0402
R205, R304: 27k; GSG-0402
R206, R311: 100k; GSG-0402
R301, R302, R303, R308, R310, R601, R602, R603, R604, R805, R901, R902, R907, R908, R910, R912, R915, R920: 10k; GSG-0402
R305, R307: 1k8; GSG-0402
R306: 10k 1%; GSG-0402
R401, R402, R405, R406: 150 0.5%; GSG-0402
R403, R404: 50 0.5%; GSG-0402
R605, R606, R701, R702, R703: 1.5k; GSG-0402
R704, R705: 100; GSG-0402
R706: 20; GSG-0402
R801, R802, R803, R804: DNP; GSG-0402
R806, R807, R808, R809, R810, R811, R812, R813: 180; GSG-0603
R903, R916: 2.87k; GSG-0402
R904, R911, R917: 158k 1%; GSG-0402
R905: 210k 1%; GSG-0402
R906, R914: 105k 1%; GSG-0402
R909: 3.24k; GSG-0402
R913, R919: 120k 1%; GSG-0402
R918: 38.3k 1%; GSG-0402
U202: TPD12S520; GSG-TSSOP38
U301: TPD12S521; GSG-TSSOP38
U302: PTN3360DBS; QFN48-7
U401: TLK3134-MULTI; PBGA-289
U701: SI5338B; GSG-QFN24
U801: ON_CAT24C256; IPC_SOIC127P600X175-8N
U901, U902, U904: TPS54218; TI_RTE_S-PWQFN-N16
U903: MIC5207-2.5YM5; IPC_SOT95P280X110-5N
U905: FAN4860UMP; ULMP-6

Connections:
/HDMI Input/IN_SHELL: C201.1, FB201.1, P201.20
/HDMI Output/HDMI_OUT_CK_M_SHIFTED: P301.12, U301.15, U301.24, U302.13
/HDMI Output/HDMI_OUT_CK_P_SHIFTED: P301.10, U301.13, U301.26, U302.14
/HDMI Output/HDMI_OUT_D0_M_SHIFTED: P301.9, U301.12, U301.27, U302.16
/HDMI Output/HDMI_OUT_D0_P_SHIFTED: P301.7, U301.10, U301.29, U302.17
/HDMI Output/HDMI_OUT_D1_M_SHIFTED: P301.6, U301.9, U301.30, U302.19
/HDMI Output/HDMI_OUT_D1_P_SHIFTED: P301.4, U301.7, U301.32, U302.20
/HDMI Output/HDMI_OUT_D2_M_SHIFTED: P301.3, U301.6, U301.33, U302.22
/HDMI Output/HDMI_OUT_D2_P_SHIFTED: P301.1, U301.4, U301.35, U302.23
/HDMI Output/OUT_SHELL: C312.1, FB301.1, P301.20
/Mezzanine/EEPROM_A0: R803.2, U801.1
/Mezzanine/EEPROM_A1: R802.2, U801.2
/Mezzanine/EEPROM_A2: R801.2, U801.3
/Mezzanine/EEPROM_WP: P801.1, R804.2, U801.7
/Mezzanine/FE_I2C_SCL: J801.4, U801.6
/Mezzanine/FE_I2C_SDA: J801.2, U801.5
/Mezzanine/FE_I2C_VCC: C801.1, J801.6, R801.1, R802.1, R803.1, R804.1, U801.8
/Mezzanine/LED1: J801.31, R806.1
/Mezzanine/LED2: J801.33, R808.1
/Mezzanine/LED3: J801.37, R810.1
/Mezzanine/LED4: J801.39, R812.1
/Mezzanine/LED5: J801.41, R807.1
/Mezzanine/LED6: J801.43, R809.1
/Mezzanine/LED7: J801.45, R811.1
/Mezzanine/LED8: J801.49, R813.1
/Mezzanine/VALT_FE: J801.1, J801.3, R805.2
/Serdes Power/VREF: C444.1, C445.1, R405.2, R406.1, U401.A14, U401.H14
CEC_IN_SUPP: J801.19, R222.1, U202.16
CLK_HDMI_OUT_M: C714.1, U302.48
CLK_HDMI_OUT_P: C713.1, U302.47
CLK_IN_M_SUPP: C709.2, P201.12, R705.1, U202.15, U202.24
CLK_IN_P_SUPP: C710.2, P201.10, R705.2, U202.13, U202.26
DATA0_IN_M_SUPP: C211.1, P201.9, U202.12, U202.27
DATA0_IN_P_SUPP: C209.1, P201.7, U202.10, U202.29
DATA1_IN_M_SUPP: C207.1, P201.6, U202.9, U202.30
DATA1_IN_P_SUPP: C205.1, P201.4, U202.7, U202.32
DATA2_IN_M_SUPP: C203.1, P201.3, U202.6, U202.33
DATA2_IN_P_SUPP: C202.1, P201.1, U202.4, U202.35
FE_CLKSRC: J801.5, R706.1
FE_CLK_AUX: J801.25, U701.3
FE_CLK_N0: C707.2, J801.10, R704.1
FE_CLK_P0: C708.2, J801.8, R704.2
GND: C201.2, C217.1, C218.2, C219.1, C220.2, C301.2, C302.1, C303.2, C304.2, C305.2, C306.2, C307.2, C308.2, C309.2, C310.2, C311.1, C312.2, C401.2, C402.2, C403.2, C404.2, C405.2, C406.2, C407.2, C408.2, C409.2, C410.2, C411.2, C412.2, C413.2, C414.2, C415.2, C416.2, C417.2, C418.2, C419.2, C420.2, C421.2, C422.2, C423.2, C424.2, C425.2, C426.2, C427.2, C428.2, C429.2, C430.2, C431.2, C432.2, C433.2, C434.2, C435.2, C436.2, C437.2, C438.2, C439.2, C440.2, C441.2, C442.2, C443.2, C444.2, C445.2, C447.2, C448.2, C449.2, C450.2, C451.2, C701.1, C702.2, C703.2, C704.2, C705.2, C706.2, C801.2, C901.2, C902.2, C903.2, C904.2, C906.1, C907.2, C908.2, C909.2, C910.2, C911.2, C912.2, C914.1, C915.2, C916.2, C917.2, C918.2, C919.2, C920.2, C921.2, C923.1, C924.2, C925.2, C926.2, D801.2, D802.2, D803.2, D804.2, D805.2, D806.2, D807.2, D808.2, FB201.2, FB301.2, J801.A0, J801.A1, J801.A2, J801.A3, J801.B0, J801.B1, J801.B2, J801.B3, J801.C0, J801.C1, J801.C2, J801.C3, P201.2, P201.5, P201.8, P201.11, P201.17, P301.2, P301.5, P301.8, P301.11, P301.17, P302.1, P601.6, P602.3, P602.5, P602.9, P801.2, R301.1, R303.2, R306.1, R401.2, R402.2, R403.2, R404.2, R406.2, R601.2, R602.2, R603.2, R604.2, R901.1, R904.2, R905.1, R911.2, R913.1, R917.2, R918.2, R920.2, U202.3, U202.5, U202.8, U202.11, U202.14, U202.25, U202.28, U202.31, U202.34, U202.36, U301.3, U301.5, U301.8, U301.11, U301.14, U301.25, U301.28, U301.31, U301.34, U301.36, U302.0, U302.1, U302.5, U302.12, U302.18, U302.24, U302.27, U302.31, U302.32, U302.36, U302.37, U302.43, U401.A1, U401.A7, U401.A17, U401.B10, U401.C3, U401.C13, U401.D6, U401.D16, U401.E9, U401.F2, U401.F12, U401.G5, U401.G7, U401.G8, U401.G9, U401.G10, U401.G11, U401.G15, U401.H7, U401.H8, U401.H9, U401.H10, U401.H11, U401.H12, U401.J1, U401.J3, U401.J4, U401.J8, U401.J9, U401.J10, U401.J11, U401.K3, U401.K4, U401.K7, U401.K8, U401.K9, U401.K10, U401.K11, U401.K12, U401.K14, U401.L5, U401.L7, U401.L8, U401.L9, U401.L10, U401.L11, U401.L17, U401.M3, U401.M4, U401.M6, U401.M7, U401.M8, U401.M9, U401.M10, U401.M11, U401.M13, U401.P2, U401.P4, U401.P5, U401.P6, U401.P8, U401.P10, U401.P12, U401.P13, U401.R2, U401.T3, U401.T5, U401.T8, U401.T11, U401.T14, U401.T15, U401.U2, U401.U17, U701.0, U701.4, U701.23, U801.4, U901.3, U901.4, U901.5, U901.17, U902.3, U902.4, U902.5, U902.17, U903.2, U904.3, U904.4, U904.5, U904.17, U905.0, U905.1
HDMI_CEC_OUT: J801.22, R314.1, U301.16
HDMI_HPD_OUT: J801.18, R311.1, U301.19
HDMI_OUT_EN: J801.14, R308.2, U302.25
HDMI_SCL_OUT: J801.20, R313.1, U301.17
HDMI_SDA_OUT: J801.16, R312.1, U301.18
HPD_IN_SUPP: J801.15, R206.1, U202.19
unnamed: C217.2, U202.37
unnamed: C218.1, P201.18, R202.1
unnamed: C301.1, P301.18, U301.38
unnamed: C303.1, R310.2, U301.2
unnamed: C311.2, U301.37
unnamed: C501.1, U401.R6
unnamed: C502.1, U401.R7
unnamed: C503.1, U401.U5
unnamed: C504.1, U401.U4
unnamed: C505.1, U401.R3
unnamed: C506.1, U401.R4
unnamed: C707.1, U701.1
unnamed: C708.1, U701.2
unnamed: C709.1, U701.5
unnamed: C710.1, U701.6
unnamed: C711.2, U701.18
unnamed: C712.2, U701.17
unnamed: C713.2, U701.14
unnamed: C714.2, U701.13
unnamed: C903.1, R903.2
unnamed: C904.1, R903.1, U901.7
unnamed: C905.1, U901.13
unnamed: C905.2, L901.1, U901.10, U901.11, U901.12
unnamed: C906.2, U901.9
unnamed: C910.1, R909.2
unnamed: C911.1, R909.1, U902.7
unnamed: C913.1, U902.13
unnamed: C913.2, L902.1, U902.10, U902.11, U902.12
unnamed: C914.2, U902.9
unnamed: C916.1, U903.4
unnamed: C920.1, R916.2
unnamed: C921.1, R916.1, U904.7
unnamed: C922.1, U904.13
unnamed: C922.2, L903.1, U904.10, U904.11, U904.12
unnamed: C923.2, U904.9
unnamed: D801.1, R806.2
unnamed: D802.1, R807.2
unnamed: D803.1, R808.2
unnamed: D804.1, R809.2
unnamed: D805.1, R810.2
unnamed: D806.1, R811.2
unnamed: D807.1, R812.2
unnamed: D808.1, R813.2
unnamed: L904.1, U905.5
unnamed: P201.13, R205.1, U202.23
unnamed: P201.15, R204.1, U202.22
unnamed: P201.16, R203.1, U202.21
unnamed: P201.19, R202.2, U202.20
unnamed: P301.13, R304.2, U301.23
unnamed: P301.15, R305.2, U301.22
unnamed: P301.16, R307.2, U301.21
unnamed: P301.19, R303.1, U301.20
unnamed: P302.3, R301.2
unnamed: P302.9, R302.2
unnamed: P302.2, P302.4, P302.6, P302.8, P302.10, U302.3
unnamed: R306.2, U302.6
unnamed: R401.1, U401.C14
unnamed: R402.1, U401.H15
unnamed: R403.1, U401.G2
unnamed: R404.1, U401.C4
unnamed: R706.2, U701.22
unnamed: R902.2, U901.14
unnamed: R904.1, U901.8
unnamed: R905.2, R906.2, U901.6
unnamed: R907.1, U902.15
unnamed: R908.1, U902.14
unnamed: R910.1, U903.3
unnamed: R911.1, U902.8
unnamed: R912.2, U904.15
unnamed: R913.2, R914.2, U902.6
unnamed: R915.2, U904.14
unnamed: R917.1, U904.8
unnamed: R918.1, R919.1, U904.6
SCL_IN_SUPP: J801.17, R221.1, U202.17
SDA_IN_SUPP: J801.13, R207.1, U202.18
SD_CH0_RX0: J801.140, U401.E10
SD_CH0_RX1: J801.138, U401.D10
SD_CH0_RX2: J801.137, U401.A11
SD_CH0_RX3: J801.127, U401.C9
SD_CH0_RX4: J801.133, U401.A10
SD_CH0_RX5: J801.129, U401.B9
SD_CH0_RX6: J801.136, U401.D8
SD_CH0_RX7: J801.118, U401.B8
SD_CH0_RX8: J801.135, U401.C10
SD_CH0_RX9: J801.110, U401.D5
SD_CH0_RXCLK: J801.145, U401.D9
SD_CH0_TX0: J801.179, U401.M16
SD_CH0_TX1: J801.178, U401.L14
SD_CH0_TX2: J801.174, U401.L13
SD_CH0_TX3: J801.175, U401.L16
SD_CH0_TX4: J801.177, U401.M17
SD_CH0_TX5: J801.173, U401.K15
SD_CH0_TX6: J801.169, U401.J17
SD_CH0_TX7: J801.172, U401.J15
SD_CH0_TX8: J801.176, U401.L15
SD_CH0_TX9: J801.151, U401.C17
SD_CH0_TXCLK: J801.180, U401.M14
SD_CH1_RX0: J801.120, U401.A8
SD_CH1_RX1: J801.114, U401.A6
SD_CH1_RX2: J801.112, U401.B6
SD_CH1_RX3: J801.106, U401.A4
SD_CH1_RX4: J801.104, U401.B4
SD_CH1_RX5: J801.92, U401.C5
SD_CH1_RX6: J801.100, U401.B3
SD_CH1_RX7: J801.102, U401.A3
SD_CH1_RX8: J801.101, U401.E8
SD_CH1_RX9: J801.86, U401.D3
SD_CH1_RXCLK: J801.105, U401.D7
SD_CH1_TX0: J801.166, U401.J14
SD_CH1_TX1: J801.164, U401.J13
SD_CH1_TX2: J801.163, U401.G17
SD_CH1_TX3: J801.150, U401.G13
SD_CH1_TX4: J801.161, U401.G16
SD_CH1_TX5: J801.160, U401.F15
SD_CH1_TX6: J801.159, U401.E17
SD_CH1_TX7: J801.157, U401.E16
SD_CH1_TX8: J801.171, U401.K17
SD_CH1_TX9: J801.141, U401.A16
SD_CH1_TXCLK: J801.170, U401.K13
SD_CH2_RX0: J801.115, U401.E6
SD_CH2_RX1: J801.98, U401.B2
SD_CH2_RX2: J801.88, U401.D4
SD_CH2_RX3: J801.80, U401.B1
SD_CH2_RX4: J801.90, U401.E5
SD_CH2_RX5: J801.78, U401.D2
SD_CH2_RX6: J801.82, U401.E3
SD_CH2_RX7: J801.74, U401.E1
SD_CH2_RX8: J801.116, U401.B7
SD_CH2_RX9: J801.76, U401.F4
SD_CH2_RXCLK: J801.103, U401.C6
SD_CH2_TX0: J801.158, U401.E15
SD_CH2_TX1: J801.153, U401.D17
SD_CH2_TX2: J801.152, U401.C16
SD_CH2_TX3: J801.142, U401.F13
SD_CH2_TX4: J801.154, U401.D15
SD_CH2_TX5: J801.149, U401.B16
SD_CH2_TX6: J801.146, U401.E13
SD_CH2_TX7: J801.148, U401.D14
SD_CH2_TX8: J801.165, U401.H16
SD_CH2_TX9: J801.139, U401.D12
SD_CH2_TXCLK: J801.162, U401.F16
SERDES_ENABLE: J801.40, R602.1, U401.U1
SERDES_GPO0: P601.1, U401.N1
SERDES_GPO1: P601.2, U401.L3
SERDES_GPO2: P601.3, U401.L6
SERDES_GPO3: P601.4, U401.K6
SERDES_GPO4: P601.5, U401.J6
SERDES_HDMI_IN0_M: C211.2, U401.R9
SERDES_HDMI_IN0_P: C209.2, U401.R10
SERDES_HDMI_IN1_M: C207.2, U401.U11
SERDES_HDMI_IN1_P: C205.2, U401.U10
SERDES_HDMI_IN2_M: C203.2, U401.R12
SERDES_HDMI_IN2_P: C202.2, U401.R13
SERDES_HDMI_OUT0_M: C506.2, U302.44
SERDES_HDMI_OUT0_P: C505.2, U302.45
SERDES_HDMI_OUT1_M: C504.2, U302.42
SERDES_HDMI_OUT1_P: C503.2, U302.41
SERDES_HDMI_OUT2_M: C502.2, U302.38
SERDES_HDMI_OUT2_P: C501.2, U302.39
SERDES_MDC: J801.32, U401.T16
SERDES_MDIO_ST: J801.54, R606.1, U401.M5
SERDES_MDO: J801.34, R605.1, U401.U16
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

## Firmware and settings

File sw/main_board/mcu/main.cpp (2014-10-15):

/* 
 * Monulator ARM LPC11U14 application.
 * 
 * Copyright (C) 2013 Jared Boone, ShareBrained Technology, Inc.
 * 
 * This file is part of the Monulator project.
 * 
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
 * You should have received a copy of the GNU General Public License
 * along with this program; if not, write to the Free Software
 * Foundation, Inc., 51 Franklin Street, Fifth Floor, Boston, MA
 * 02110-1301, USA.
 */

#include "lpc11u.h"
#include "serial.h"

#include "i2c.h"
#include "si5351c.h"

#include <cstdint>

void turn_on_crystal_oscillator() {
	SCB.SYSOSCCTRL = 0;
	SCB.enable_power(SCB.PDRUNCFG_SYSOSC);
}

void start_system_pll() {
	// Start up system PLL: 12MHz crystal to 48 MHz.
	SCB.set_system_pll_dividers(1, 3);
	SCB.set_system_pll_clock_source(SCB.SYSPLLCLKSEL_SEL_CRYSTAL_OSCILLATOR);
	SCB.enable_power(SCB.PDRUNCFG_SYSPLL);
	SCB.wait_for_system_pll_lock();
}

void set_main_clock_to_system_pll() {
	// Switch main (and system clocks) to system PLL
	SCB.set_main_clock_source(SCB.MAINCLKSEL_SEL_PLL_OUTPUT);
}

void start_usb_pll() {
	// Start up USB PLL: 12MHz crystal to 48 MHz.
	SCB.set_usb_pll_dividers(1, 3);
	SCB.set_usb_pll_clock_source(SCB.USBPLLCLKSEL_SEL_SYSTEM_OSCILLATOR);
	SCB.enable_power(SCB.PDRUNCFG_USBPLL);
	SCB.wait_for_usb_pll_lock();
}

void set_usb_clock_to_main_clock() {
	// NOTE: Both clock sources must be running in order to switch!
	// So if you want to use the main clock instead of the USB PLL,
	// you have to start the USB PLL in order to switch away from it!
	SCB.set_usb_clock_source(SCB.USBCLKSEL_SEL_MAIN_CLOCK);
}

void set_usb_clock_to_usb_pll() {
	SCB.set_usb_clock_source(SCB.USBCLKSEL_SEL_USB_PLL_OUT);
}

void enable_peripheral_clocks() {
	SCB.set_system_clock_divider(1);
	SCB.enable_clocks(
		  SCB.SYSAHBCLKCTRL_GPIO
		//| SCB.SYSAHBCLKCTRL_CT16B0
		//| SCB.SYSAHBCLKCTRL_CT16B1
		//| SCB.SYSAHBCLKCTRL_CT32B0
		//| SCB.SYSAHBCLKCTRL_CT32B1
		| SCB.SYSAHBCLKCTRL_I2C
		| SCB.SYSAHBCLKCTRL_USART
		//| SCB.SYSAHBCLKCTRL_SSP1
		//| SCB.SYSAHBCLKCTRL_USB
		| SCB.SYSAHBCLKCTRL_IOCON
		//| SCB.SYSAHBCLKCTRL_RAM1	// Available on larger parts.
		| SCB.SYSAHBCLKCTRL_USBRAM
	);
}

void enable_clock_output() {
	SCB.set_clkout_clock_source(SCB.CLKOUTSEL_SEL_MAIN_CLOCK);
	SCB.set_clkout_divider(48);
	IOCON.PIO0_1 = 1;
}

void write_led_status(const uint_fast8_t value) {
	GPIO_PORT.write(0, 1, value);
}

void write_ddr2_sa(const uint_fast8_t value) {
	GPIO_PORT.write(0,  7, value & 2);
	GPIO_PORT.write(1, 24, value & 1);
}

void write_fe_en(const uint_fast8_t value) {
	GPIO_PORT.write(0, 20, value);
}

void fe_disable() {
	write_fe_en(0);
}

void fe_enable() {
	write_fe_en(1);
}

void write_v3p3a_enable(const uint_fast8_t value) {
	GPIO_PORT.write(0, 14, value);
}

void v3p3a_enable() {
	write_v3p3a_enable(1);
}

void v3p3a_disable() {
	write_v3p3a_enable(0);
}

void write_v2p5_enable(const uint_fast8_t value) {
	GPIO_PORT.write(0, 16, value);
}

void v2p5_enable() {
	write_v2p5_enable(1);
}

void v2p5_disable() {
	write_v2p5_enable(0);
}

void write_v1p8_enable(const uint_fast8_t value) {
	GPIO_PORT.write(1, 28, value);
}

void v1p8_enable() {
	write_v1p8_enable(1);
}

void v1p8_disable() {
	write_v1p8_enable(0);
}

void write_v1p2_enable(const uint_fast8_t value) {
	GPIO_PORT.write(0, 18, value);
}

void v1p2_enable() {
	write_v1p2_enable(1);
}

void v1p2_disable() {
	write_v1p2_enable(0);
}

void write_v1p1_enable(const uint_fast8_t value) {
	GPIO_PORT.write(0, 17, value);
}

void v1p1_enable() {
	write_v1p1_enable(1);
}

void v1p1_disable() {
	write_v1p1_enable(0);
}

void write_clockgen_oeb_n(const uint_fast8_t value) {
	GPIO_PORT.write(1, 14, value);
}

void clockgen_output_enable() {
	write_clockgen_oeb_n(0);
}

void clockgen_output_disable() {
	write_clockgen_oeb_n(1);
}

void write_v1px_smps_mode(const uint_fast8_t value) {
	GPIO_PORT.write(1, 25, value);
}

bool read_fpga_status() {
	return GPIO_PORT.read(1, 16) == 0;
}

bool read_fpga_conf_done() {
	return GPIO_PORT.read(0, 19) == 1;
}

void configure_pins() {
	// Configure port 0 pin directions
	GPIO_PORT.DIR0 |=
		  (1 << 20)	// FE_EN
		| (1 << 18)	// V1P2_ENABLE
		| (1 << 17)	// V1P1_ENABLE
		| (1 << 16)	// V2P5_ENABLE
		| (1 << 14)	// V3P3A_ENABLE
		| (1 << 13)	// USB_POWER_EN
		| (1 <<  7)	// DDR2_SA1
		| (1 <<  1)	// LED_STATUS
		;
	
	// Configure port 1 pin directions
	GPIO_PORT.DIR1 |=
		  (1 << 28)	// V1P8_ENABLE
		| (1 << 25)	// V1PX_SMPS_MODE
		| (1 << 24)	// DDR2_SA0
		| (1 << 14)	// CLOCKGEN_OEB#
		;
	
	// Set GPIO initial pin values
	write_led_status(0);
	write_ddr2_sa(0);
	fe_disable();
	v3p3a_disable();
	v2p5_disable();
	v1p8_disable();
	v1p2_disable();
	v1p1_disable();
	clockgen_output_disable();
	write_v1px_smps_mode(0);
	
	bool enable_fpga_jtag_interface = false;
	
	// Set pin multiplexers and behaviors
	IOCON.PIO0_1 = 0;		// PIO0_1: LED_STATUS (out), TODO: PWM control.
	IOCON.PIO0_2 = 1;		// SSEL0: SD_CS#
	IOCON.PIO0_3 = 1;		// USB_VBUS, TODO: needs pull-down?
	IOCON.PIO0_4 = 1;		// SCL: I2C_SCL
	IOCON.PIO0_5 = 1;		// SDA: I2C_SDA
	IOCON.PIO0_6 = 1;		// USB_CONNECT#
	IOCON.PIO0_7 = 0;		// PIO0_7: DDR2_SA1 (out)
	IOCON.PIO0_8 = 1;		// MISO0: SD_MISO
	IOCON.PIO0_9 = 1;		// MOSI0: SD_MOSI
	IOCON.TDI_PIO0_11 = 1;	// PIO0_11: ALT_SW_STAT (in)
	IOCON.TMS_PIO0_12 = 1;	// PIO0_12: USB_POWER_FLT# (in)
	IOCON.TDO_PIO0_13 = 1;	// PIO0_13: USB_POWER_EN (out)
	IOCON.TRST_PIO0_14 = 1;	// PIO0_14: V3P3A_ENABLE (out)
	IOCON.PIO0_16 = 0;		// PIO0_16: V2P5_ENABLE (out)
	IOCON.PIO0_17 = 0;		// PIO0_17: V1P1_ENABLE (out)
	IOCON.PIO0_18 = 0;		// PIO0_18: V1P2_ENABLE (out)
	IOCON.PIO0_19 = 0;		// PIO0_19: FPGA_CONF_DONE (in)
	IOCON.PIO0_20 = 0;		// PIO0_20: FE_EN (out)
	if( enable_fpga_jtag_interface ) {
		IOCON.PIO0_21 = 2;		// MOSI1: FPGA_TDI, TODO: Overloaded with SPI_MOSI
	} else {
		IOCON.PIO0_21 = 0;
	}
	IOCON.PIO0_22 = 3;		// MISO1: FPGA_MISO_V3P3, TODO: Overloaded with FPGA_TDO_V3P3
	IOCON.PIO0_23 = 0;		// PIO0_23: SD_DET (in)
	
	IOCON.PIO1_13 = 0;		// PIO1_13: CLOCKGEN_INTR# (in)
	IOCON.PIO1_14 = 0;		// PIO1_14: CLOCKGEN_OEB# (out)
	IOCON.PIO1_15 = 3;		// SCK1: SPI_SCK, TODO: Overloaded with FPGA_TCK
	IOCON.PIO1_16 = 0;		// PIO1_16: FPGA_NSTATUS (in)
	IOCON.PIO1_19 = 2;		// SSEL1: SPI_SS, TODO: Overloaded with FPGA_TMS
	if( enable_fpga_jtag_interface ) {
		IOCON.PIO1_20 = 2;		// SCK1: FPGA_TCK, TODO: Overloaded with SPI_SCK
		IOCON.PIO1_21 = 2;		// MISO1: FPGA_TDO_V3P3, TODO: Overloaded with FPGA_MISO_V3P3
	} else {
		IOCON.PIO1_20 = 0;
		IOCON.PIO1_21 = 0;
	}
	IOCON.PIO1_22 = 2;		// MOSI1: SPI_MOSI, TODO: Overloaded with FPGA_TDI
	if( enable_fpga_jtag_interface ) {
		IOCON.PIO1_23 = 2;		// SSEL1: FPGA_TMS, TODO: Overloaded with SPI_SS
	} else {
		IOCON.PIO1_23 = 0;
	}
	IOCON.PIO1_24 = 0;		// PIO1_24: DDR2_SA0 (out)
	IOCON.PIO1_25 = 0;		// PIO1_25: V1PX_SMPS_MODE (out)
	IOCON.PIO1_26 = 2;		// RXD: RXD
	IOCON.PIO1_27 = 2;		// TXD: TXD
	IOCON.PIO1_28 = 0;		// PIO1_28: V1P8_ENABLE (out)
	IOCON.PIO1_29 = 1;		// SCK0: SD_SCK
	IOCON.PIO1_31 = 0;		// PIO1_31: V1P8_PWRGD (in)
	
	SCB.enable_power(SCB.PDRUNCFG_USBPAD);
}

extern "C" int main() {
	turn_on_crystal_oscillator();
	start_system_pll();
	start_usb_pll();
	set_main_clock_to_system_pll();
	enable_peripheral_clocks();
	serial_init();

	configure_pins();
	delay(1000000);
	
	//enable_clock_output();
	
	NVIC.enable_interrupts();

	//serial_write_string("main():loop");
	//serial_write_line();
	
	// Power for FPGA
	v1p2_enable();	// FPGA VCCINT
	v2p5_enable();	// FPGA PLLs?
	v1p8_enable();	// FPGA VCCIOs, DDR2.
	v1p1_enable();	// USB internal voltage
	delay(1000000);

	// Power for the clock generator.
	// V3P3A must be turned on *after* V1P8 to satisfy
	// Si5351C requirement.
	v3p3a_enable();
	delay(1000000);
	
	// I2C configuration
	i2c0_init(500);
	
	// Give Si5351C time to power up?
	delay(100000);
	si5351c_disable_all_outputs();
	//si5351c_disable_oeb_pin_control();
	si5351c_power_down_all_clocks();
	si5351c_set_crystal_configuration();
	si5351c_enable_xo_and_ms_fanout();
	si5351c_configure_pll_sources_for_xtal();
	si5351c_configure_pll1_multisynth();
	
	si5351c_configure_multisynth(4, 1536, 0, 1, 0); // 50MHz
	si5351c_configure_multisynth(5, 1536, 0, 1, 0); // 50MHz
	si5351c_configure_multisynths_6_and_7();
	
	si5351c_configure_clock_control();
	si5351c_enable_clock_outputs();
	clockgen_output_enable();

	fe_enable();

	while(true) {
		//write_led_status(read_fpga_conf_done());
		write_led_status(1);
		delay(1000000);
		write_led_status(0);
		delay(1000000);
	}
	
	return 0;
}

extern "C" void SystemInit() {
	
}

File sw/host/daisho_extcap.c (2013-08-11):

#include <stdio.h>
#include <getopt.h>
#include <stdint.h>
#include <string.h>
#include <unistd.h>

void list_interfaces() {
	/* Adapt to count attached Daisho devices in future
	 * Identify them by bus/device number or serial?
	 */
	printf("interface {display=Daisho0}{value=/dev/ttyUSB0}\n");
	printf("interface {display=Daisho1}{value=/dev/ttyUSB1}\n");
	printf("interface {display=Daisho2}{value=/dev/ttyUSB2}\n");
}

void list_dlts() {
	printf("dlt {number=1}{name=EN10MB}{display=Ethernet (Daisho)}\n");
}

void show_config() {
	return;
	printf("arg {number=0}{call=device}{display=Serial Device}{type=selector}\n");

}

void spawn_daisho_en_uart(char *source, char *fifo) {
	fprintf(stderr, "daisho-en-uart -s %s -p %s\n", source, fifo);
	execlp("daisho-en-uart", "daisho-en-uart", "-s", source, "-p", fifo, NULL);
}

typedef enum {
	LIST_INTERFACES,
	CONFIG,
	INTERFACE,
	LIST_DLTS,
	CAPTURE,
	FIFO
} options;

int main(int argc, char *argv[]) {
	// Turn off the getopt error reporting
	opterr = 0;
	optind = 0;
	int arg, option_idx = 0;
	int do_daisho_en_uart = 0, do_config = 0, do_dlts = 0;
	char *fifo = NULL;
	char *interface = NULL;

	static struct option longopts[] = {
		{ "list-interfaces", no_argument, 0, LIST_INTERFACES},
		{ "config", no_argument, 0, CONFIG},
		{ "interface", required_argument, 0, INTERFACE},
		{ "list-dlts", no_argument, 0, LIST_DLTS},
		{ "capture", no_argument, 0, CAPTURE},
		{ "fifo", required_argument, 0, FIFO},
		{ 0, 0, 0, 0 }
	};

	while ((arg = getopt_long(argc, argv, "", longopts, &option_idx)) >= 0) {
		switch (arg) {
			case LIST_INTERFACES:
				list_interfaces();
				return 0;
			case CONFIG:
				do_config = 1;
				break;
			case INTERFACE:
				interface = strdup(optarg);
				break;
			case LIST_DLTS:
				do_dlts = 1;
				break;
			case CAPTURE:
				do_daisho_en_uart = 1;
				break;
			case FIFO:
				fifo = strdup(optarg);
				break;
		}
	}

	if (do_daisho_en_uart) {
		if (fifo == NULL)
			return(1);

		spawn_daisho_en_uart(interface, fifo);
	}

	if (do_config) {
		if (interface == NULL)
			return(1);

		if (strcmp(interface, "/dev/ttyUSB0") != 0 &&
			strcmp(interface, "/dev/ttyUSB1") != 0 &&
			strcmp(interface, "/dev/ttyUSB2") != 0)
			return(1);

		show_config();

		return(0);
	}

	if (do_dlts) {
		if (interface == NULL)
			return(1);

		if (strcmp(interface, "/dev/ttyUSB0") != 0 &&
			strcmp(interface, "/dev/ttyUSB1") != 0 &&
			strcmp(interface, "/dev/ttyUSB2") != 0)
			return(1);

		list_dlts();

		return(0);
	}

	return(1);
}

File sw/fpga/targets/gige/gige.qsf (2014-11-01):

# -------------------------------------------------------------------------- #
#
# Copyright (C) 1991-2014 Altera Corporation. All rights reserved.
# Your use of Altera Corporation's design tools, logic functions 
# and other software and tools, and its AMPP partner logic 
# functions, and any output files from any of the foregoing 
# (including device programming or simulation files), and any 
# associated documentation or information are expressly subject 
# to the terms and conditions of the Altera Program License 
# Subscription Agreement, the Altera Quartus II License Agreement,
# the Altera MegaCore Function License Agreement, or other 
# applicable license agreement, including, without limitation, 
# that your use is for the sole purpose of programming logic 
# devices manufactured by Altera and sold by Altera or its 
# authorized distributors.  Please refer to the applicable 
# agreement for further details.
#
# -------------------------------------------------------------------------- #
#
# Quartus II 64-Bit
# Version 14.0.2 Build 209 09/17/2014 SJ Web Edition
# Date created = 12:57:30  October 31, 2014
#
# -------------------------------------------------------------------------- #
#
# Notes:
#
# 1) The default values for assignments are stored in the file:
#		gige_assignment_defaults.qdf
#    If this file doesn't exist, see file:
#		assignment_defaults.qdf
#
# 2) Altera recommends that you do not modify this file. This
#    file is updated automatically by the Quartus II software
#    and any changes you make may be lost or overwritten.
#
# -------------------------------------------------------------------------- #



# Project-Wide Assignments
# ========================
set_global_assignment -name ORIGINAL_QUARTUS_VERSION "12.0 SP2"
set_global_assignment -name PROJECT_CREATION_TIME_DATE "19:44:15  DECEMBER 28, 2012"
set_global_assignment -name LAST_QUARTUS_VERSION 14.0
set_global_assignment -name PROJECT_OUTPUT_DIRECTORY output
set_global_assignment -name SMART_RECOMPILE ON
set_global_assignment -name VERILOG_FILE top.v
set_global_assignment -name VERILOG_FILE gmii_bridge.v
set_global_assignment -name VERILOG_FILE gmii_rx_to_fifo.v
set_global_assignment -name VERILOG_FILE gmii_fifo_to_tx.v
set_global_assignment -name VERILOG_FILE gmii_log_rx.v
set_global_assignment -name QIP_FILE fifo_packet.qip
set_global_assignment -name QIP_FILE fifo_log_meta.qip
set_global_assignment -name QIP_FILE fifo_log_data.qip
set_global_assignment -name QIP_FILE pll_gmii.qip
set_global_assignment -name QIP_FILE ddio_gtx_clk.qip
set_global_assignment -name SDC_FILE gige.sdc
set_global_assignment -name VERILOG_FILE ../../common/usb3/usb2_ep.v
set_global_assignment -name VERILOG_FILE ../../common/usb3/usb2_ep0.v
set_global_assignment -name VERILOG_FILE ../../common/usb3/usb2_crc.v
set_global_assignment -name VERILOG_FILE ../../common/usb3/usb2_protocol.v
set_global_assignment -name VERILOG_FILE ../../common/usb3/usb2_packet.v
set_global_assignment -name VERILOG_FILE ../../common/usb3/usb2_ulpi.v
set_global_assignment -name VERILOG_FILE ../../common/usb3/usb2_top.v
set_global_assignment -name QIP_FILE ../../common/usb3/mf_usb2_ep0in.qip
set_global_assignment -name QIP_FILE ../../common/usb3/mf_usb2_ep.qip
set_global_assignment -name QIP_FILE ../../common/usb3/mf_usb2_descrip.qip

# Pin & Location Assignments
# ==========================
set_location_assignment PIN_AG14 -to clk_50
set_location_assignment PIN_J1 -to usb_ulpi_clk
set_location_assignment PIN_J3 -to usb_ulpi_stp
set_location_assignment PIN_G1 -to usb_ulpi_nxt
set_location_assignment PIN_L3 -to usb_ulpi_dir
set_location_assignment PIN_K1 -to usb_ulpi_d[0]
set_location_assignment PIN_K2 -to usb_ulpi_d[1]
set_location_assignment PIN_L2 -to usb_ulpi_d[2]
set_location_assignment PIN_L1 -to usb_ulpi_d[3]
set_location_assignment PIN_M2 -to usb_ulpi_d[4]
set_location_assignment PIN_M1 -to usb_ulpi_d[5]
set_location_assignment PIN_P2 -to usb_ulpi_d[6]
set_location_assignment PIN_P1 -to usb_ulpi_d[7]
set_location_assignment PIN_L4 -to usb_tx_swing
set_location_assignment PIN_M3 -to usb_tx_oneszeros
set_location_assignment PIN_AD5 -to usb_elas_buf_mode
set_location_assignment PIN_AC7 -to usb_id
set_location_assignment PIN_N4 -to usb_phy_reset_n
set_location_assignment PIN_V5 -to usb_phy_status
set_location_assignment PIN_Y2 -to usb_pipe_pclk
set_location_assignment PIN_AE3 -to usb_pipe_rx_data[15]
set_location_assignment PIN_AF3 -to usb_pipe_rx_data[14]
set_location_assignment PIN_AE4 -to usb_pipe_rx_data[13]
set_location_assignment PIN_AD3 -to usb_pipe_rx_data[12]
set_location_assignment PIN_AA3 -to usb_pipe_rx_data[11]
set_location_assignment PIN_AC4 -to usb_pipe_rx_data[10]
set_location_assignment PIN_AB3 -to usb_pipe_rx_data[9]
set_location_assignment PIN_Y3 -to usb_pipe_rx_data[8]
set_location_assignment PIN_Y4 -to usb_pipe_rx_data[7]
set_location_assignment PIN_W3 -to usb_pipe_rx_data[6]
set_location_assignment PIN_W4 -to usb_pipe_rx_data[5]
set_location_assignment PIN_V3 -to usb_pipe_rx_data[4]
set_location_assignment PIN_V4 -to usb_pipe_rx_data[3]
set_location_assignment PIN_U4 -to usb_pipe_rx_data[2]
set_location_assignment PIN_U3 -to usb_pipe_rx_data[1]
set_location_assignment PIN_T4 -to usb_pipe_rx_data[0]
set_location_assignment PIN_AC3 -to usb_pipe_rx_datak[1]
set_location_assignment PIN_AD4 -to usb_pipe_rx_datak[0]
set_location_assignment PIN_R4 -to usb_pipe_rx_valid
set_location_assignment PIN_AC1 -to usb_pipe_tx_clk
set_location_assignment PIN_AF2 -to usb_pipe_tx_data[15]
set_location_assignment PIN_AE1 -to usb_pipe_tx_data[14]
set_location_assignment PIN_AD2 -to usb_pipe_tx_data[13]
set_location_assignment PIN_AD1 -to usb_pipe_tx_data[12]
set_location_assignment PIN_AB1 -to usb_pipe_tx_data[11]
set_location_assignment PIN_AB2 -to usb_pipe_tx_data[10]
set_location_assignment PIN_W1 -to usb_pipe_tx_data[9]
set_location_assignment PIN_W2 -to usb_pipe_tx_data[8]
set_location_assignment PIN_V2 -to usb_pipe_tx_data[7]
set_location_assignment PIN_U2 -to usb_pipe_tx_data[6]
set_location_assignment PIN_V1 -to usb_pipe_tx_data[5]
set_location_assignment PIN_U1 -to usb_pipe_tx_data[4]
set_location_assignment PIN_T3 -to usb_pipe_tx_data[3]
set_location_assignment PIN_R2 -to usb_pipe_tx_data[2]
set_location_assignment PIN_R1 -to usb_pipe_tx_data[1]
set_location_assignment PIN_R3 -to usb_pipe_tx_data[0]
set_location_assignment PIN_AE2 -to usb_pipe_tx_datak[1]
set_location_assignment PIN_AC2 -to usb_pipe_tx_datak[0]
set_location_assignment PIN_R5 -to usb_power_down[1]
set_location_assignment PIN_R7 -to usb_power_down[0]
set_location_assignment PIN_AB5 -to usb_pwrpresent
set_location_assignment PIN_N3 -to usb_rate
set_location_assignment PIN_AB6 -to usb_reset_n
set_location_assignment PIN_R6 -to usb_rx_elecidle
set_location_assignment PIN_AC5 -to usb_rx_polarity
set_location_assignment PIN_AA6 -to usb_rx_status[2]
set_location_assignment PIN_Y6 -to usb_rx_status[1]
set_location_assignment PIN_V7 -to usb_rx_status[0]
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

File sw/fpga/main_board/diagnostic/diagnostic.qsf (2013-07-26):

# -------------------------------------------------------------------------- #
#
# Copyright (C) 1991-2012 Altera Corporation
# Your use of Altera Corporation's design tools, logic functions 
# and other software and tools, and its AMPP partner logic 
# functions, and any output files from any of the foregoing 
# (including device programming or simulation files), and any 
# associated documentation or information are expressly subject 
# to the terms and conditions of the Altera Program License 
# Subscription Agreement, Altera MegaCore Function License 
# Agreement, or other applicable license agreement, including, 
# without limitation, that your use is for the sole purpose of 
# programming logic devices manufactured by Altera and sold by 
# Altera or its authorized distributors.  Please refer to the 
# applicable agreement for further details.
#
# -------------------------------------------------------------------------- #
#
# Quartus II 32-bit
# Version 12.1 Build 243 01/31/2013 Service Pack 1 SJ Web Edition
# Date created = 23:26:13  May 25, 2013
#
# -------------------------------------------------------------------------- #
#
# Notes:
#
# 1) The default values for assignments are stored in the file:
#		diagnostic_assignment_defaults.qdf
#    If this file doesn't exist, see file:
#		assignment_defaults.qdf
#
# 2) Altera recommends that you do not modify this file. This
#    file is updated automatically by the Quartus II software
#    and any changes you make may be lost or overwritten.
#
# -------------------------------------------------------------------------- #


set_global_assignment -name FAMILY "Cyclone IV E"
set_global_assignment -name DEVICE EP4CE30F29C8
set_global_assignment -name TOP_LEVEL_ENTITY diagnostic
set_global_assignment -name ORIGINAL_QUARTUS_VERSION "12.1 SP1"
set_global_assignment -name PROJECT_CREATION_TIME_DATE "23:26:13  MAY 25, 2013"
set_global_assignment -name LAST_QUARTUS_VERSION "12.1 SP1"
set_global_assignment -name PROJECT_OUTPUT_DIRECTORY output_files
set_global_assignment -name MIN_CORE_JUNCTION_TEMP 0
set_global_assignment -name MAX_CORE_JUNCTION_TEMP 85
set_global_assignment -name DEVICE_FILTER_PIN_COUNT 780
set_global_assignment -name DEVICE_FILTER_SPEED_GRADE 8
set_global_assignment -name ERROR_CHECK_FREQUENCY_DIVISOR 1
set_global_assignment -name STRATIX_DEVICE_IO_STANDARD "1.8 V"
set_global_assignment -name PARTITION_NETLIST_TYPE SOURCE -section_id Top
set_global_assignment -name PARTITION_FITTER_PRESERVATION_LEVEL PLACEMENT_AND_ROUTING -section_id Top
set_global_assignment -name PARTITION_COLOR 16764057 -section_id Top
set_location_assignment PIN_R28 -to SPI_MOSI
set_location_assignment PIN_R26 -to SPI_SCK
set_location_assignment PIN_R25 -to SPI_SS
set_instance_assignment -name IO_STANDARD "1.8 V" -to SPI_MOSI
set_instance_assignment -name IO_STANDARD "1.8 V" -to SPI_SCK
set_instance_assignment -name IO_STANDARD "1.8 V" -to SPI_SS
set_location_assignment PIN_C27 -to FE_A[41]
set_location_assignment PIN_G28 -to FE_A[40]
set_location_assignment PIN_D28 -to FE_A[39]
set_location_assignment PIN_D27 -to FE_A[37]
set_location_assignment PIN_E28 -to FE_A[35]
set_location_assignment PIN_K28 -to FE_A[34]
set_location_assignment PIN_F28 -to FE_A[33]
set_location_assignment PIN_L27 -to FE_A[32]
set_location_assignment PIN_F27 -to FE_A[31]
set_location_assignment PIN_L28 -to FE_A[30]
set_location_assignment PIN_D24 -to FE_A[29]
set_location_assignment PIN_C26 -to FE_A[28]
set_location_assignment PIN_E24 -to FE_A[27]
set_location_assignment PIN_D26 -to FE_A[26]
set_location_assignment PIN_F24 -to FE_A[25]
set_location_assignment PIN_D25 -to FE_A[24]
set_location_assignment PIN_G24 -to FE_A[23]
set_location_assignment PIN_E26 -to FE_A[22]
set_location_assignment PIN_H24 -to FE_A[21]
set_location_assignment PIN_E25 -to FE_A[20]
set_location_assignment PIN_H25 -to FE_A[19]
set_location_assignment PIN_F26 -to FE_A[18]
set_location_assignment PIN_J24 -to FE_A[17]
set_location_assignment PIN_F25 -to FE_A[16]
set_location_assignment PIN_L24 -to FE_A[15]
set_location_assignment PIN_G26 -to FE_A[14]
set_location_assignment PIN_L25 -to FE_A[13]
set_location_assignment PIN_G25 -to FE_A[12]
set_location_assignment PIN_M24 -to FE_A[11]
set_location_assignment PIN_H26 -to FE_A[10]
set_location_assignment PIN_G23 -to FE_A[9]
set_location_assignment PIN_J26 -to FE_A[8]
set_location_assignment PIN_H23 -to FE_A[7]
set_location_assignment PIN_J25 -to FE_A[6]
set_location_assignment PIN_J23 -to FE_A[5]
set_location_assignment PIN_K26 -to FE_A[4]
set_location_assignment PIN_L23 -to FE_A[3]
set_location_assignment PIN_K25 -to FE_A[2]
set_location_assignment PIN_M23 -to FE_A[1]
set_location_assignment PIN_L26 -to FE_A[0]
set_location_assignment PIN_E15 -to FE_B[51]
set_location_assignment PIN_E17 -to FE_B[50]
set_location_assignment PIN_G16 -to FE_B[49]
set_location_assignment PIN_J17 -to FE_B[48]
set_location_assignment PIN_F15 -to FE_B[47]
set_location_assignment PIN_H16 -to FE_B[46]
set_location_assignment PIN_G18 -to FE_B[45]
set_location_assignment PIN_H17 -to FE_B[44]
set_location_assignment PIN_F17 -to FE_B[43]
set_location_assignment PIN_E21 -to FE_B[42]
set_location_assignment PIN_D17 -to FE_B[41]
set_location_assignment PIN_F21 -to FE_B[40]
set_location_assignment PIN_C21 -to FE_B[38]
set_location_assignment PIN_D19 -to FE_B[36]
set_location_assignment PIN_E18 -to FE_B[35]
set_location_assignment PIN_G20 -to FE_B[34]
set_location_assignment PIN_A17 -to FE_B[33]
set_location_assignment PIN_C15 -to FE_B[32]
set_location_assignment PIN_B17 -to FE_B[31]
set_location_assignment PIN_D15 -to FE_B[30]
set_location_assignment PIN_A18 -to FE_B[29]
set_location_assignment PIN_C16 -to FE_B[28]
set_location_assignment PIN_B18 -to FE_B[27]
set_location_assignment PIN_D16 -to FE_B[26]
set_location_assignment PIN_D22 -to FE_B[25]
set_location_assignment PIN_G21 -to FE_B[24]
set_location_assignment PIN_A19 -to FE_B[23]
set_location_assignment PIN_C18 -to FE_B[22]
set_location_assignment PIN_B19 -to FE_B[21]
set_location_assignment PIN_D18 -to FE_B[20]
set_location_assignment PIN_A21 -to FE_B[19]
set_location_assignment PIN_D20 -to FE_B[18]
set_location_assignment PIN_B21 -to FE_B[17]
set_location_assignment PIN_C19 -to FE_B[16]
set_location_assignment PIN_A22 -to FE_B[15]
set_location_assignment PIN_C20 -to FE_B[14]
set_location_assignment PIN_B22 -to FE_B[13]
set_location_assignment PIN_D21 -to FE_B[12]
set_location_assignment PIN_A23 -to FE_B[11]
set_location_assignment PIN_C22 -to FE_B[10]
set_location_assignment PIN_B23 -to FE_B[9]
set_location_assignment PIN_C23 -to FE_B[8]
set_location_assignment PIN_A25 -to FE_B[7]
set_location_assignment PIN_D23 -to FE_B[6]
set_location_assignment PIN_B25 -to FE_B[5]
set_location_assignment PIN_C24 -to FE_B[4]
set_location_assignment PIN_A26 -to FE_B[3]
set_location_assignment PIN_C25 -to FE_B[2]
set_location_assignment PIN_B26 -to FE_B[1]
set_location_assignment PIN_E22 -to FE_B[0]
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

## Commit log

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2013-01-28 hardware update including last minute gig-e corrections
    [gig-e.kicad_pcb]
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2013-01-31 Changed NSMD pad diameter and solder mask clearance for TI TUSB1310A footprint, according to TI document SSYZ015B.pdf "MicroStar BGA Packaging Reference Guide".
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2013-01-31 Extract shared code from BGA pad generator scripts. Simplify BGA pad generator scripts. Adjusted Altera F780 footprint to larger NSMD pad size, and updated solder mask clearance to 0.075mm.
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2013-02-01 Initial dump of schematic, in progress. Initial dump of board, mocked up for FPGA pinning and general sanity-checking for PCB design rules.
    [ddr2.sch, ddr2_power.sch, fpga_ddr2.sch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]
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2013-02-09 Considerable rework of DDR2 routing. Unwired USB1 interface, since it will eventually turn into USB0 and move to the other side of the FPGA. Added some amount of USB configuration circuitry.
    [ddr2.sch, fpga_ddr2.sch, fpga_usb1.sch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]
2013-02-09 Undid USB 3.0 routing. Preliminary DDR2 routing, testing for continuity and pin-swapping opportunities. Still a bunch of non-DQ/DQS signals need to be placed and routed.
    [main_board.brd]
2013-02-26 Renamed USB1* schematics to USB0. Moved USB IC to bank 6 of FPGA. Routed USB PIPE TX and RX buses. Added FPGA configuration schematic block. Configured FPGA for passive serial boot only (and JTAG). U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
    [ddr2.sch, ddr2_power.sch, fpga_configuration.sch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]
2013-02-28 Sheet number changed on one of the schematics. No idea why. KiCAD?!
    [fpga_configuration.sch]
2013-02-28 Removed .brd POLYSCORNERS, as it's just noise in the board's source. Hopefully, I'll remember to do that in future commits.
    [main_board.brd]
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2013-03-06 Fix hierarchal port direction for USB0 configuration/status pins -- both in the sheet symbol and schematic. Set resistance for pull-downs for USB0 RESET and OUT_ENABLE. Place 1U cap on TUSB1310A M14,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
    [main_board.sch, usb0_configuration.sch, usb0_power.sch]
2013-03-06 Redraw board outline to reflect 100mm x 100mm goal for main board size. ...and some other stuff I lost track of, or KiCAD just changed/reordered arbitrarily. :-(
    [main_board.brd]
2013-03-06 Pushed USB PIPE traces on inner-top layer to the bottom layer -- effectively eliminated via stubs (but added via inductance), added a bit of length to those traces, and put them on a faster, outside 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
    [main_board.brd]
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2013-03-07 Massive reworking of USB 3.0 signals. I think I'm finally done monkeying with the RX PIPE side, and have evolved a satisfactory method for serpentine traces.
    [ddr2.sch, ddr2_power.sch, fpga_ddr2.sch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]
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2013-03-09 Added QTH-090 library (symbol) to schematics. Added front-end connector and FPGA bank schematics and top-level wiring. Initial routing of front-end connector "bank 1" to the FPGA. Very small aestheti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
    [ddr2.sch, ddr2_power.sch, fpga_ddr2.sch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]
2013-03-09 Initial pin assignment and routing of front-end bank 0. Fixed copyright/license on new schematic sheets.
    [fpga_front_end_bank_0.sch, fpga_front_end_bank_1.sch, fpga_front_end_misc.sch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]
2013-03-09 Reordering and rerouting high-speed signals to front-end connector. Got one more signal per bank along the outside (faster) layers. Still not quite what I want for USB 3.0, but probably acceptable.
    [fpga_front_end_bank_0.sch, fpga_front_end_bank_1.sch, main_board.brd]
2013-03-11 Reworked the front-end connector signals yet again. Trying to minimize trace lengths for as many traces as possible, increasing the length of other nets. Added a few top-level schematic placeholder p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
    [ddr2.sch, ddr2_power.sch, fpga_ddr2.sch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]
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2013-03-11 Added and cleaned-up power network in schematic. Placed VCCIO regulators and components near front-end connector.
    [ddr2.sch, ddr2_power.sch, fpga_configuration.sch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]
2013-03-11 Added IPC-7351 footprints for most common 0402 capacitors and resistors, updated .cmp file. Explicitly wired VREF pins on DDR2 banks, to avoid using them for high-speed signals. Fixed formatting of a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
    [ddr2.sch, fpga_ddr2.sch, fpga_front_end_bank_0.sch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]
2013-03-11 Added a bunch of VCCIO bypass capacitors and tentatively placed them on the board.
    [fpga_front_end_bank_0.sch, fpga_front_end_bank_1.sch, main_board.brd]
2013-03-12 Blocked use of VREF on main board USB bank, as the pins are "slow" due to extra capacitance. Had to move one TX PIPE signal off a VREF pin. Connected VCCIO to main board USB. Connectoed DDR2 CLK* pin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
    [ddr2_power.sch, fpga_ddr2.sch, fpga_front_end_bank_0.sch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]
2013-03-15 Added on-board ULPI signals for routing to DDR2 side bank. Added lots of bypass capacitors. (This was something I should've done much earlier, and I know better!) Attempting to route config/status US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
    [fpga_ddr2.sch, fpga_power.sch, main_board.brd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]
2013-03-18 Added footprints for 0603 inductor, standard 5.0 x 3.2 mm crystal. Added symbol for grounding pads on 4-pin crystal/oscillator. Added USB power supply filtering, bypass caps. Moved TUSB1310A VSSOSC p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
    [ddr2.sch, ddr2_power.sch, fpga_configuration.sch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]
2013-03-19 Layout of crystal section for TUSB1310A. Further work on front-end connector pin-out and power supplies.
    [front_end.sch, main_board.brd, usb0_configuration.sch]
2013-03-22 Consolidated DDR power into DDR schematic block. Reworked front end connector pinning and power scheme. Misc clean-up on power sections. Added microcontroller sheet.
    [ddr2.sch, ddr2_power.sch, fpga_configuration.sch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]
2013-03-23 Add micro USB shield pin and name for EMI.
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2013-03-23 Fleshed out microcontroller on a new schematic sheet. Added (still empty) clock generator sheet.
    [clock_generator.sch, ddr2.sch, fpga_configuration.sch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]
2013-03-23 Renamed and reworked BGA footprints according to IPC recommendations.
    [main_board.brd, microcontroller.sch]
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2013-03-23 Fix up footprint library references for libraries renamed to IPC standard.
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2013-03-24 Fleshed out clock generator schematic. Revised some power and clock distribution stuff. Renamed a couple of USB0 config signals to match TUSB1310A names.
    [clock_generator.sch, ddr2.sch, fpga_configuration.sch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]
2013-03-24 More clean-up... DDR2 non-data signals wired on top sheet. Connected MCU clock output to an otherwise-unused FPGA clock input. Additional clock generator connections to FPGA clock inputs. Renamed she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
    [fpga_configuration.sch, fpga_ddr2.sch, fpga_front_end_bank_0.sch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]
2013-03-25 Fleshed out switching regulator for V3P3 and V1P8. Drew up speculative FET switching circuit for front end -> FPGA VCCIO control. Not thrilled with the concept...
    [clock_generator.sch, ddr2.sch, fpga_configuration.sch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]
2013-03-27 A bit more power distribution work and renaming of nets -- making things a bit more explicit.
    [clock_generator.sch, ddr2.sch, fpga_configuration.sch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]
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2013-04-02 Review and clean-up of voltage supply architecture and clocking. Simplified top-level schematic by moving power nets into global labels. Moved and re-routed USB 3.0 interface IC (TUSB1310A) to bank 2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
    [clock_generator.sch, ddr2.sch, fpga_configuration.sch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]
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2013-04-05 Almost successful routing of FPGA-to-DDR2 signals. Then I ran into SSN (signal switching noise?) issues, so I'll need to move some signals out of overused VREF groups. ARGHHHHH!
    [clock_generator.sch, fpga_ddr2.sch, fpga_usb0.sch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]
2013-04-07 Re-mapping and re-routing DDR2 to deal with ALTMEMPHY errors. Now, Quartus seems happy at 125MHz memory clock rate.
    [ddr2.sch, fpga_ddr2.sch, main_board.brd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]
2013-04-07 Converted to eight layers. Moved some power planes and routing to new layers. Fixed a couple of orphaned power pins on the TUSB1310A.
    [main_board.brd]
2013-04-07 Cleaning up DDR2 VREF topology. Cleaning up FPGA VREFs for front end banks.
    [ddr2.sch, fpga_ddr2.sch, fpga_front_end_bank_0.sch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]
2013-04-07 Swapped FPGA banks going to the front end to match rotated connector. Flipped supplies on front end connector "misc" bank.
    [clock_generator.sch, ddr2.sch, fpga_configuration.sch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]
2013-04-09 Re-routed front end bank C. Achieved 83 ps skew across all signals, maximum trace length is 23.7mm. No more than two vias per signal.
    [fpga_front_end_bank_b.sch, fpga_front_end_bank_c.sch, main_board.brd]
2013-04-09 Fixed a few swapped differential pairs and mis-routed wires on front end bank C.
    [fpga_front_end_bank_c.sch, main_board.brd]
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2013-04-11 Tweaks to clock generator. Routing of clock generator outputs to FPGA. Routing of front end bank A.
    [clock_generator.sch, ddr2.sch, fpga_configuration.sch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]
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2013-04-12 Fixed surprise escaping in comment.
    [power.sch]
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2013-04-12 MicroSD hooked up to microcontroller. Removed regulated supplies from front end connector, replaced with unregulated voltage.
    [clock_generator.sch, ddr2.sch, fpga_configuration.sch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]
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2013-04-13 Modified QUARTZCMS4_GROUND ground pin types to correct ERC warnings.
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2013-04-13 Altered TUSB1310A symbol VSSOSC pin type to correct ERC warning.
2013-04-13 Improved supply (inductors) to clock generator. USB 2.0 ESD protection. Added 0 Ohm resistor to support TUSB1310 (non-A) version. Default switching for VCCIOs connected to the front end banks. Switch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
    [clock_generator.sch, ddr2.sch, fpga_configuration.sch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]
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2013-04-13 Removed garbage remaining from TUSB1310A VSSOSC pin part/unit move. Labeling power supply blocks. Added main board barrel jack to schematic. Connect DDR2 SA[1..0] (SPD I2C address) to microcontroller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
    [clock_generator.sch, ddr2.sch, fpga_configuration.sch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]
2013-04-13 Footprints for 74LVC2T45, MIC5207, TPS27081A. Fixed "clever" but ultimately misguided pinout on TPS27081A symbol.
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2013-04-14 Assorted component/value clean-up. Assorted footprint assignment. Values and tolerances for LDO regulator voltage resistors. Requirement attributes for switcher components. Manufacturer and part numb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
    [clock_generator.sch, ddr2.sch, fpga_configuration.sch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]
2013-04-14 Imported miscellaneous footprints from HackRF. New footprint for DC power jack. New footprint for 0805 inductor (e.g. ferrite bead). Mounting holes. Symbol for mounting holes so pcbnew doesn't clean 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
    [clock_generator.sch, ddr2.sch, fpga_configuration.sch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]
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2013-04-15 More component/footprint mapping and fixing. Assigning BOM details to reference designators.
    [clock_generator.sch, ddr2.sch, fpga_configuration.sch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]
2013-04-15 Add USB configuration port ESD protection. Resistor BOM data. A few component value adjustments. Removing a few now-irrelevant comments. Replaced inductors with ferrite beads in supply filters. Added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
    [clock_generator.sch, ddr2.sch, fpga_configuration.sch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]
2013-04-15 Removed duplicate pull-down resistors on VCCIO_DEFAULT_EN. Removed current-sense jumpers for the more boring voltage supplies.
    [clock_generator.sch, ddr2.sch, fpga_configuration.sch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]
2013-04-15 Significant change in layout of power and microcontroller sections, trying to get everything on the board in a somewhat rational location. Still in progress, but starting to look good...
    [main_board.brd]
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2013-04-16 More work on power planes and distribution. Enlarged power traces on front end. Swapped SD card detect pins to simplify routing. Fixed ordering of FPGA PLL ferrite and capacitors. Fixed sense of labe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
    [clock_generator.sch, ddr2.sch, fpga_configuration.sch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]
2013-04-16 Moved TDO and SPI_MISO level shifter to microcontroller sheet, so I can pull those signals from separate FPGA banks/sheets. Put no-connection markers on some FPGA pins to quiet some DRC noise.
    [fpga_configuration.sch, fpga_front_end_bank_b.sch, fpga_front_end_bank_c.sch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]
2013-04-17 More microcontroller control signal hook-up: DDR2 SPD, V1P8 regulator. Swapped I2C and VALT_FE pins on front end connector. Selected Schottky diodes, created package and specified in schematic/CvPCB.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
    [front_end.sch, main_board.brd, microcontroller.sch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]
2013-04-18 Fixed power plane clearance on VUSB. Added duplicate V1P8 and front end VCCIO planes to pair with the other ground plane. Otherwise, it's not really 50 Ohms, is it? Lots of other power plane tweaks a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
    [main_board.brd]
2013-04-19 Miscellaneous pin-swapping for signals to the microcontroller. Moved uC <-> FPGA SPI interface to FPGA bank 5. Relocated I2C pins on FPGA to route to DDR2 socket, to uncrowd the routing region betwee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
    [clock_generator.sch, ddr2.sch, fpga_configuration.sch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]
2013-04-20 Fixed dangling RESET# pull-up resistor. Routed surface mount SWD connector. Swapped signals going through level shifter again, to clean up tight routing under microcontroller. Assorted comments, nami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
    [clock_generator.sch, ddr2.sch, fpga_ddr2.sch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]
2013-04-21 Added PCB construction notes: layer stack, silkscreen clip. Removed mounting hole at the center of the right edge of the PCB. Deleted copper ground pours on bottom side -- they serve no practical pur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
    [main_board.brd, main_board.sch]
2013-04-21 Add pre-release comments to silkscreen and top/bottom copper and to PCB document, for quoting by PCB vendors. Add USB 3.0 ID pin support. Add project name/URL, release date, handwriting silkscreen bl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
    [fpga_front_end_bank_b.sch, fpga_usb0.sch, main_board.brd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]
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2013-04-22 Added rounded PCB corners for Sick of Beige compatibility. Added keep-out silkscreen for mounting holes, per SoB recommendation. Moved a few traces, vias, and zones to provide more clearance for moun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
    [main_board.brd]
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2013-04-25 Adjusted solder mask clearance to 3mil, after deciding Sunstone's +/-5mil tolerance would result in an acceptable 2mil worst-case encroachment.
    [main_board.brd]
2013-04-25 Adjusted DRC minimum trace width to 5mil. Fixed some net class grouping issues.
    [main_board.brd]
2013-04-26 Swapped two pins on DDR2 interface to improve matching of routing distances. Did extensive trace delay matching on DDR2. Still not ideal, but skew across all signals should be <100ps.
    [fpga_ddr2.sch, main_board.brd]
2013-04-26 Fixed up a few 50 Ohm traces with the wrong width.
    [main_board.brd]
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2013-05-01 Correct typos in GigE pin names
    [gige.qsf]
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2013-05-02 Moved R6 to not interfere with DDR2 socket. Had to replace a ground via.
    [main_board.brd]
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2013-05-02 Corrected incorrect imperial unit 50 Ohm trace width on bottom layer.
2013-05-07 Made a bit more room between CLOCKGEN_OEB# and FE_I2C_SDA, to address DRC (due to rounding error?) in KiCAD -testing.
    [main_board.brd]
2013-05-07 Corrected design rules to match newer layer stack: minimum trace of 6.5mil, minimum clearance, 5.0mil. Altered 50 Ohm traces to new layer stack widths. Fixed up some non-50 Ohm traces that needed wid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
    [main_board.brd]
2013-05-07 Updated main board README with layer stack changes, affected materials, layer thicknesses, 50 Ohm trace widths. Specified board thickness tolerance (before, I just said "approximately"). Clarified fr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
2013-06-05 Changed usb2_top interface to remove the data inout signal in favor of separate in/out/oe signals. This permits simpler control of signals at strapping (USB PHY reset) time. Updated RS232 target proj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
2013-07-22 Rework reset switch capture.
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2013-07-22 Fix small amount of commit-breakage from me trying to separate my commits.
    [gige.qsf]
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2013-12-05 usb3: bulk transfers, major bug fixes
    [usb3_descramble.v, usb3_ep0.v, usb3_link.v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]
2014-01-14 usb3: more error handling and milestone 29
    [usb3_link.v, usb3_ltssm.v]
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2014-10-15 Corrected pin numbering on 2x5 0.05" Sullins connector. (Used ARM for SWD/JTAG).
2014-10-15 Corrected pin numbering on Sullins 4x2 0.05" header (used for FPGA JTAG and microcontroller serial).
2014-10-15 Correct USB 3.0 micro-AB symbol to incorporate USB 3.0 ECN 017 change to Table 5-6 "USB 3.0 Micro-AB/-A Connector Pin Assignments". SSRX and SSTX pairs were reversed.
2014-10-15 Fixed pad positions on TE-1473005-4 DDR2 SO-DIMM socket.
2014-10-15 Swap USB 3.0 SS TX/RX pairs, and wire them straight through (because swapping +/- for routing is no longer necessary). Rearrange USB signal connections to USB protection ICs.
    [usb0_interfaces.sch]
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2014-10-15 Fixed SS TX/RX swapped pairs on USB 3.0 connector. Moved USB 3.0 connector to "front" of board and cleaned up routing. Fixed DDR2 footprint and related routing. Reworked power routing near power conn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
    [main_board.brd]
2014-10-15 Replaced non-standard FPGA JTAG connector with Altera-style. Terminated microcontroller RXD/TXD with test points, since they no longer go to the JTAG connector. Moved general-purpose switch signal to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
    [microcontroller.sch]
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2014-10-15 Updated usb project to Kicad bar 4730, fixed lots of library breakage. Removed _fe_map schematics, made mapping between FE connector pins and USB PHY chip more direct. Much assorted clean-up and chan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
    [main_board_if.sch, power.sch, usb.sch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]
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2014-10-15 Reverse LEDs attached to I/O expander -- sink current is higher than source. Note I/O expander I2C addresses. Specify TCA6416A package type "PW". Miscellaneous design notes. I/O expander I2C pull-ups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
    [main_board_if.sch, usb1_interfaces.sch]
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2014-10-15 PCB: Delete extra nets/traces, fix DRC errors, add "do not manufacture" silkscreen.
    [usb.kicad_pcb]
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2014-10-15 PCB: Final clean-up
    HSMC grounding tweaks.
    Connect a ground island (still served by other ground plane, but...).
    Add clearance to some copper pours.
    Remove "DO NOT MANUFACTURE".
    Update PCB date code.
    [usb.kicad_pcb]
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2014-10-15 Main board: Schematic format update, cleanup from 20140113 build.
    Two LDO regulator noise capacitors (470p) removed, as it was making regulation unstable.
    [clock_generator.sch, ddr2.sch, fpga_configuration.sch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]
2014-10-15 Rework RS-232 target project for new front-end board.
2014-10-15 MCU: Fix Si5351C init, all FPGA clocks now 50MHz.
    [si5351c.c]
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2014-10-15 corrected part numbers
    [board_power.sch, hdmi.sch, hdmi_input.sch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]
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2014-10-16 added 5 V regulator, fixed up ESD sections
    [board_power.sch, hdmi.sch, hdmi_input.sch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]
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2014-10-17 reworked input equalizer section
    [hdmi_input.sch, hdmi_mezz.sch]
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2014-10-22 corrected some ERC errors
    [board_power.sch, hdmi_input.sch, hdmi_mezz.sch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]
2014-10-26 corrected PHY pin 16: AVDDH, not AVDDL
    [daisho_connector.sch, gig-e-phy0.sch, gig-e-phy1.sch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]
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2014-10-26 connect PHYAD2 through 10k resistors to allow strapping without interfering with clock function
    [daisho_connector.sch, gig-e-phy0.sch, gig-e-phy1.sch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]
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2014-10-27 changed to correct QSH footprint, removed PHYAD2 connections (pull-downs are good enough)
    [daisho_connector.sch, gig-e-phy0.sch, gig-e-phy1.sch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]
2014-10-27 corrected ISET resistor value
    [gig-e-phy0.sch, gig-e-phy1.sch]
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2014-10-28 corrected units in footprint
    [board_power.sch, hdmi_mezz.sch]
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2014-10-28 reverted to smaller minimums
    [hdmi.kicad_pcb]
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2014-11-01 rs232: updated to correct QSH footprint
    [rs232_fe.kicad_pcb]
2014-11-01 rs232: corrected DB9 footprints
    [rs232_fe.kicad_pcb]
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2014-11-02 corrected SD_CH3_TXCLK name to SD_CH2_TXCLK
    [hdmi_mezz.sch, serdes_io.sch]
2014-11-02 corrected order of SD_CHx_RX[7:0] and SD_CHx_TX[7:0]
    [hdmi.kicad_pcb, hdmi_mezz.sch, serdes_io.sch]
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2014-11-03 hdmi: fixed some bad footprints
    [hdmi.kicad_pcb, hdmi_input.sch, hdmi_output.sch]
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2014-11-03 hdmi: fixed up Si5338 footprint
    [hdmi.kicad_pcb]
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2014-11-06 usb: paste clearance
    [usb.kicad_pcb]
2015-01-27 updated QFNs to module with corrected paste layer
    [gige_fe.kicad_pcb]
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2015-02-13 made small headers DNP, made R63 not DNP, fixed J1 bom info
    [daisho_connector.sch, rs232_fe.sch, rs232_pair_AB.sch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]
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2015-02-27 fixed bom info
    [daisho_connector.sch, gig-e-phy0.sch, gig-e-phy1.sch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]
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2015-04-09 mainboard: replaced SW1 obsolete part number
    [microcontroller.sch]

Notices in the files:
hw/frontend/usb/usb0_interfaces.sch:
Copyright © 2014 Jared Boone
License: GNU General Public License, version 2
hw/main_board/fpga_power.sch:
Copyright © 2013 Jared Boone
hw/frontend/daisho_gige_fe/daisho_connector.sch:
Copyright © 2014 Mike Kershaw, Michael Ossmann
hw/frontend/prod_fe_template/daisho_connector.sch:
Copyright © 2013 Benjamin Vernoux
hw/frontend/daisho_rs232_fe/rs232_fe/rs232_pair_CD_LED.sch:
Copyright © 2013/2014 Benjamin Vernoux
